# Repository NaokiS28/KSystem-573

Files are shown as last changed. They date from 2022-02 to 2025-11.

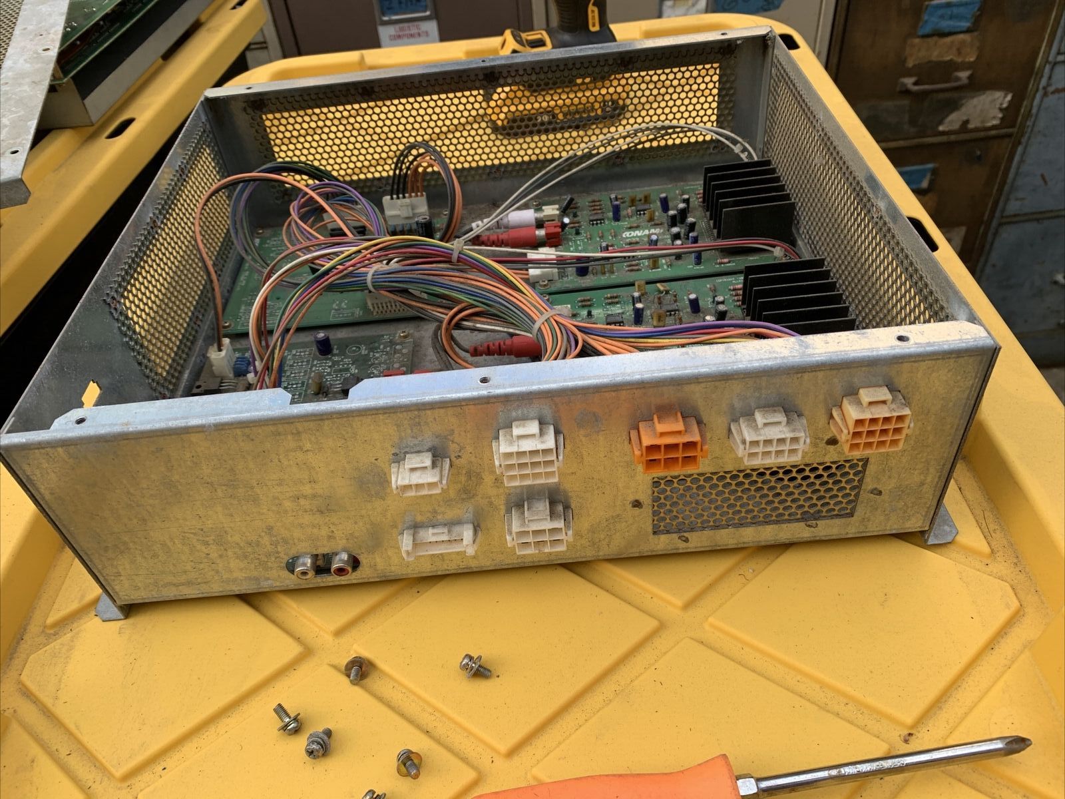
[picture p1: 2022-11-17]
Extra Hardware/DDR Amp Cage/Images/s-l1600-5.jpg

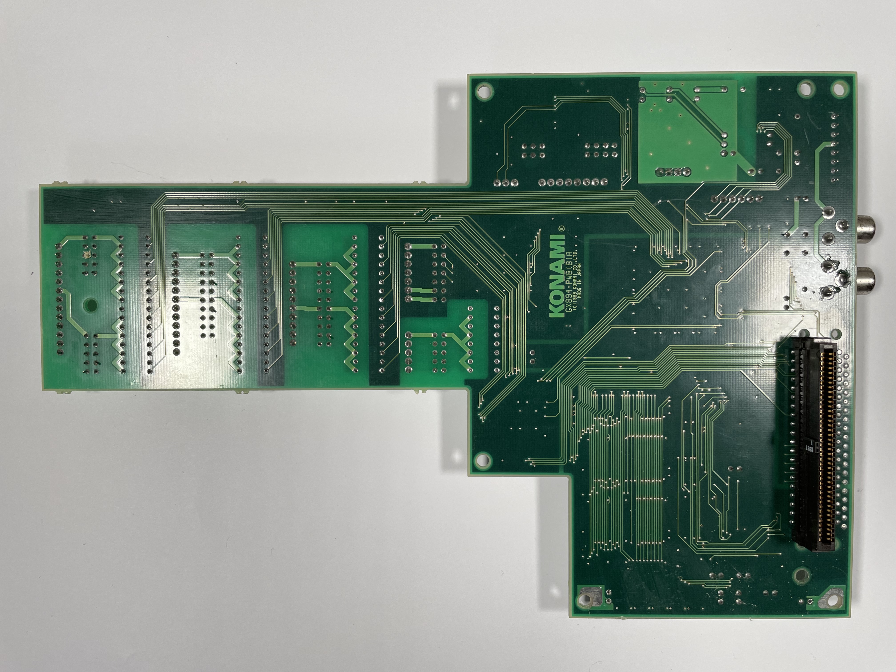
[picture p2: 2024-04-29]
Extra Hardware/Expansion Boards/GX894-PWB(B)A/Images/IMG_5035.jpeg

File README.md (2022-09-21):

# KSystem-573
 Schematics and pinout information for the Konami System 573
 
 **Please note a lot of this data is not 100% complete and might be incorrect in places.** Also this repository needs to be generally organised better.
 
## Schematics
 Schematics are in KiCad format and are preliminary. Currently known issues:
 * The PSX portion is not mapped out. This is the same as the regular PS1 CPU, GPU and SPU schematics with the exception of more work and GPU RAM.
 * The CPLD is mostly but not fully mapped out.
 * The security cart needs verifying and labeling correctly.
 * In general the schematics need tidying up.
 * The Konami 056789 ASIC needs a symbol creating. It's a 6x 16-Bit input and 1x 8-bit output latch really, probably has some 74 series dies on the inside.
 * IO boards are somewhat documented but in varying stages of completeness.

## PCB Layout
 The mother PCB is not laid out. The intention with this project was not to make a new repro motherboard but to define the schematics and wiring. The outline *should* be correct but it is not 100%. If you feel like creating a PCB layout, submit a PR!

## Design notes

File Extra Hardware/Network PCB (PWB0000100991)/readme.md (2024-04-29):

# Konami Network PCB (e-Amusement) (PWB0000100991)

This is board is a seperate PCB from the 573 that is effectively it's own system. It uses a MIPS SoC with a PCI Ethernet 10/100 controller and a 20GB IDE drive. It connects to the 573 via the bottom PCMCIA slot. It is memory mapped only. This unit is used with the GuitarFreaks and Drummania games from 8th mix onwards (at least ones supporting e-Amuse). This would allow the 573 to use downloaded content from Konami's servers and transfer player data.

The OS is UDEOS, an RTOS which has NetNucleus technology from Toshiba.

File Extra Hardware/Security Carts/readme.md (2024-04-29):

# Konami System 573 Security Carts
This folder lists the security carts that were used in the System 573. The security cart port could be considered as a GPIO bus for the 573, having an 8-bit input port, 8-bit output port, semaphore signaling, bitbanged I2C and SPI and a UART port. As a result, a lot of security cartridges tended to be dual purpose and add extra IO to the 573 without using the internal expansion bus.

There are a few types of case styles with the cartridges:
* No case - Bare PCB, sometimes covered with a seperate cover that screws into the 573's silver metal case or has a bespoke metal case covering bother the 573 and cartridge.
* Small case - Small retangular cartridge with a 45 degree angled top. Used on games that only used basic cartridges. Is the same height as the 573 when installed.
* T-Cart - A larger cartridge that extends taller than the 573 when installed and uses most of the width to the side of the cartridge. Typically used on games requiring extra IO.

## Notes:
* It seems almost all cartridges bridge the 573-RTS and 573-CTS UART port lines. If you require the serial port on the 573, just install any old cart and this is done for you.
* Like a lot of Konami parts, they are typically only populated for what the game needs. This means despite the fact that Dancing Stage EuroMIX 2 uses a GE949-PWB(D)A cartridge, none of the extra parts to support the AMP control or RS232 ports (except the RTS-CTS link) are present. DDR 3rdMIX seems to be a rare exception in this case.
* All carts a fully reprogramable to have *any* other cart data. The only exception is that carts using a Xicor EEPROM can only be used on games expecting a Xicor cart and vice versa with the PIC16C carts, also known as ZS01 carts - That said, some games might be able to use both cart types, but this is not confirmed. Dancing Stage EuroMIX has strange behavoir in that it will inform the operator to label the cart like it would on ZS01 carts, but it does not actually marry the cart.

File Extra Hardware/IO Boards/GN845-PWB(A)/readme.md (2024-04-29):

# GN845-PWB(A) - Relay Board
This PCB is also known as the Relay board sometimes, it is used on DDR/Dancing Stage and possibly other BEMANI games like Drummania and Guitar Freaks.
Update: It appears the board was used in the following games:
* Dance Dance Revolution / Danicng Stage
* Punch Mania / Fighting Mania
* Guitar Freaks
* Drummania

First used with DDR, it has space for two logic inverters for up to 8 channels (altough DDR only has pats for 6 channels) of high current outputs like the 12v halogen spotlamps on the marquee and the 501 lamps in the start and select buttons. The neon tube driver *does not* go through this board, it uses a separate solid-state relay (SSR) to drive the neon transformer.

The secondary logic chip and associated components are not used or populated in DDR. It drives the last two MOSFETs/Darlington pair transistors, a space for lower current drivers using NPN transistors and then finally two opto-isolator outputs. It's not known what these were originally intended for nor if any game would have ever likely used them.

The board is setup to use both N-Channel MOSFETs and NPN Darlington pair transistors, with R9-R16 being the only components needing to be changed. A straight link (0-ohm/wire) is used for MOSFETs and a resistor for NPN Darlington transistors. The board is only designed to handle 12V swtiching. It has an onboard 7805 5V regulator for the logic ICs.

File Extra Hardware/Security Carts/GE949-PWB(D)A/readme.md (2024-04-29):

# GE949-PWB(D)A - Security Cart w/ RS232 Transceiver & Audio amp control
Sometimes known as a T-Cart cart, this PCB is used as both a security cartridge, a galvanically isolated amplifier controller board and an isolated RS232 transceiver for linking units together. It uses a PIC16CE625 MCU as the security device which is often called the ZS01 security chip due to the initial bytes of the internal code at address `0x0000`. This board provides a galvanically isolated 5V supply to the amp control header. It's very similar to the GX896 security cart but also includes a DS2401 serial ID chip to make every security cartridge unique.

## Games used in:
* DDR 4thMIX
* DDR 5thMIX
* DDRMAX
* DDRMAX 2
* DDR Extreme
* Dancing Stage EuroMIX 2
* Almost all BEMANI games post the 3rd quarter of 2000.

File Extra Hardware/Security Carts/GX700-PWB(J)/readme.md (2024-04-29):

# GX700-PWB(J) - Security Cart w/ 8 Channel ADC
This PCB is used as both a security cartridge and analog input expansion board. It uses a Xicor x76F041 password eeprom as the security device. The analogue to digital converter is an ADC0838 which is an 8 channel version of the one used on the 573 motherboard.

## Games used in:
* Fighting Mania
* Punch Mania
* Punch Mania II

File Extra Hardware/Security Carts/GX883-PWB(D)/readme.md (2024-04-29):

# GX896-PWB(A)A - Security Cart w/ RS232 Transceiver & Audio amp control
Sometimes known as a T-Cart cart, this PCB is used as both a security cartridge, a galvanically isolated amplifier controller board and an isolated RS232 transceiver for linking units together. It uses a Xicor x76F041 password eeprom as the security device. This board provides a galvanically isolated 5V supply to the amp control header. It's practically the same as the GX896 security cart but also includes a DS2401 serial ID chip to make every security cartridge unique.

## Games used in:
* DDR 3rdMIX
* GuitarFreaks 2ndMIX 
* Probably other BEMANI digital games prior to late 2000s.

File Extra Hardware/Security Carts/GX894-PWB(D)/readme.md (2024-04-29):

# GX896-PWB(A)A - Security Cart w/ unique serial number
This PCB is used as a security cartridge. It uses a Xicor x76F041 password eeprom as the security device. It also has a DS2401 serial ID chip so that each security cart has a unique ID.

Curiously, in Dancing Stage EuroMIX, it tells the operator to write an 8-digit security number onto the game PCB and the security cart as if it had married the (blank) cart to the motherboard, however it does not actually marry the boards at all. It's not as if it couldn't, it just doesn't seem to or atleast it doesn't lock you out if the cart is used in another board.

## Games used in:
* Dancing Stage EuroMIX

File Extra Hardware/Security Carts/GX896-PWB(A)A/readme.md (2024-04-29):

# GX896-PWB(A)A - Security Cart w/ RS232 Transceiver & Audio amp control
Sometimes known as a clubMIX cart, this PCB is used as both a security cartridge, a galvanically isolated amplifier controller board and an isolated RS232 transceiver for linking units together. It uses a Xicor x76F041 password eeprom as the security device. This board provides a galvanically isolated 5V supply to the amp control header.

## Games used in:
* Drummania
* DDR 2ndMIX with beatmania IIDX club ver.
* DDR 2ndMIX and beatmania IIDX substream CLUB ver. 2

Images provided by BigDadDewg.

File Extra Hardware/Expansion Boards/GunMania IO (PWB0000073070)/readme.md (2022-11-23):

# GunMania IO Board (PWB0000073070)

This is board is the IO board used with GunMania and likely GunMania II. As the game uses real BB bullets and has an actual shooting range, this board serves as mostly a drive board, altough also appears to have a serial port (or maybe ACIO), an a DB25 connector. The board hasn't been documented fully.

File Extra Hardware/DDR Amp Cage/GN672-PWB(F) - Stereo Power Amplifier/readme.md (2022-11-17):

# GN672-PWB(F) - Stereo Audio AMP
This PCB is simply an stereo audio amp. Todo: add specifications. Likely just dual 20w/40w amplifier.

Dance Dance Revolution/Dancing Stage uses two of these PCBs: One for the full range drivers and another for the subwoofers (this amp receives an LFO channel input).

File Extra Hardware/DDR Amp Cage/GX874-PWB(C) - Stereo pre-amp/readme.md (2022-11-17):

# GN874-PWB(C) - Audio Mixing PCB
This PCB is simply an audio mixing PCB. It takes two inputs, merges them together and then splits into two full range outputs (one going to the output of the cabinet at the back) and a stereo LFO channel. The potentiometers for controlling volumes connects to this PCB. There is a 4 pin connector by the inputs that might be another input but it's not known if this was ever used. Also there is a third output which is positioned to be connected to another GN672 amplifier but it's not populated on most boards.

It's using basic NE5532 circuits powered from a 7805 5V regulator.

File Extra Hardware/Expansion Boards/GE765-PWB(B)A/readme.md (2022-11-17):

# GE675-PWB(B)A - Fishing Reel IO
This is the Reel IO controller board for the Fisherman's Bait series of games. It is an internal expansion IO board that has an external IO connector. It uses a typical mouse encoder chip to translate the reel spool and has a feedback drive for the spool clutch to add resistance to turning.

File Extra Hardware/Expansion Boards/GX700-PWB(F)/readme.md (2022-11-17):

# GX700-PWB(F) - Analogue IO
This PCB is also known as the analogue IO board. Really speaking, it's just a 30 output driver board and has nothing to do with analogue data or audio. Given the code name, it was possibly designed at the same time the System 573 was (as the mainboard is labelled GX700-PWB(A-C)) so is not DDR specific, and has been used on other games like Fighting/Punch Mania.

It consists of a 16V8 PAL, 1x 74LS245 for converting the 3.3v PSX bus to 5v and 3x 74LS273s and a 74LS175 acting as output latches. It has a very basic function, you write a byte to a corrosponding point in memory and it gets latched to the outputs. (todo: add locations).

The logic chips drive PC817 opto-isolators which are protected by capacitors (10nf) and line filters (10nf LCL).

The PAL is not yet dumped, but on my todo list.

## Part Population
The IO board is almost never fully populated and most games will only have the output drivers populated for the outputs it needs.

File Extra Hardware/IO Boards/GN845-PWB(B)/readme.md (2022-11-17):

# GN845-PWB(B) - Stage IO
This PCB is also known as the Stage IO board. It lives in either the top right or top left corner of the stage pads in Dance Dance Revolution/Dancing Stage and serves as a multiplexor and driver board for the stage neons. It's only used in DDR doubles cabs, DDR Solo does not use a multiplexor as it only uses two sensors per pad (vs DDR doubles' 4) and directly connects all sensors to the JAMMA connector. The JAMMA stick UDLR pins are connected to the Stage IO board, with U and R serving as inputs for the multiplexor data as well during boot and diagnostics.

Curiosly, the Stage IO is only ever populated for 4 arrows but an entire 5th section is on the PCB and routed out, so maybe DDR might have been a 5 panel game? This was before Pump-It-Up was released so it's interesting that perhaps the center panel might have originally been an input.

Power wise, the board receives a 12V input which is then connected to a 7805 to get local 5V regulated power.

## Function
The Stage IO is not exactly required in the sense that normal gameplay in DDR does not use nor care for the multiplexing of the Stage IO, it uses the direct JAMMA stick inputs for the arrows. That said the game *does* clock the Stage IO's serial bus during gameplay but it's not fully known why as grounding one of the pins (todo: which?) will enable the pad output anyway.

### Arrow Sections
Each arrow has it's own NPN darlington pair transistor, 74HC14 inverter and passives. The transistor is used for the neon drivers that light up the arrow panel. All sensors and the NPN transistor go through the logic inverter and then into the CPLD.

### CPLD
The CPLD has pullups on it's inputs after line filters (10nf LCL filters) that go through a resistor network. The inputs are also protected by a zener diode arrays to ground and to power. The outputs are protected by opto-isolators, the same PC817 chips that Konami used everywhere else.

The CPLD itself is not yet fully understood. It's known that all Stage IOs use a synchronous serial bus over 4 wires, two of which are inputs and driven by the System 573's opto-isolated outputs on the analogue or digital IO board. The other two lines share the U and R pins with the JAMMA connector. 

The serial protocol is **ludicrously slow**, it takes about 200ms(!) to transmit a complete message. The bus is full-duplex, like SPI, the 573 will receive data as it is being sent. The first packet is a mirror of what the 573 sends, the latter half has all of the sensor data (4x4 so 16 sensors) and the 573 can optionally disable individual sensors from use, probably to avoid a stuck input but this isn't used in gameplay.

The protocol will be documented here when it is more fully understood.

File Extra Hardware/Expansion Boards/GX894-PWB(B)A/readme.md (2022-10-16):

# Konami 573 Digital Audio I/O Board (GX894)

This is the IO board that is mostly used with Bemani rhythm games. It uses a SPARTAN FPGA, Xilinx XC9536 CPLD and MAS3507D MP3 audio decoder IC withh a bunch of RAM, opto-isolators and trasceivers thrown in for good measure. The board is practically useless without an FPGA binary blob uploaded to it as nothing is accessible otherwise. This is uploaded by the game at the game's boot (and will show "Digital I/O init failure" if it can't.).

There's a dual RS232 port on the board but it seeminly went unused. There's also I2S audio output so it would be possible to capture the digital audio from the cab (and from the mainboard too) and convert to SPDIF or TOSLINK.

FWIW, the FPGA Blob that Konami uses is stored in 128k of SRAM and has a decryption engine built in that feeds data to the MAS chip, so you would need to encrypt any audio to be played back to use Konami's blob. Otherwise you could create a alternate blob that didn't require this and just use MP3 data stored in the 12 megabytes (!) of EDO RAM on the board.

There is Konami's multidrop networking bus and interface present on the board but more needs to be understood about this before it can be documented fully.

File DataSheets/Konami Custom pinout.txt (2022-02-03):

GND
P2-B1
P2-B2
P2-B3
P2-Start
Coin 1
Coin 2
PCMCIA Inserted 1
PCMCIA Inserted 2
P1-B4
GND
P1-B5
P2-B4
P2-B5
Service
5V
??
??
P1-B6
P2-B6
GND
DIP1
DIP2
DIP3
DIP4
H8-Pin 12
H8-Pin 13
H8-Pin 14
H8-Pin 15
Security cart Pin 40? (Cart inserted?)
GND
Security cart Pin 39
Security cart Pin 38
Security cart Pin 37
Security cart Pin 36
Security cart Pin 35 (And pullup on RA27)
Security cart Pin 34
Security cart Pin 33
H8 Pin 25
GND
H8 Pin 27
H8 Pin 28
H8 Pin 29
H8 Pin 30
5V
H8 Pin 31
H8 Pin 32
H8 Pin 17
H8 Pin 18
GND
H8 Pin 19
H8 Pin 20
H8 Pin 21
H8 Pin 22
H8 Pin 23
H8 Pin 24
H8 Pin 2
Test Button
???
5V
GND
Data 0: 22E Pin 3 (74LS273) & 26E (74LS74) pin 2 & 22G ROM Pin 13
Data 1: 22E Pin 4 (74LS273) & 22G ROM Pin 14
Data 2: 22E Pin 7 (74LS273) & 22G ROM Pin 15
Data 3: 22E Pin 8 (74LS273) & 22G ROM Pin 17
Data 4: 22E Pin 13 (74LS273) & 22G ROM Pin 18
Data 5: 22E Pin 14 (74LS273) & 22G ROM Pin 19
Data 6: 22E Pin 17 (74LS273) & 22G ROM Pin 20
Data 7: 22E Pin 18 (74LS273) & 22G ROM Pin 21
Data 8?: 22D (74LS273) Pin 3 & 26E (74LS74) pin 12 & Flash ROM bank Pin 31 (DQ0)
GND
Data 9?: 22D Pin 4 & Flash ROM bank Pin 32 (DQ1)
Data 10?: 22D Pin 7 & Flash ROM bank Pin 33 (DQ2)
Data 11?: 22D Pin 8 & Flash ROM bank Pin 34 (DQ3)
Data 12?: 22D Pin 11 & Flash ROM bank Pin 38 (DQ4)
Data 13?: 22D Pin 12 & Flash ROM bank Pin 39 (DQ5)
Data 14?: 22D Pin 7 & Flash ROM bank Pin 40 (DQ6)
Data 15?: 22D Pin 4 & Flash ROM bank Pin 41 (DQ7)
ADC Pin 13 Data In 
ADC Pin 12 CLK
GND
ADC Pin 2 !CS 24D (ADC0834) 
Konami Custom 058232/058460 Pin 11
Konami Custom 058232/058460 Pin 10
5V
24E (74LS14) Pin 10
32D (SM5877AM) Pin 1 (Mute)
??
ADC Pin 10 Data Out
RESET: 22E Pin 1 (74LS273) & 22D (74LS273) Pin 1 & 27F&G (74LS273) Pin 1 & 26E (74LS74) Pin 1&13 & 32D Pin 22 & Flash ROMs Pin 14
GND
ADC Pin 11 SARS
Security Cart Pin 20
JVS-Sense Input (High = No IO, Low = IO connected)
??
??
Security Cart Pin 97
??
5V
26E (74LS74) Pin 11 & Somewhere around ROM and RTC
GND
??
Address 1: A1 of BIOS ROM 10 & A0 Flash Bank Pin 30 (Not RTC?)
Address 2: A2 of BIOS ROM 9 & A1 Flash Bank Pin 29
Address 3: A3 of BIOS ROM 8 & A2 Flash Bank Pin 28
5V
P1 Left
P1 Right
P1 Up
P1 Down
GND
P1 Button 1
P1 Button 2
P1 Button 3
P1 Start
P2 Left
P2 Right
P2 Up
P2 Down
5V

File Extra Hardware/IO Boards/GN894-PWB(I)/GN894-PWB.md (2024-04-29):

## GN894-PWB(I)

This PCB is a light output PCB that was used in the Dance Dance Revolution (DDR) Solo series  of games. As part of the deviance from a typical DDR cabinet, DDR Solo has 4 output connectors for switching AC line loads. In the manual these are labelled as use for external lamps and in the deluxe stage models, they used mains rated lamps in the 8 side lamps.

**It should go without warning that mains AC voltage can kill. Please do not work on this PCB or be near exposed metal connections on the PCB whilst the cabinet is turned on and live.**

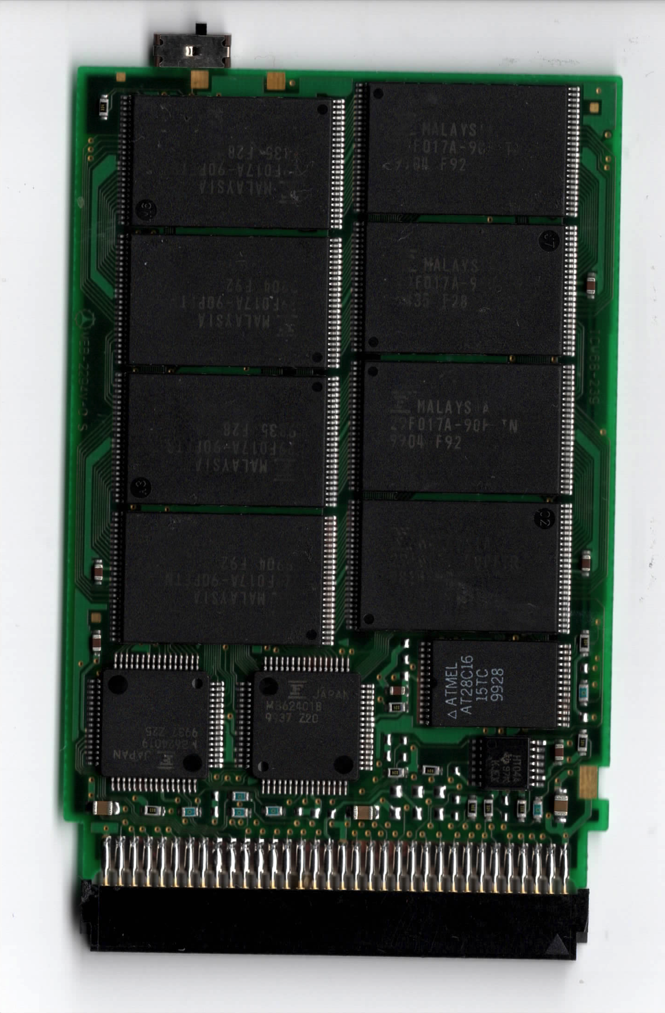
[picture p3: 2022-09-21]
Schematics (KiCad)/Konami Flash Card/Images/Font.png

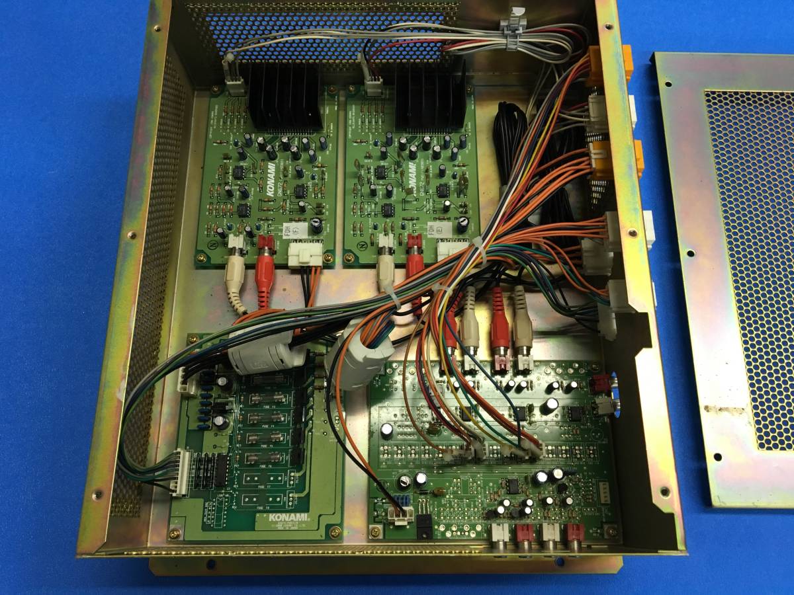
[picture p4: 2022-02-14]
Extra Hardware/DDR Amp Cage/Images/i-img1200x900-1629526253fmnhzg10197.jpg

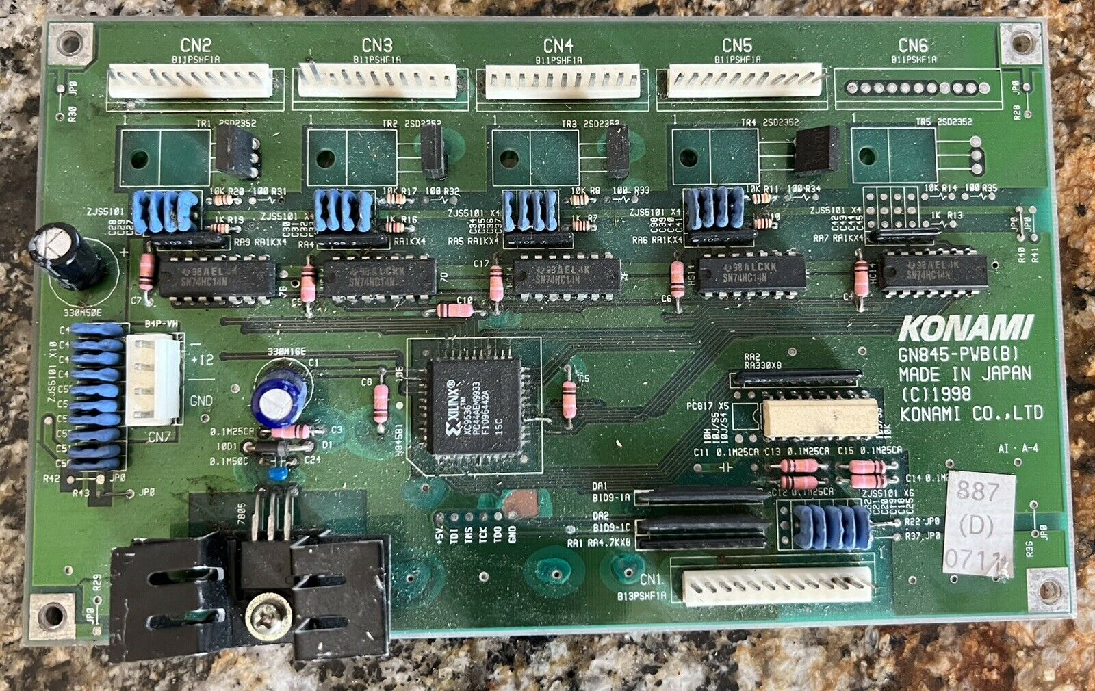
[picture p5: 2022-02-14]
Extra Hardware/IO Boards/GN845-PWB(B)/Images/s-l1600.jpg

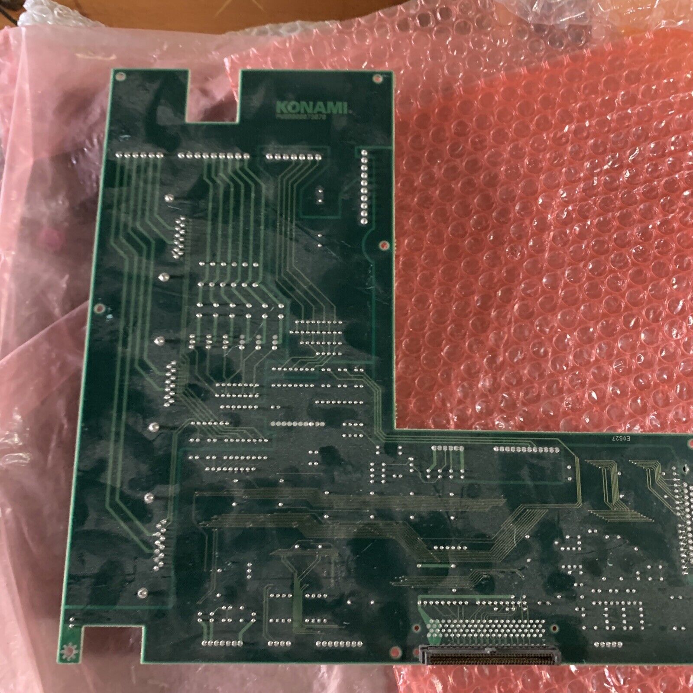
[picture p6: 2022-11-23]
Extra Hardware/Expansion Boards/GunMania IO (PWB0000073070)/Images/s-l1600-3.jpg

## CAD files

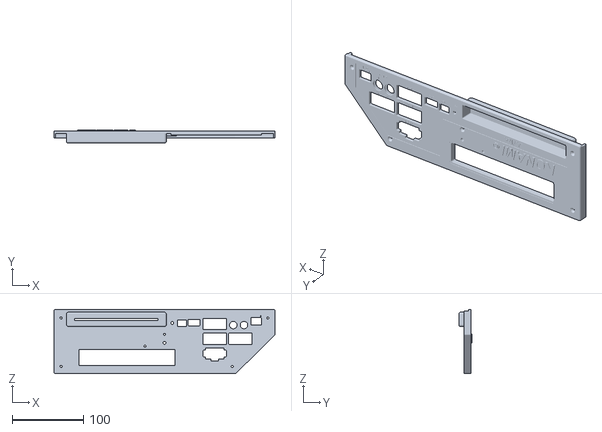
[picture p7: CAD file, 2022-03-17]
3D Designs/Faceplate v1.stl
310.0 x 18.0 x 90.0

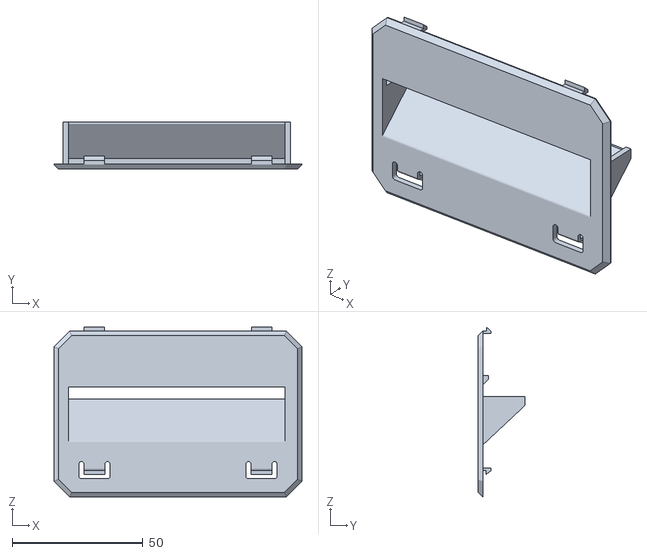
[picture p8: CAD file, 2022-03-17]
3D Designs/Cart Slot V1.stl
95.0 x 18.0 x 65.0

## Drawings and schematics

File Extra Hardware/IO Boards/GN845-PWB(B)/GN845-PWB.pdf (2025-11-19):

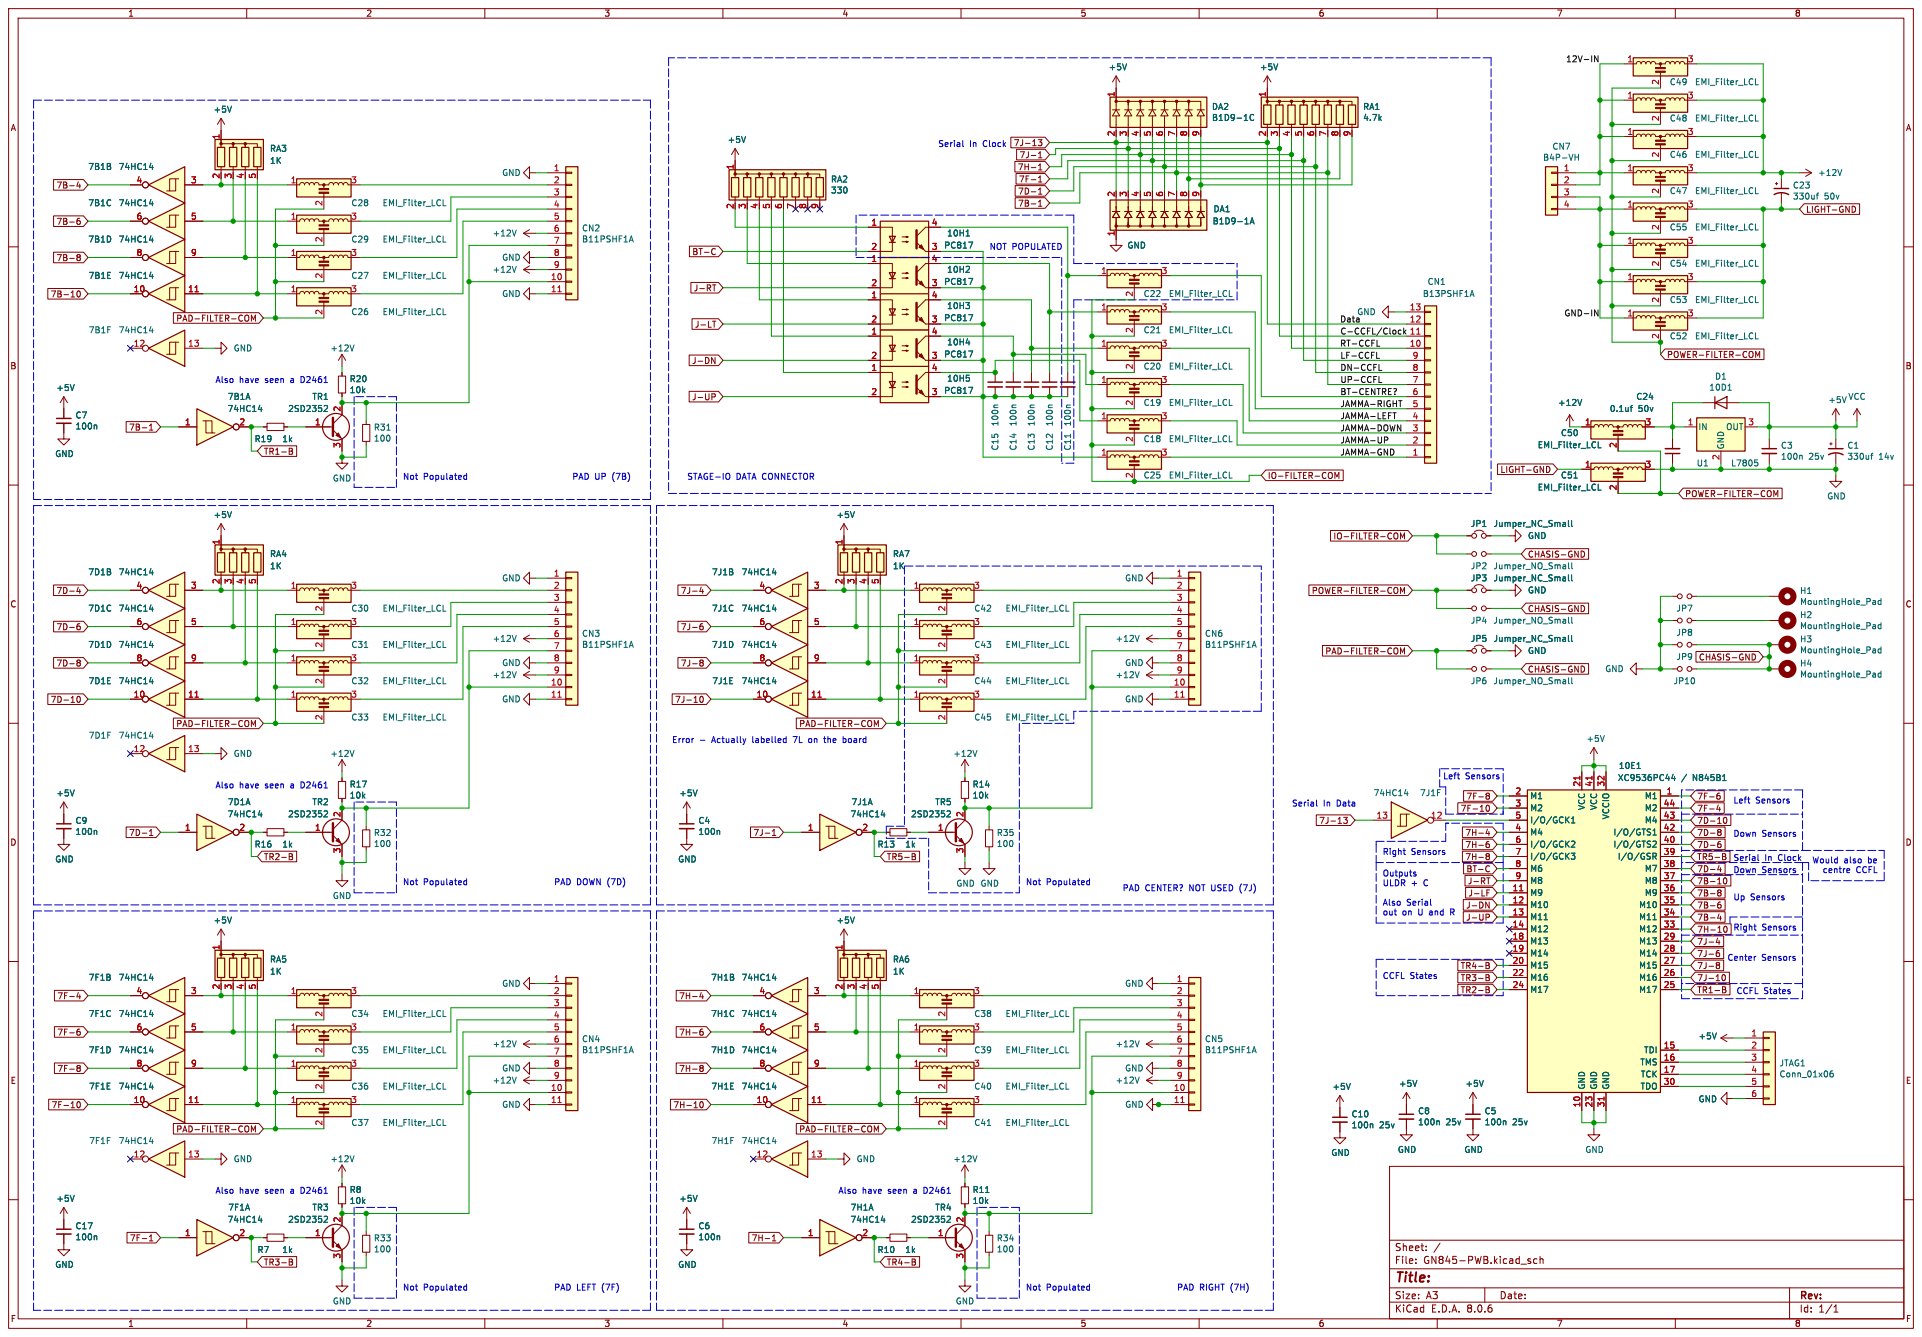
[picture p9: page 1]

Serial In Clock NOT POPULATED

Serial In Data PAD RIGHT (7H) Not Populated

Right Sensors Not Populated

Up Sensors CCFL States Outputs ULDR + C

Also Serial out on U and R

Right Sensors PAD LEFT (7F)

Id: 1/1 Title: File: GN845-PWB.kicad_sch Sheet: /

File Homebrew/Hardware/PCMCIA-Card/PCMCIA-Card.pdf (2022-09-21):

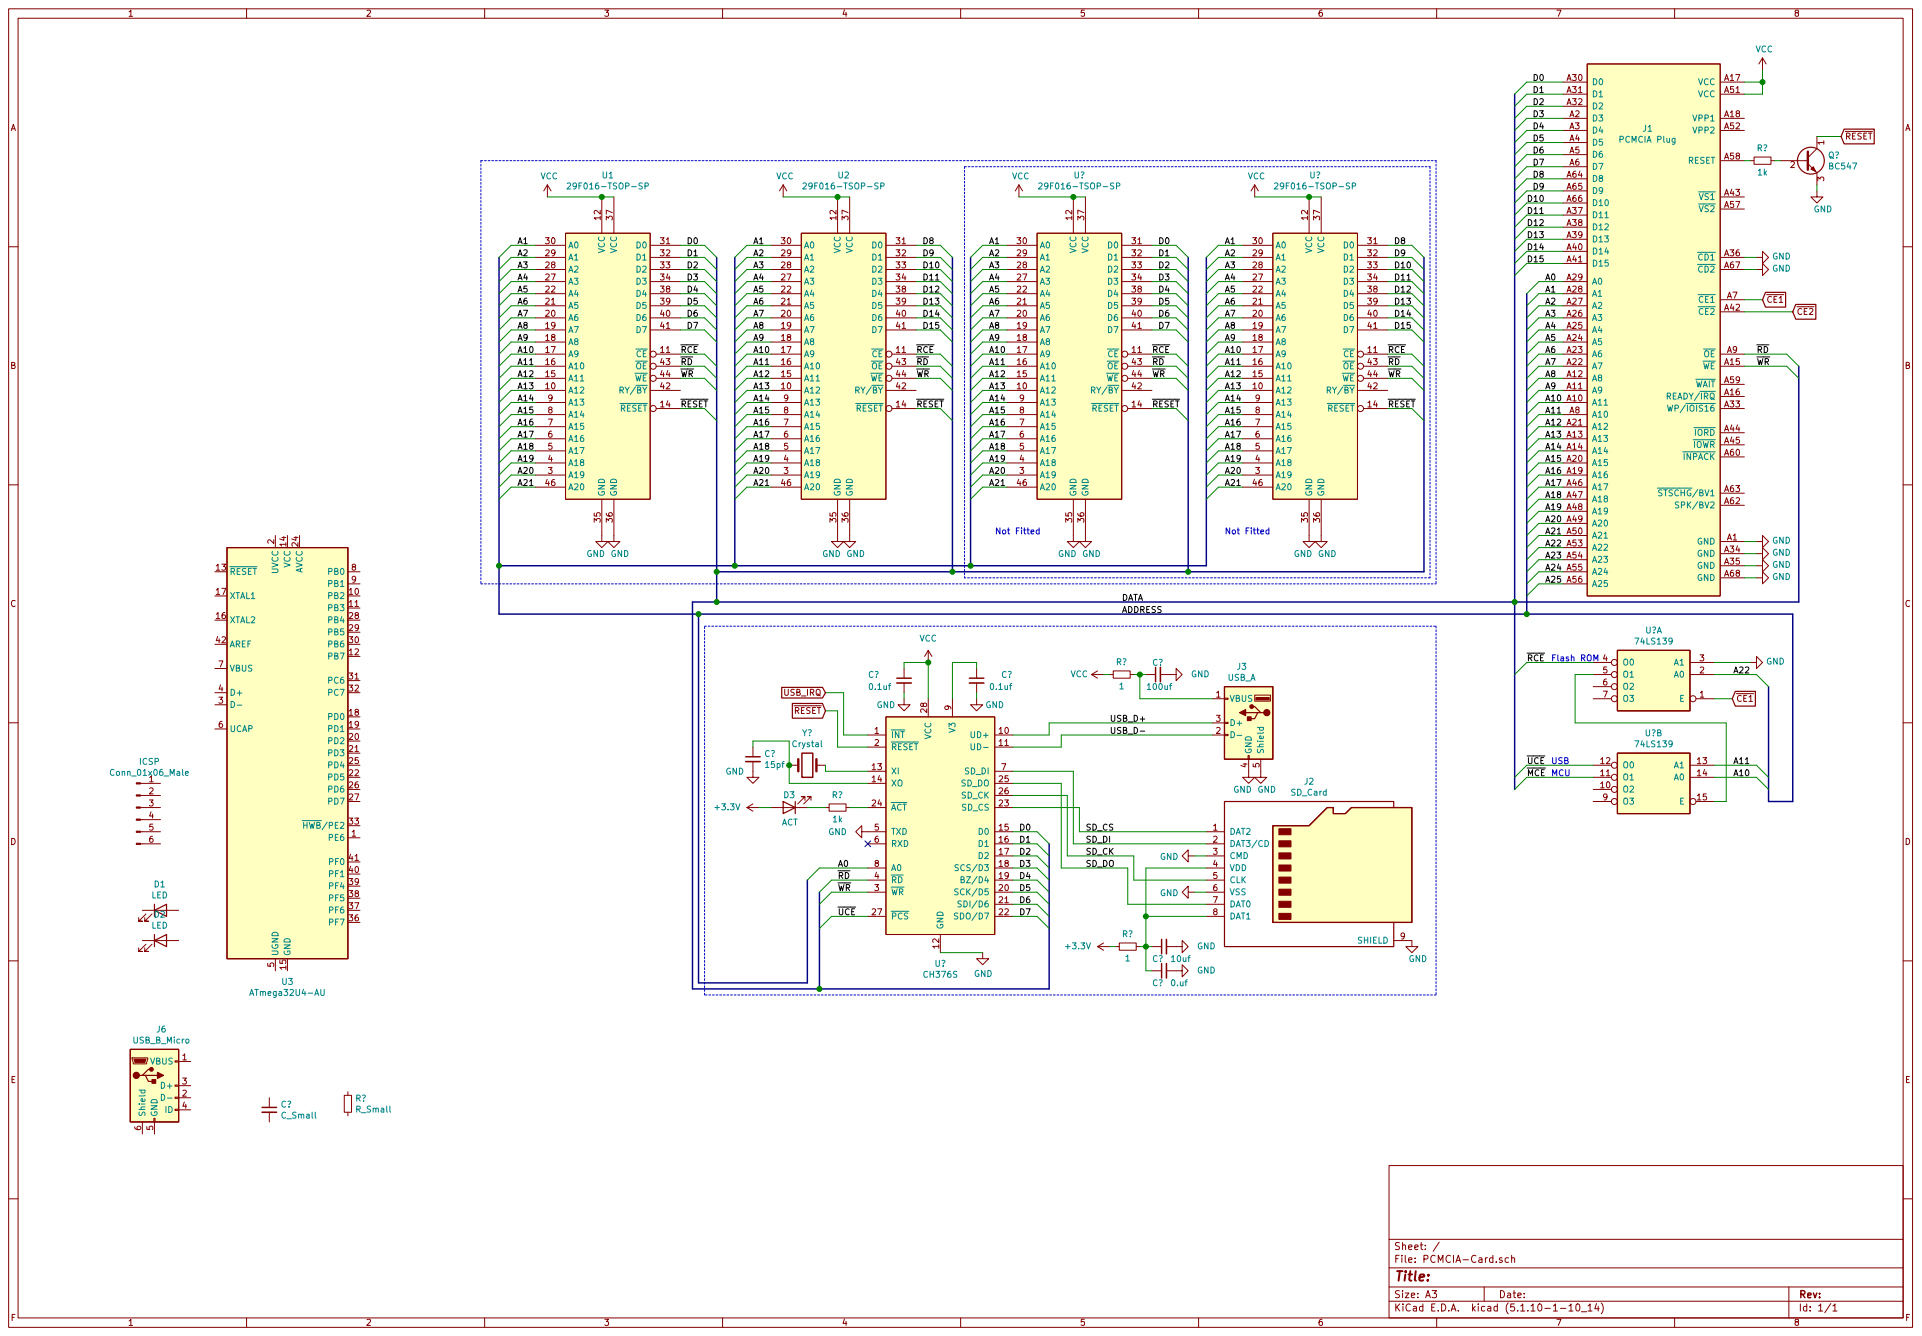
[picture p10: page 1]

2 PD2 20 PD3 21 PD5 22 AVCC 24 PD4 25 PD6 26 PD7 27 PB4 28 PB5 29 D- 3 PB6 30 PC6 31 PC7 32 HWB/PE2 33 PF7 36 PF6 37 PF5 38 PF4 39 D+ 4 PF1 40 PF0 41 AREF 42 UGND

9 U? CH376S GND GND GND GND

Id: 1/1 Title: File: PCMCIA-Card.sch Sheet: /

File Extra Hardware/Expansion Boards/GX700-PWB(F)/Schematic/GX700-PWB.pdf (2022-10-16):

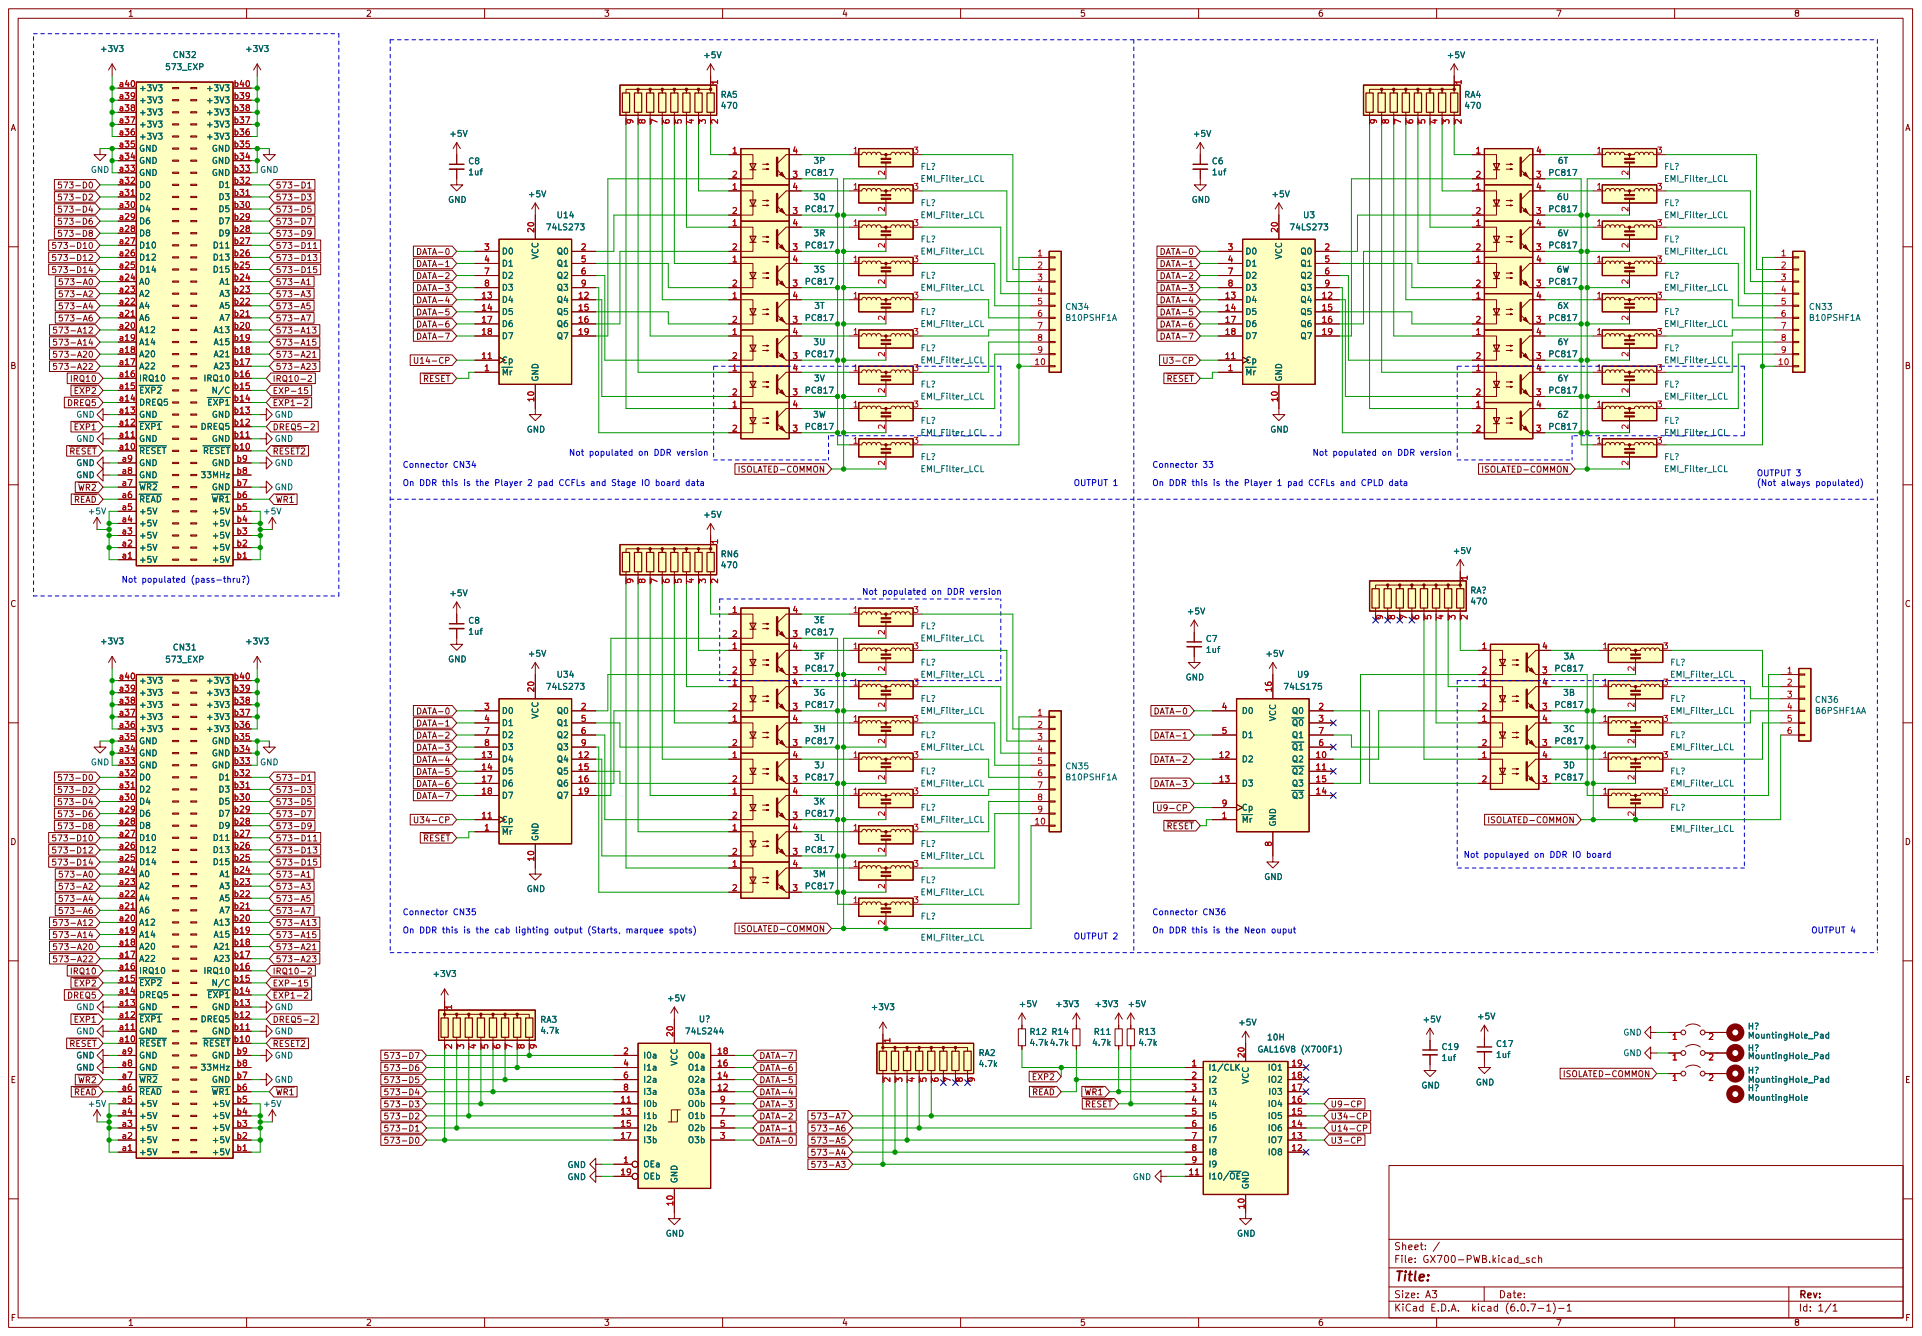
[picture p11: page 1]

~{RESET} DATA-4 DATA-2 DATA-0

DATA-5 DATA-7 ~{RESET} DATA-4 DATA-6

DATA-1 DATA-3 DATA-2 DATA-0

Not populated on DDR version

Not populayed on DDR IO board OUTPUT 2

On DDR this is the cab lighting output (Starts, marquee spots)

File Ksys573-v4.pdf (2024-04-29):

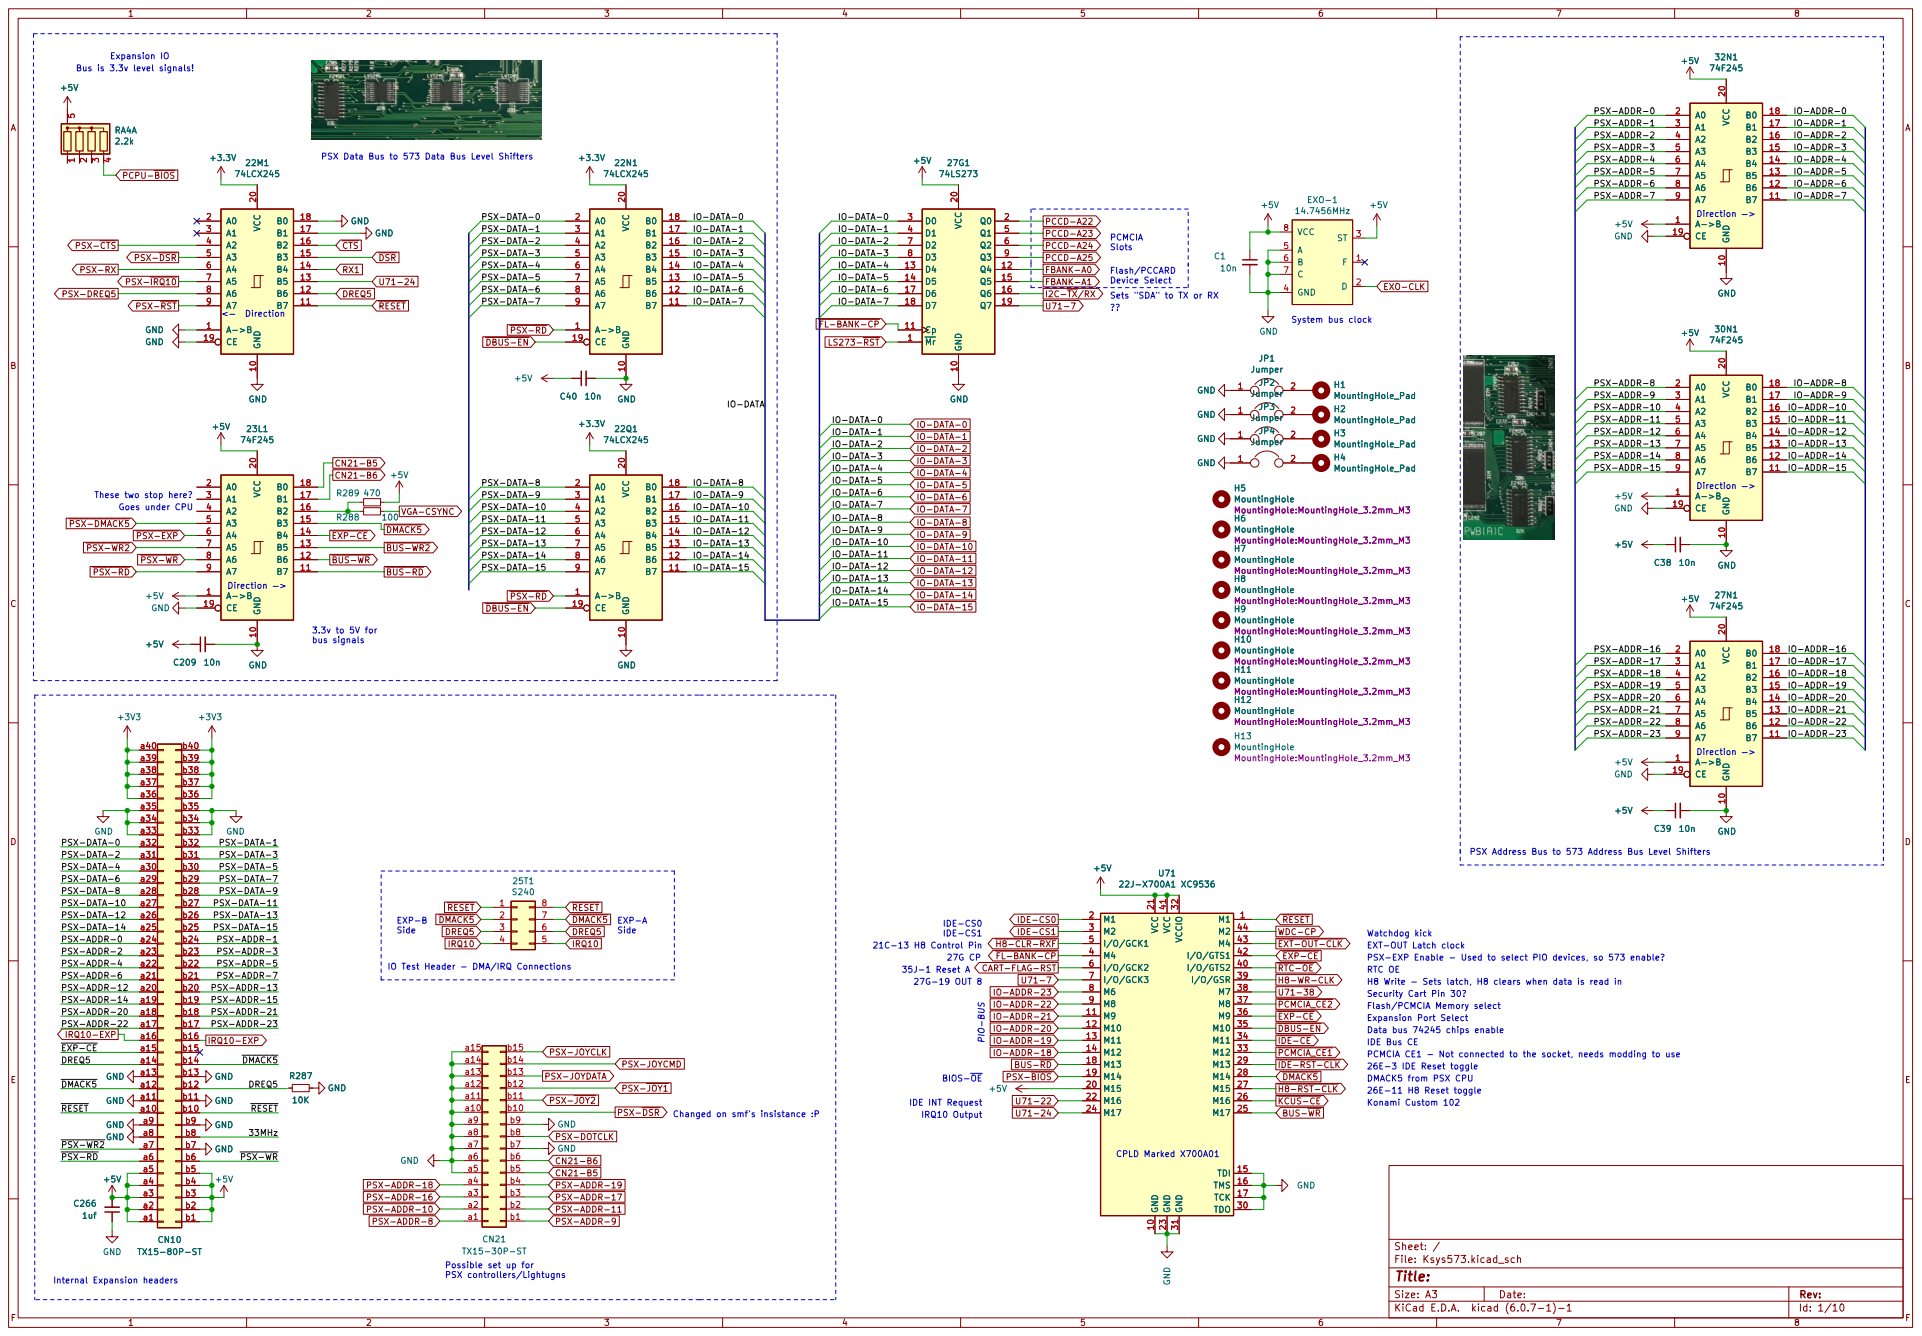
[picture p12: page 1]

Expansion IO
Bus is 3.3v level signals!

IO-DATA-4 PSX-DATA-2 PSX-DATA-3 PSX-DATA-0 PSX-DATA-4 PSX-DATA-1

PSX-DATA-7 PSX-DATA-6 PSX-DATA-5

Device Select
Sets "SDA" to TX or RX

+5V GND
PSX-ADDR-8 PSX-ADDR-13 PSX-ADDR-1 PSX-ADDR-5 PSX-ADDR-21 PSX-ADDR-23 ~{DMACK5} 33MHz ~{PSX-WR}

PSX-ADDR-17 PSX-ADDR-16 PSX-ADDR-15

PSX-ADDR-11 PSX-DATA-13 PSX-DATA-11 PSX-DATA-15 PSX-ADDR-3

IO-DATA-5 PSX-DATA-14 DREQ5
PSX-DATA-9 PSX-DATA-8 PSX-DATA-12 PSX-DATA-13 PSX-DATA-11 PSX-ADDR-20 PSX-ADDR-14

These two stop here?

PSX-DATA-14 PSX-DATA-10 PSX-DATA-7 PSX-DATA-1

IO-DATA-13 PSX-ADDR-7 PSX-ADDR-13 PSX-ADDR-15

IO-DATA-14 PSX-DATA-0

3.3v to 5V for bus signals

IO-ADDR-17 PSX-DATA-6

IO-ADDR-18 PSX-DATA-3 PSX-DATA-9

PSX-ADDR-18 BIOS-~{OE}

IO-ADDR-21 PSX-ADDR-12 ~{EXP-CE} PSX-ADDR-22 PSX-DATA-8 PSX-DATA-10

PSX-ADDR-6 PSX-DATA-12

EXP-B
~{EXT-OUT-CLK} PSX-ADDR-8 PSX-ADDR-10

Watchdog kick RTC OE

PSX-ADDR-4 PSX-ADDR-2

IO Test Header - DMA/IRQ Connections

~{RTC-OE}
~{EXP-CE} U71-38 H8-WR-CLK

Security Cart Pin 30?
Flash/PCMCIA Memory select
Expansion Port Select
Data bus 74245 chips enable
IDE Bus CE
26E-11 H8 Reset toggle Konami Custom 102 PCMCIA CE1 - Not connected to the socket, needs modding to use
26E-3 IDE Reset toggle
DMACK5 from PSX CPU

PSX-~{DSR} PSX-JOYCMD

Possible set up for
PSX controllers/Lightugns

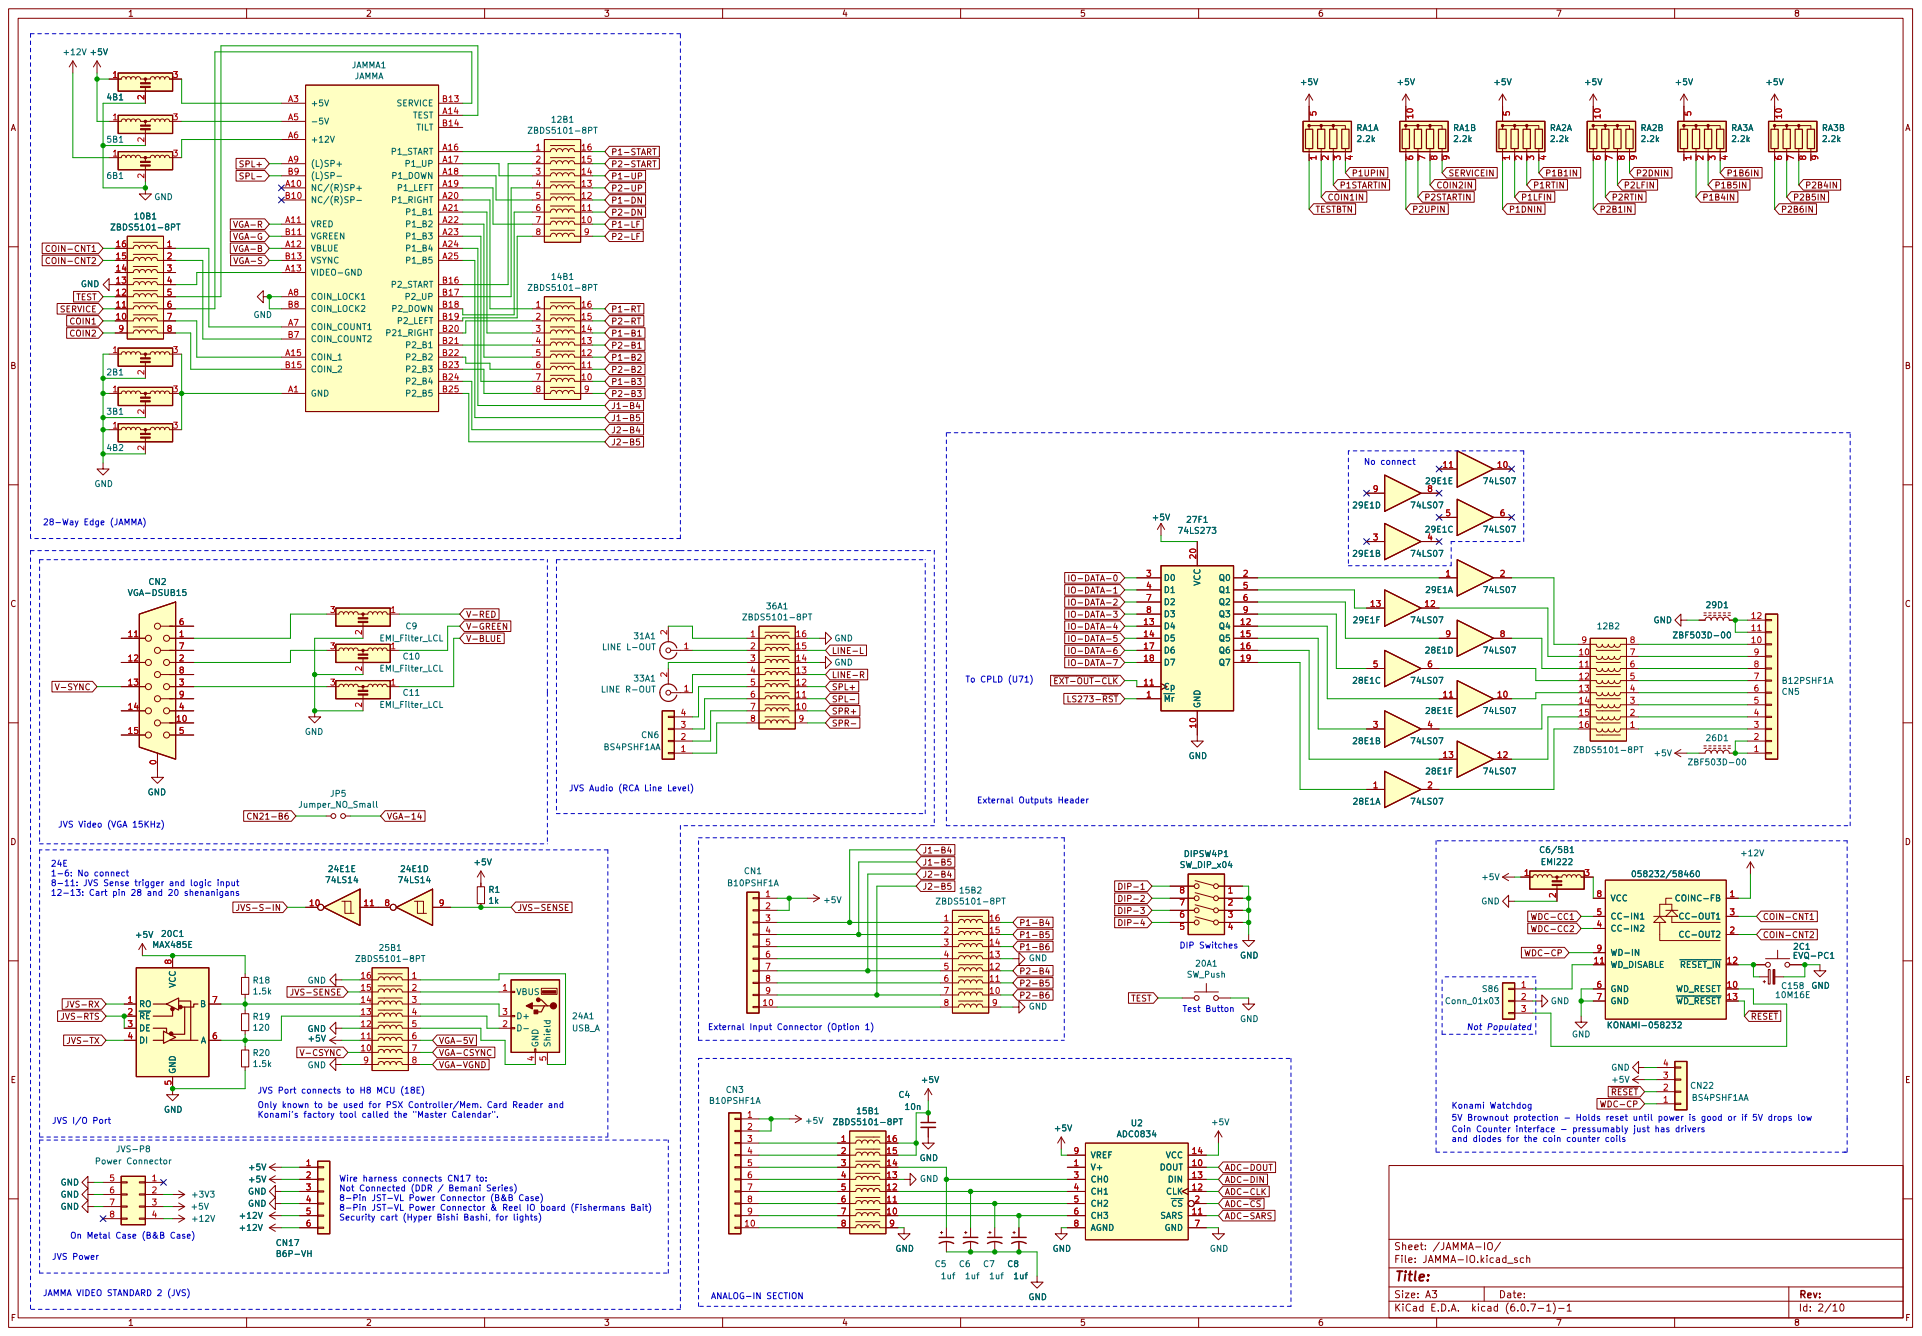
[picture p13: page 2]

DIP Switches Test Button External Outputs Header

JVS Port connects to H8 MCU (18E) 24E
1-6: No connect 8-11: JVS Sense trigger and logic input

12-13: Cart pin 28 and 20 shenanigans

Only known to be used for PSX Controller/Mem. Card Reader and
Konami's factory tool called the "Master Calendar". Wire harness connects CN17 to: Not Connected (DDR / Bemani Series)

Konami Watchdog
Coin Counter interface - pressumably just has drivers and diodes for the coin counter coils 5V Brownout protection - Holds reset until power is good or if 5V drops low

On Metal Case (B&B Case) JVS Power JVS I/O Port JAMMA VIDEO STANDARD 2 (JVS)

ADC-DOUT
ADC-~{CS} ADC-DIN
ADC-CLK

8-Pin JST-VL Power Connector (B&B Case)
8-Pin JST-VL Power Connector & Reel IO board (Fishermans Bait)
Security cart (Hyper Bishi Bashi, for lights)

File: JAMMA-IO.kicad_sch Sheet: /JAMMA-IO/

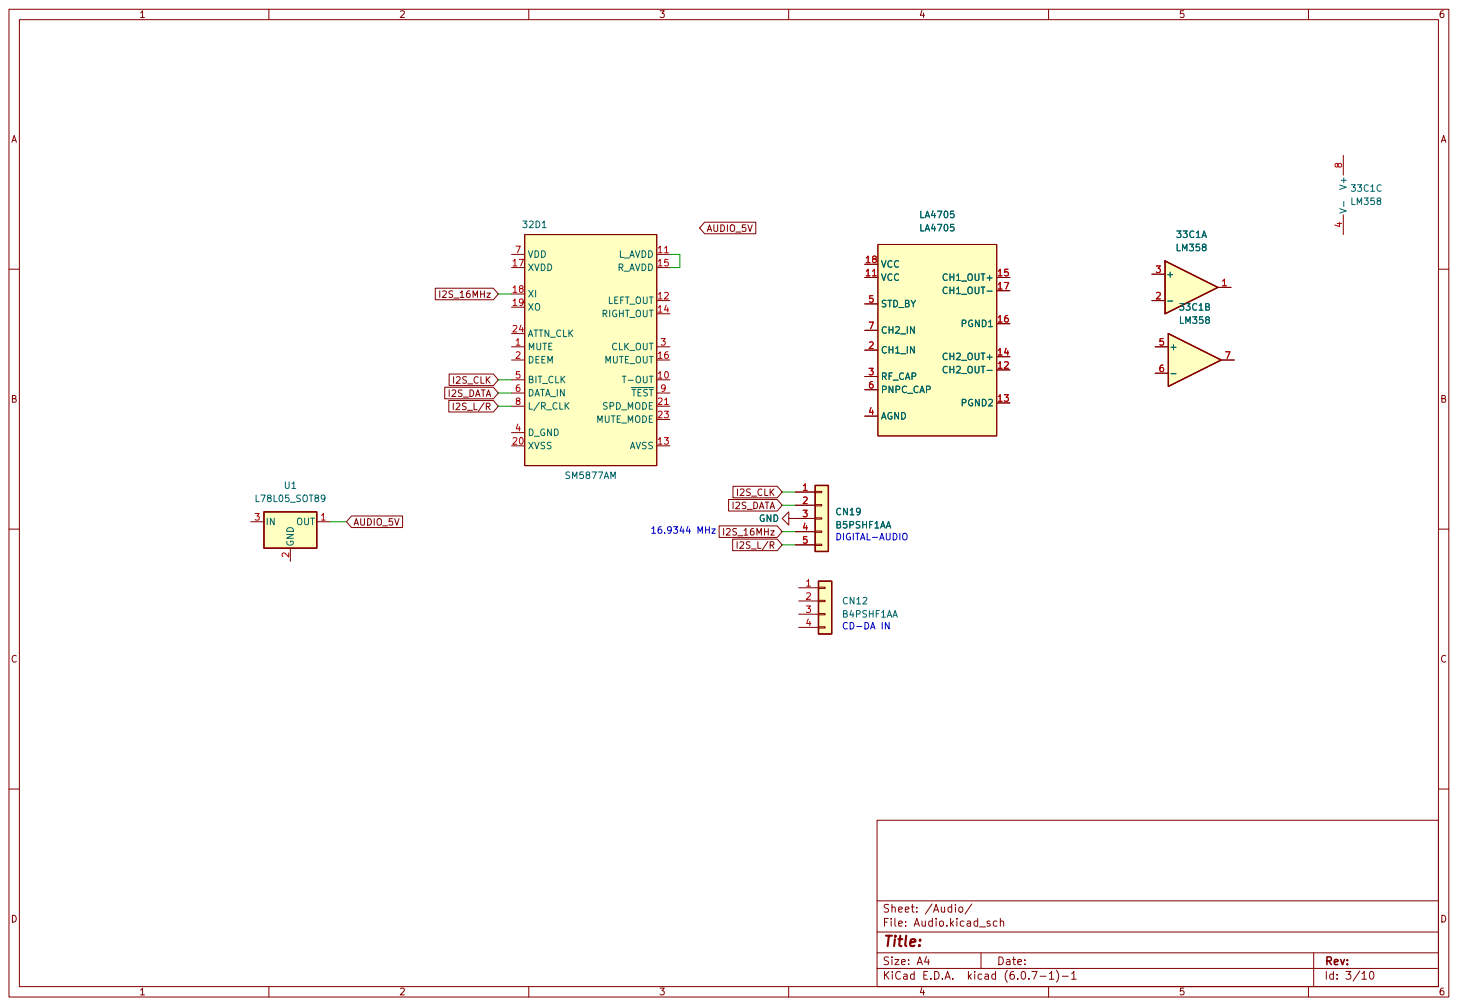
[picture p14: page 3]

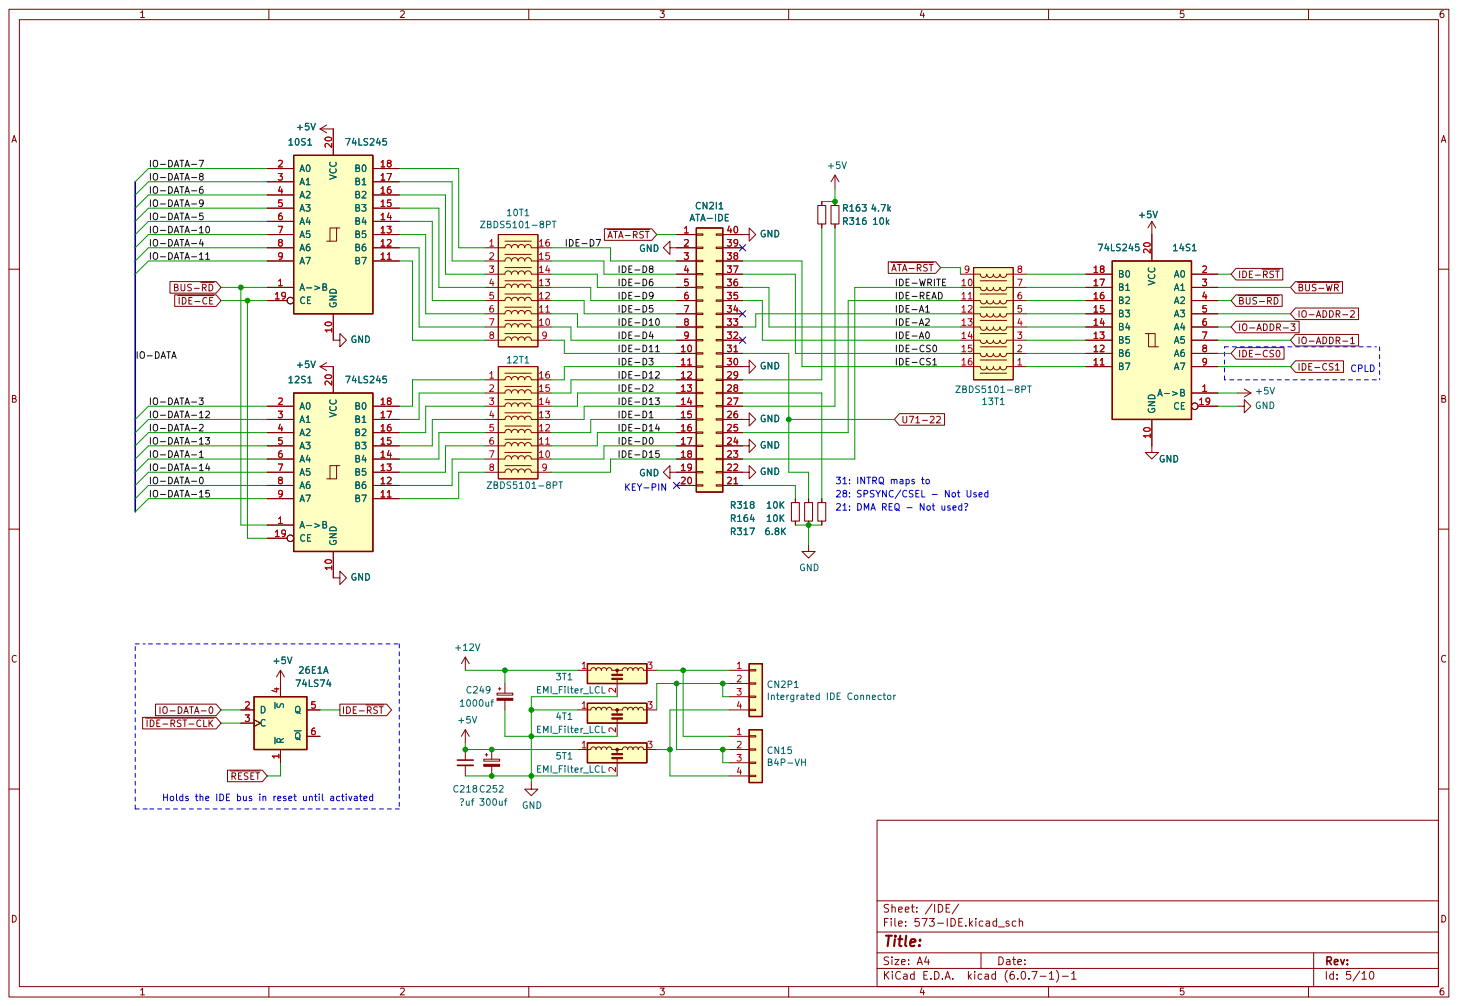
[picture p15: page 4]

IO-ADDR-2 BUS-~{RD}
~{IDE-CE}

2 | 15 | IDE-D2 13 13 | 28 28
3 | 14 | IDE-D13 14 14 | 27 27
4 | 13 | IDE-D1 15 15 | 26 26 25 25
5 | 12 | IDE-D14 16 16
6 | 11 | IDE-D0 17 17 | 24 24 23 23
7 | 10 | IDE-D15 18 18
8 | 9 | 19 19

28: SPSYNC/CSEL - Not Used
21: DMA REQ - Not used?

File: 573-IDE.kicad_sch Sheet: /IDE/
Id: 5/10 Title:

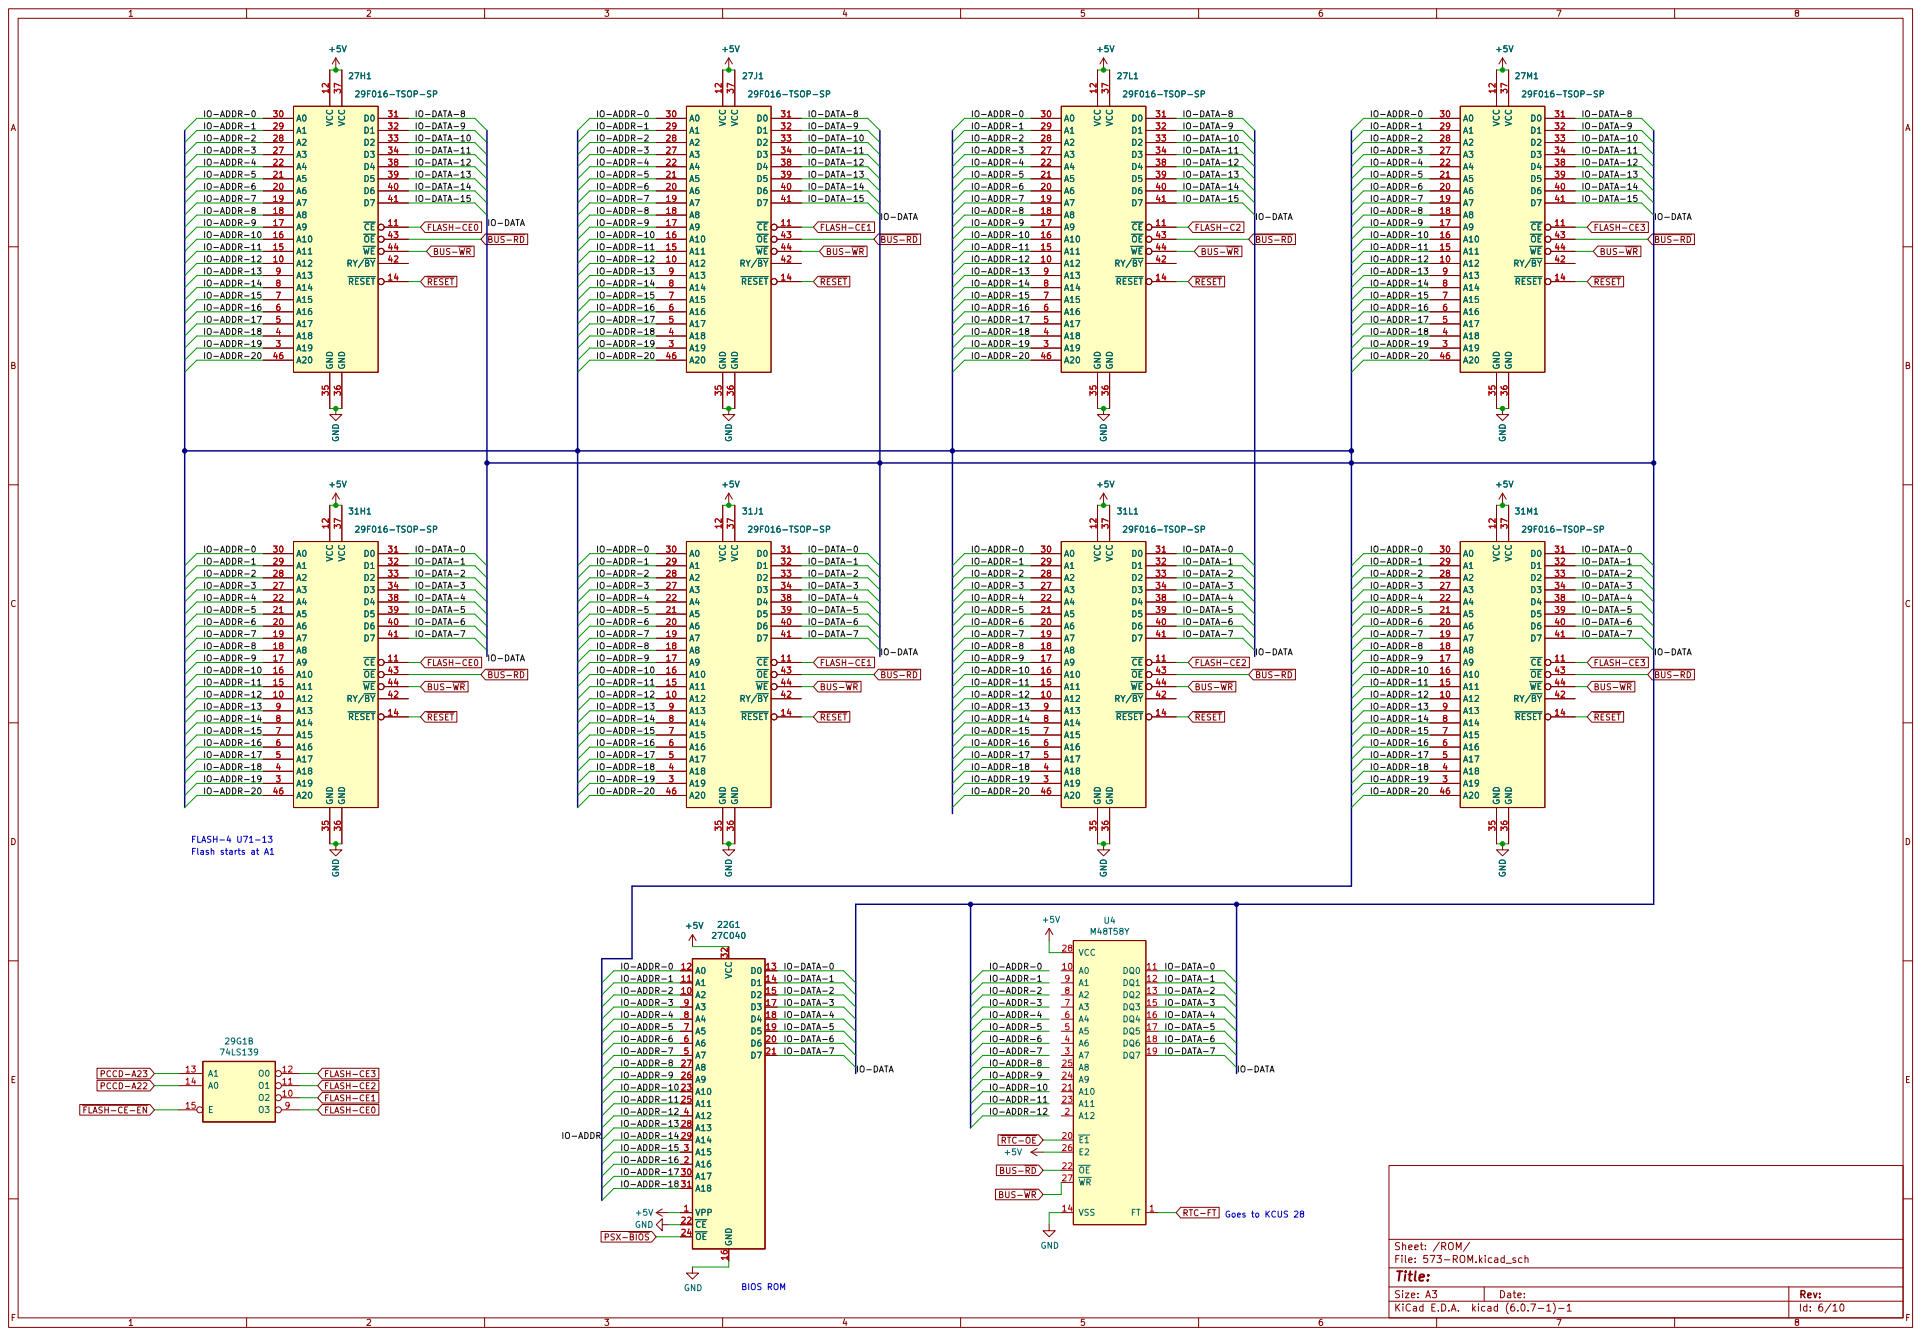
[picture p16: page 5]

FLASH-4 U71-13 Flash starts at A1

Goes to KCUS 28 BIOS ROM

File: 573-ROM.kicad_sch Sheet: /ROM/

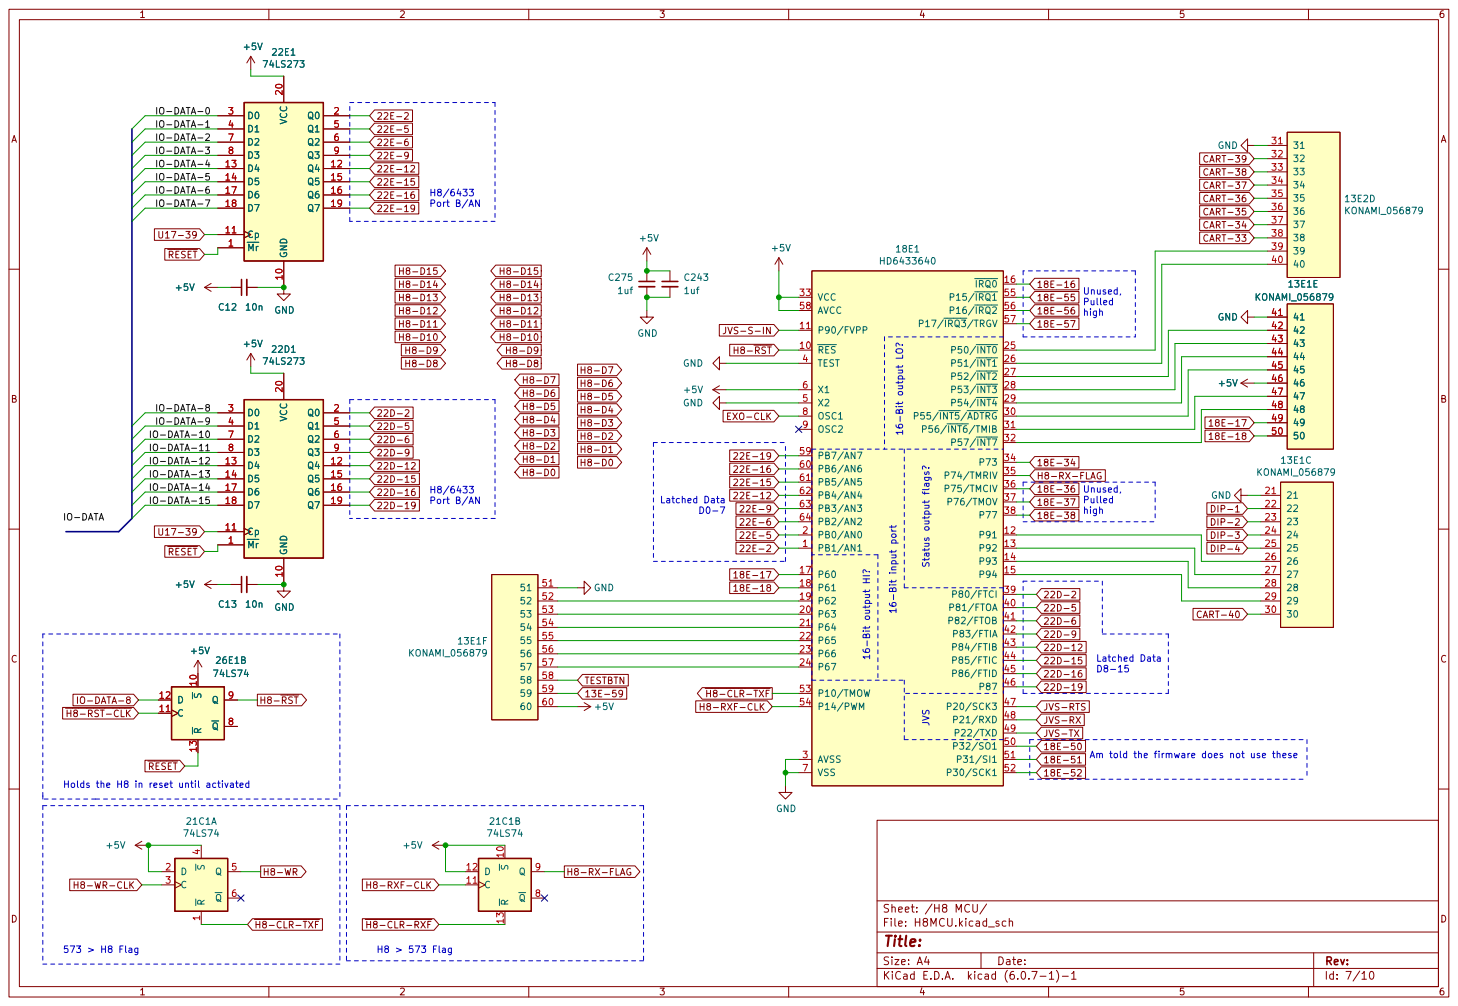
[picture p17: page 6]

Am told the firmware does not use these

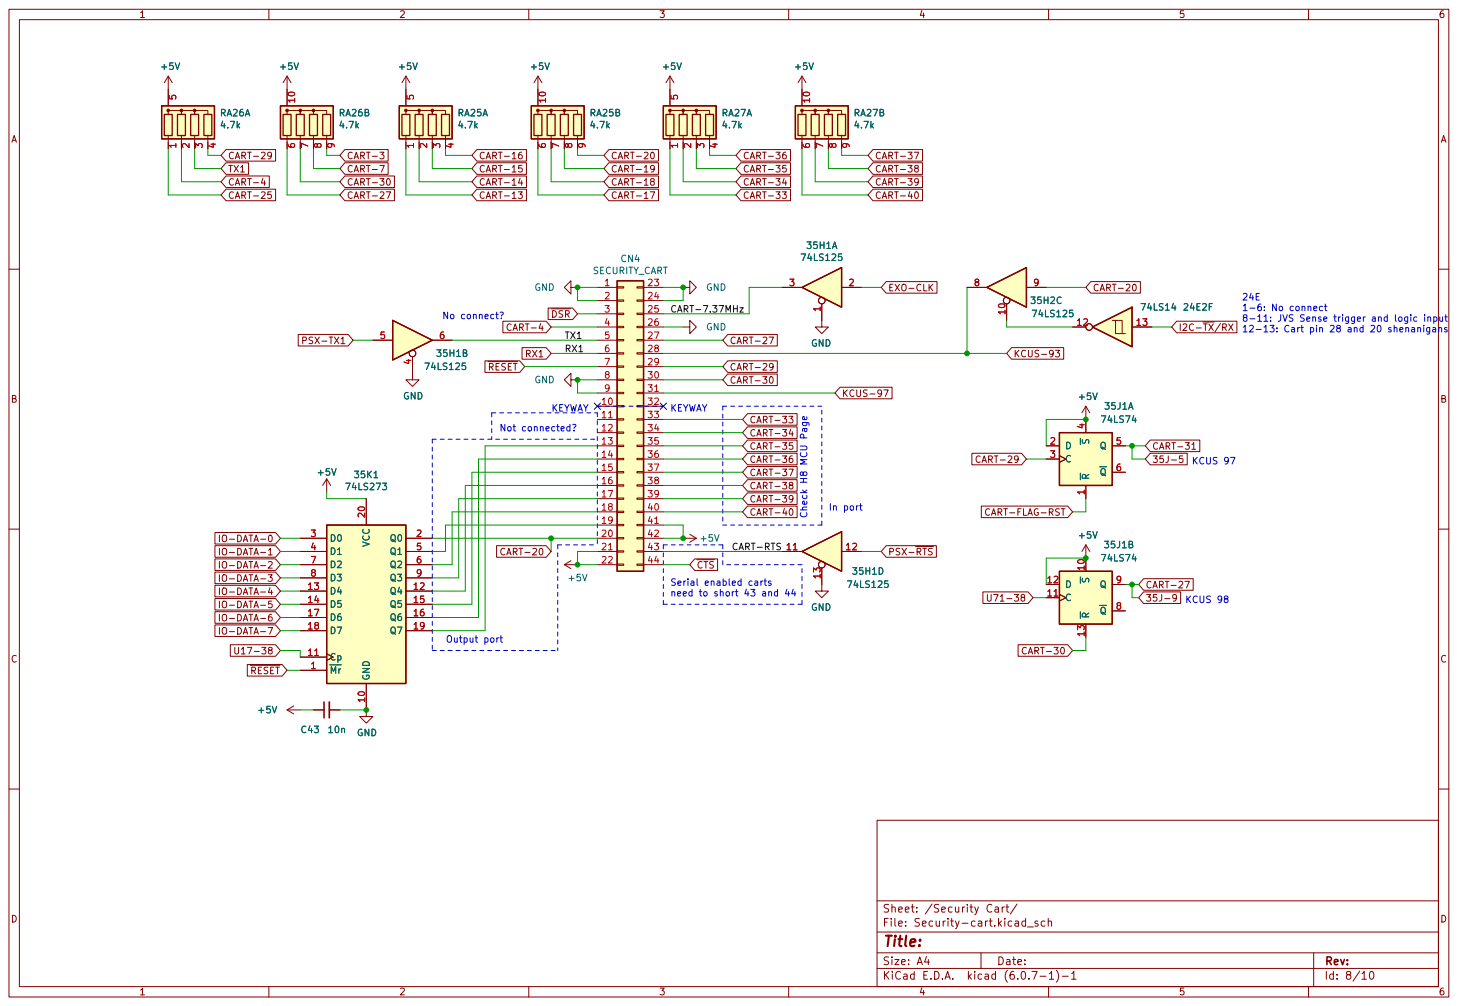
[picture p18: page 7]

1-6: No connect 8-11: JVS Sense trigger and logic input

12-13: Cart pin 28 and 20 shenanigans GND

14
15
16
17
18
19

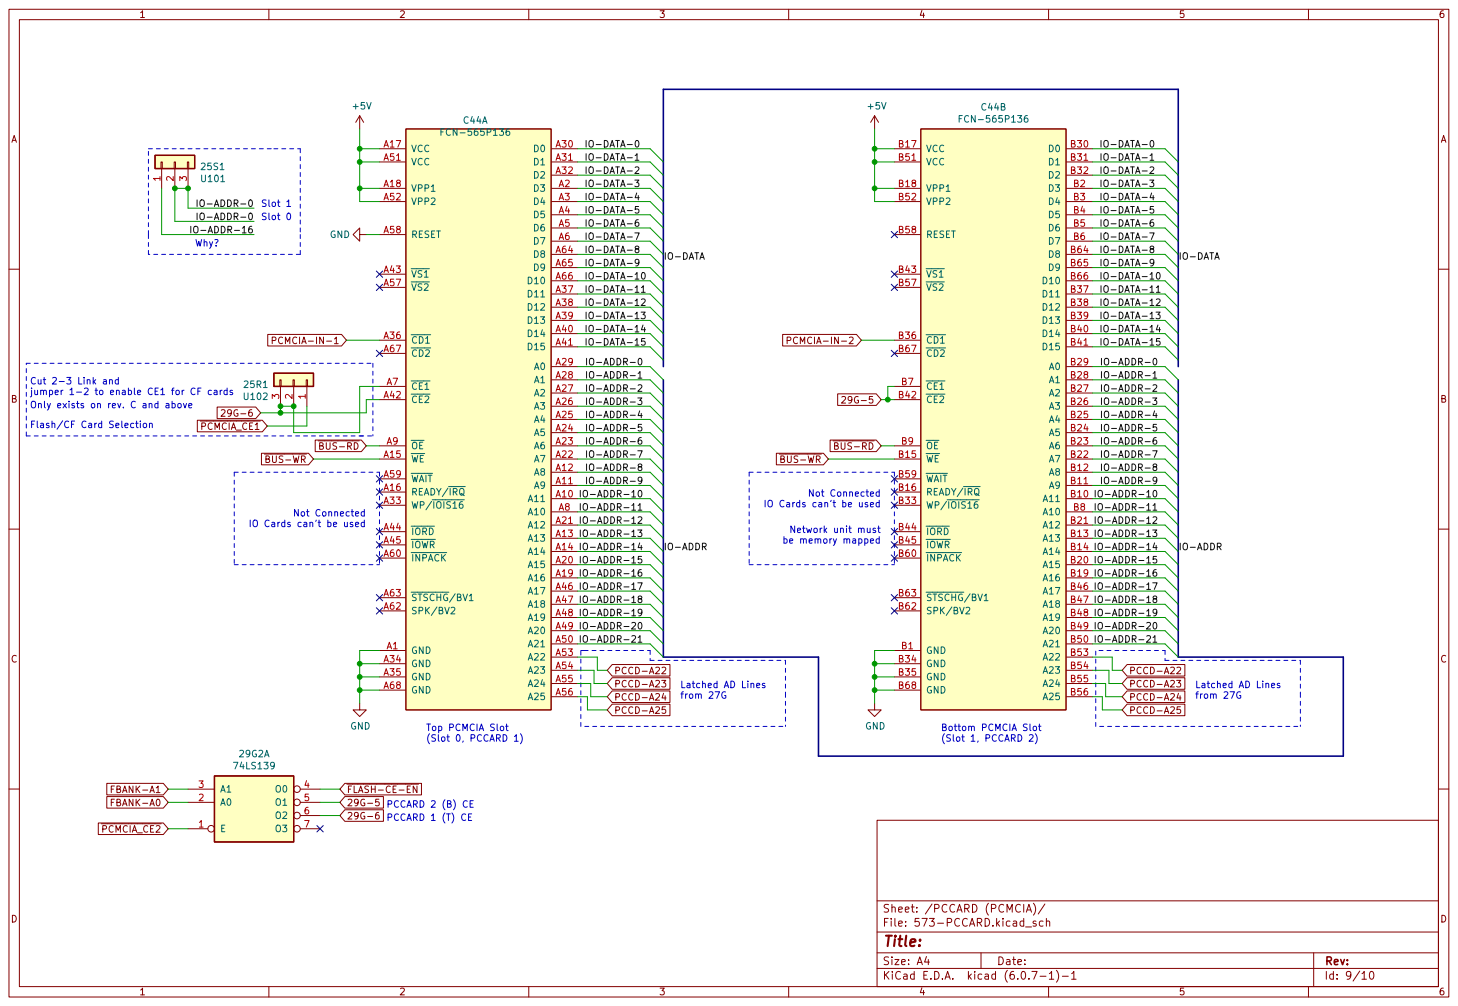
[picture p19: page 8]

IO-DATA-2 Bottom PCMCIA Slot (Slot 1, PCCARD 2) Network unit must be memory mapped

~{BUS-WR} PCMCIA-IN-1

Only exists on rev. C and above Cut 2-3 Link and

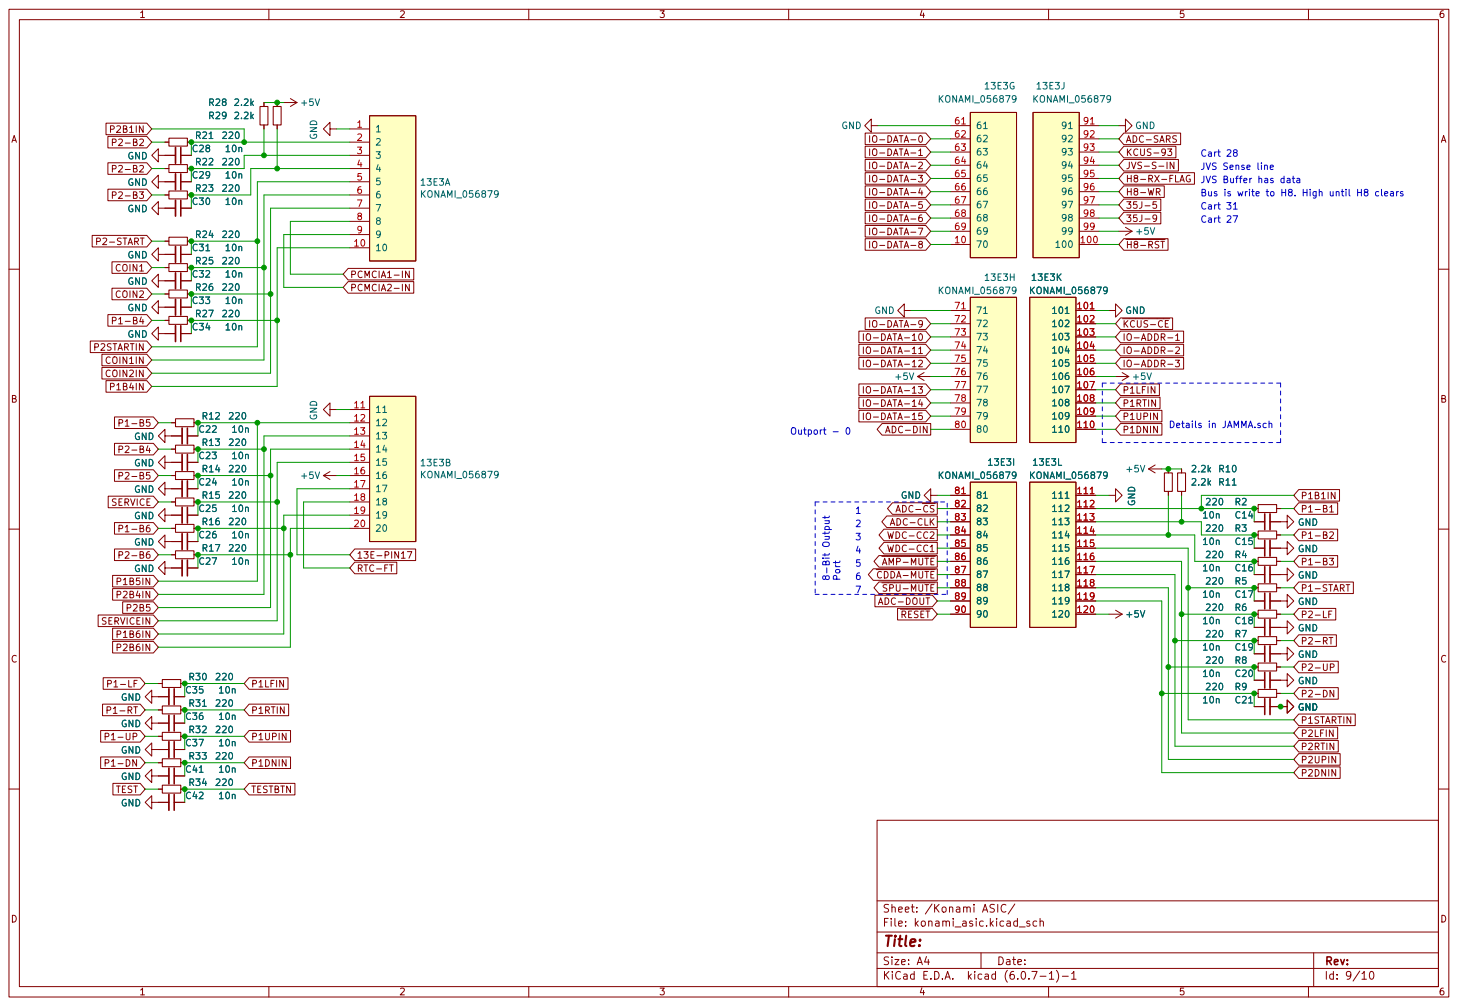
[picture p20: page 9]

JVS Buffer has data Cart 28 Bus is write to H8. High until H8 clears


~{DSYSCLK} 206

VCK-N 192 VCK-P 196

File: PSX-COH.kicad_sch Sheet: /PSX-COH/



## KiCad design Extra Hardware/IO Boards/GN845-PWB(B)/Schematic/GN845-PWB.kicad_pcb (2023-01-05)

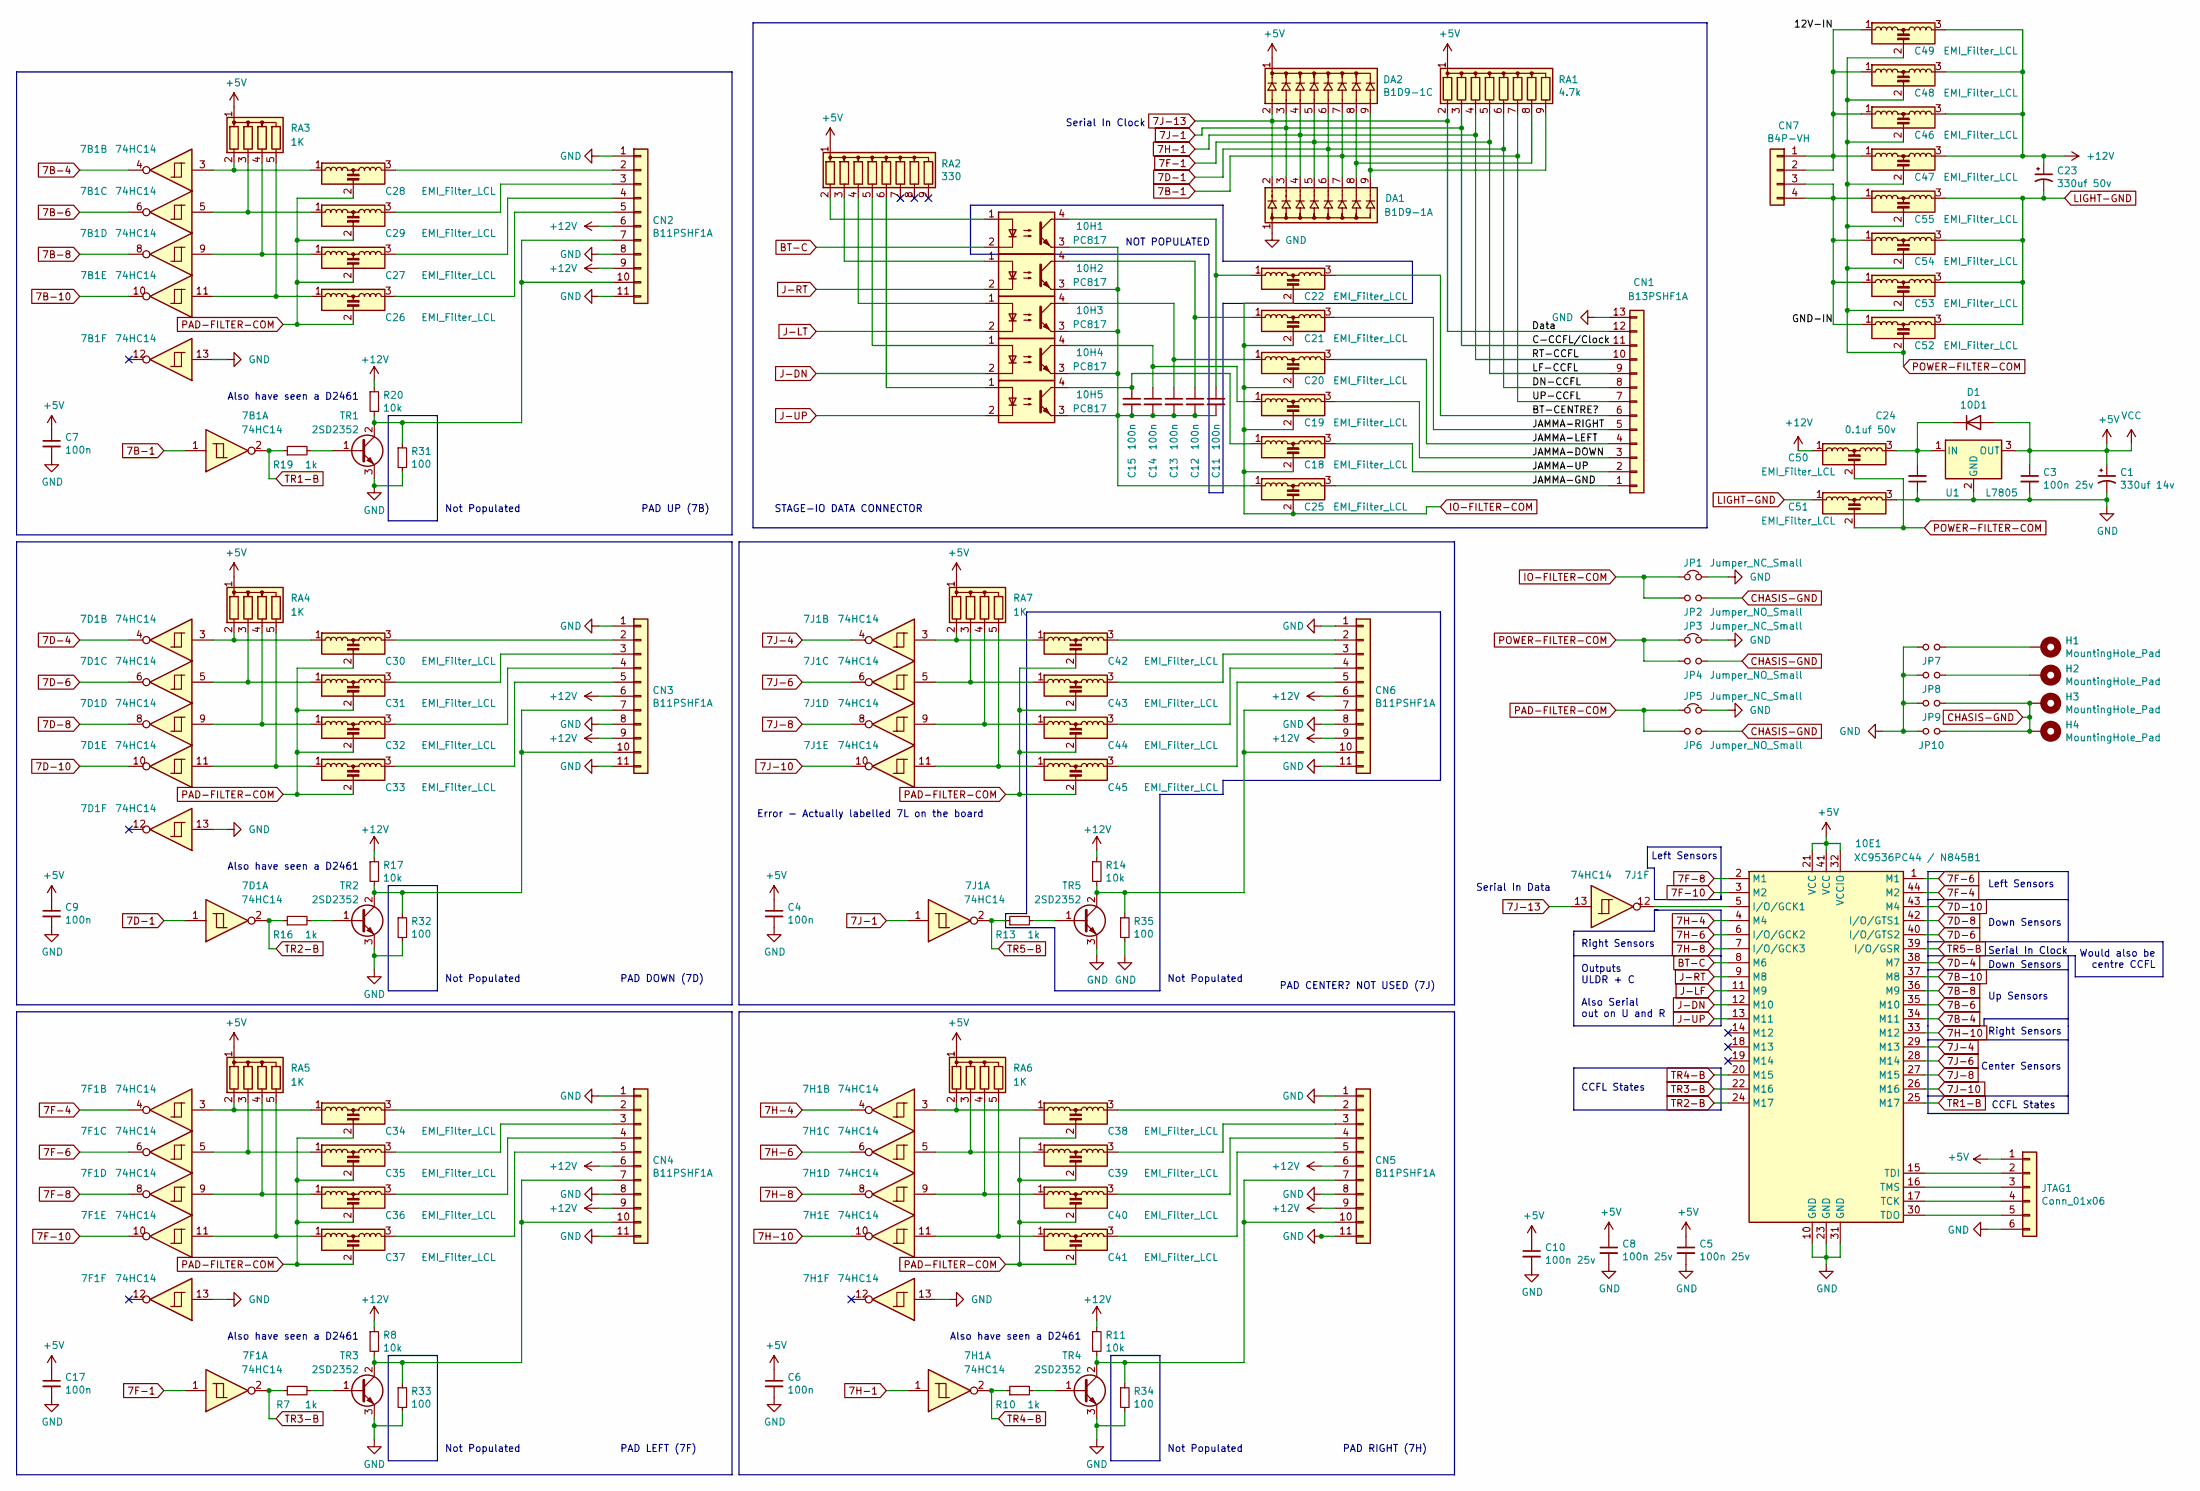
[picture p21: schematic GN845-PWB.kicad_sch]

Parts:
7B1, 7D1, 7F1, 7H1, 7J1: 74HC14; DIP-14_W7.62mm
10E1: XC9536PC44 / N845B1; PLCC-44
10H1, 10H2, 10H3, 10H4, 10H5: PC817; DIP-4_W7.62mm
C1: 330uf 14v; CP_Radial_D8.0mm_P3.50mm
C3, C5, C8, C10: 100n 25v; C_Axial_L3.8mm_D2.6mm_P10.00mm_Horizontal
C4, C6, C7, C9, C11, C12, C13, C14, C15, C17: 100n; C_Axial_L3.8mm_D2.6mm_P10.00mm_Horizontal
C18, C19, C20, C21, C22, C25, C26, C27, C28, C29, C30, C31, C32, C33, C34, C35, C36, C37, C38, C39, C40, C41, C42, C43, C44, C45, C46, C47, C48, C49, C50, C51, C52, C53, C54, C55: EMI_Filter_LCL; PinSocket_1x03_P2.54mm_Vertical
C23: 330uf 50v; CP_Radial_D8.0mm_P3.50mm
C24: 0.1uf 50v; C_Disc_D4.7mm_W2.5mm_P5.00mm
CN1: B13PSHF1A; JST_NH_B13P_SHD
CN2, CN3, CN4, CN5, CN6: B11PSHF1A; JST_NH_B11P_SHD
CN7: B4P-VH; JST_VH_B4P-VH-B_1x04_P3.96mm_Vertical
D1: 10D1; D_DO-41_SOD81_P10.16mm_Horizontal
DA1: B1D9-1A; SIP9_Housing
DA2: B1D9-1C; SIP9_Housing
H1, H2, H3, H4: MountingHole_Pad; MountingHole_3.2mm_M3_DIN965_Pad
JP1, JP3, JP5: Jumper_NC_Small; C_Rect_L7.0mm_W2.0mm_P5.00mm
JP2, JP4, JP6, JP7, JP8, JP9, JP10: Jumper_NO_Small; C_Rect_L7.0mm_W2.0mm_P5.00mm
JTAG1: Conn_01x06
R7, R10, R13, R16, R19: 1k; R_Axial_DIN0204_L3.6mm_D1.6mm_P5.08mm_Vertical
R8, R11, R14, R17, R20: 10k; R_Axial_DIN0204_L3.6mm_D1.6mm_P5.08mm_Vertical
R31, R32, R33, R34, R35: 100; R_Axial_DIN0204_L3.6mm_D1.6mm_P5.08mm_Vertical
RA1: 4.7k; R_Array_SIP9
RA2: 330; R_Array_SIP9
RA3, RA4, RA5, RA6, RA7: 1K; R_Array_SIP5
TR1, TR2, TR3, TR4, TR5: 2SD2352; TO-220-3_Horizontal_TabDown
U1: L7805; TO-220-3_Horizontal_TabDown

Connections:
7B-1: 7B1.1, CN1.7, DA1.7 (R6), DA2.7 (R6), RA1.7 (R6)
7B-4: 7B1.4, 10E1.34 (M11)
7B-6: 7B1.6, 10E1.35 (M10)
7B-8: 7B1.8, 10E1.36 (M9)
7B-10: 7B1.10, 10E1.37 (M8)
7D-1: 7D1.1, CN1.8, DA1.6 (R5), DA2.6 (R5), RA1.6 (R5)
7D-4: 7D1.4, 10E1.38 (M7)
7D-6: 7D1.6, 10E1.40 (I/O/GTS2)
7D-8: 7D1.8, 10E1.42 (I/O/GTS1)
7D-10: 7D1.10, 10E1.43 (M4)
7F-1: 7F1.1, CN1.9, DA1.5 (R4), DA2.5 (R4), RA1.5 (R4)
7F-4: 7F1.4, 10E1.44 (M2)
7F-6: 7F1.6, 10E1.1 (M1)
7F-8: 7F1.8, 10E1.2 (M1)
7F-10: 7F1.10, 10E1.3 (M2)
7H-1: 7H1.1, CN1.10, DA1.4 (R3), DA2.4 (R3), RA1.4 (R3)
7H-4: 7H1.4, 10E1.4 (M4)
7H-6: 7H1.6, 10E1.6 (I/O/GCK2)
7H-8: 7H1.8, 10E1.7 (I/O/GCK3)
7H-10: 7H1.10, 10E1.33 (M12)
7J-1: 7J1.1, CN1.11, DA1.3 (R2), DA2.3 (R2), RA1.3 (R2)
7J-4: 7J1.4, 10E1.29 (M13)
7J-6: 7J1.6, 10E1.28 (M14)
7J-8: 7J1.8, 10E1.27 (M15)
7J-10: 7J1.10, 10E1.26 (M16)
7J-13: 7J1.13, CN1.12, DA1.2 (R1), DA2.2 (R1), RA1.2 (R1)
+5V: 10E1.21 (VCC), 10E1.32 (VCCIO), 10E1.41 (VCC), C1.1, C3.1, C4.1, C5.1, C6.1, C7.1, C8.1, C9.1, C10.1, C17.1, D1.2 (A), DA2.1 (common), JTAG1.1, RA1.1 (common), RA2.1 (common), RA3.1 (common), RA4.1 (common), RA5.1 (common), RA6.1 (common), RA7.1 (common), U1.3 (OUT)
+12V: C23.1, C46.3, C47.3, C48.3, C49.3, C50.1, CN2.6, CN2.9, CN3.6, CN3.9, CN4.6, CN4.9, CN5.6, CN5.9, CN6.6, CN6.9, R8.1, R11.1, R14.1, R17.1, R20.1
/12V-IN: C46.1, C47.1, C48.1, C49.1, CN7.1, CN7.2
/BT-CENTRE?: C22.3, CN1.6
/GND-IN: C52.1, C53.1, C54.1, C55.1, CN7.3, CN7.4
/JAMMA-DOWN: C19.3, CN1.3
/JAMMA-GND: C25.3, CN1.1
/JAMMA-LEFT: C20.3, CN1.4
/JAMMA-RIGHT: C21.3, CN1.5
/JAMMA-UP: C18.3, CN1.2
BT-C: 10E1.8 (M6), 10H1.2
CHASIS-GND: H3.1, H4.1, JP2.2, JP4.2, JP6.2, JP9.2, JP10.2
GND: 7B1.13, 7D1.13, 7F1.13, 7H1.13, 10E1.10 (GND), 10E1.23 (GND), 10E1.31 (GND), C1.2, C3.2, C4.2, C5.2, C6.2, C7.2, C8.2, C9.2, C10.2, C17.2, C24.1, C51.3, CN1.13, CN2.1, CN2.8, CN2.11, CN3.1, CN3.8, CN3.11, CN4.1, CN4.8, CN4.11, CN5.1, CN5.8, CN5.11, CN6.1, CN6.8, CN6.11, DA1.1 (common), JP1.2, JP3.2, JP5.2, JP7.1, JP8.1, JP9.1, JP10.1, JTAG1.6, R31.2, R32.2, R33.2, R34.2, R35.2, TR1.3 (E), TR2.3 (E), TR3.3 (E), TR4.3 (E), TR5.3 (E), U1.2 (GND)
IO-FILTER-COM: C18.2, C19.2, C20.2, C21.2, C22.2, C25.2, JP1.1, JP2.1
J-DN: 10E1.12 (M10), 10H4.2
J-LF: 10E1.11 (M9)
J-LT: 10H3.2
J-RT: 10E1.9 (M8), 10H2.2
J-UP: 10E1.13 (M11), 10H5.2
LIGHT-GND: C23.2, C51.1, C52.3, C53.3, C54.3, C55.3
unnamed: 7B1.3, C28.1, RA3.2 (R1)
unnamed: 7B1.5, C29.1, RA3.3 (R2)
unnamed: 7B1.9, C27.1, RA3.4 (R3)
unnamed: 7B1.11, C26.1, RA3.5 (R4)
unnamed: 7D1.3, C30.1, RA4.2 (R1)
unnamed: 7D1.5, C31.1, RA4.3 (R2)
unnamed: 7D1.9, C32.1, RA4.4 (R3)
unnamed: 7D1.11, C33.1, RA4.5 (R4)
unnamed: 7F1.3, C34.1, RA5.2 (R1)
unnamed: 7F1.5, C35.1, RA5.3 (R2)
unnamed: 7F1.9, C36.1, RA5.4 (R3)
unnamed: 7F1.11, C37.1, RA5.5 (R4)
unnamed: 7H1.3, C38.1, RA6.2 (R1)
unnamed: 7H1.5, C39.1, RA6.3 (R2)
unnamed: 7H1.9, C40.1, RA6.4 (R3)
unnamed: 7H1.11, C41.1, RA6.5 (R4)
unnamed: 7J1.3, C42.1, RA7.2 (R1)
unnamed: 7J1.5, C43.1, RA7.3 (R2)
unnamed: 7J1.9, C44.1, RA7.4 (R3)
unnamed: 7J1.11, C45.1, RA7.5 (R4)
unnamed: 7J1.12, 10E1.5 (I/O/GCK1)
unnamed: 10E1.15 (TDI), JTAG1.2
unnamed: 10E1.16 (TMS), JTAG1.3
unnamed: 10E1.17 (TCK), JTAG1.4
unnamed: 10E1.30 (TDO), JTAG1.5
unnamed: 10H1.1, RA2.2 (R1)
unnamed: 10H1.3, 10H2.3, 10H3.3, 10H4.3, 10H5.3, C11.2, C12.2, C13.2, C14.2, C15.2, C25.1
unnamed: 10H1.4, C11.1, C22.1
unnamed: 10H2.1, RA2.3 (R2)
unnamed: 10H2.4, C12.1, C21.1
unnamed: 10H3.1, RA2.4 (R3)
unnamed: 10H3.4, C13.1, C20.1
unnamed: 10H4.1, RA2.5 (R4)
unnamed: 10H4.4, C14.1, C19.1
unnamed: 10H5.1, RA2.6 (R5)
unnamed: 10H5.4, C15.1, C18.1
unnamed: C24.2, C50.3, D1.1 (K), U1.1 (IN)
unnamed: C26.3, CN2.5
unnamed: C27.3, CN2.4
unnamed: C28.3, CN2.2
unnamed: C29.3, CN2.3
unnamed: C30.3, CN3.2
unnamed: C31.3, CN3.3
unnamed: C32.3, CN3.4
unnamed: C33.3, CN3.5
unnamed: C34.3, CN4.2
unnamed: C35.3, CN4.3
unnamed: C36.3, CN4.4
unnamed: C37.3, CN4.5
unnamed: C38.3, CN5.2
unnamed: C39.3, CN5.3
unnamed: C40.3, CN5.4
unnamed: C41.3, CN5.5
unnamed: C42.3, CN6.2
unnamed: C43.3, CN6.3
unnamed: C44.3, CN6.4
unnamed: C45.3, CN6.5
unnamed: CN2.7, CN2.10, R20.2, R31.1, TR1.2 (C)
unnamed: CN3.7, CN3.10, R17.2, R32.1, TR2.2 (C)
unnamed: CN4.7, CN4.10, R8.2, R33.1, TR3.2 (C)
unnamed: CN5.7, CN5.10, R11.2, R34.1, TR4.2 (C)
unnamed: CN6.7, CN6.10, R14.2, R35.1, TR5.2 (C)
unnamed: DA1.8 (R7), DA2.8 (R7), RA1.8 (R7)
unnamed: DA1.9 (R8), DA2.9 (R8), RA1.9 (R8)
unnamed: H1.1, JP7.2
unnamed: H2.1, JP8.2
unnamed: R7.2, TR3.1 (B)
unnamed: R10.2, TR4.1 (B)
unnamed: R13.2, TR5.1 (B)
unnamed: R16.2, TR2.1 (B)
unnamed: R19.2, TR1.1 (B)
PAD-FILTER-COM: C26.2, C27.2, C28.2, C29.2, C30.2, C31.2, C32.2, C33.2, C34.2, C35.2, C36.2, C37.2, C38.2, C39.2, C40.2, C41.2, C42.2, C43.2, C44.2, C45.2, JP5.1, JP6.1
POWER-FILTER-COM: C46.2, C47.2, C48.2, C49.2, C50.2, C51.2, C52.2, C53.2, C54.2, C55.2, JP3.1, JP4.1
TR1-B: 7B1.2, 10E1.25 (M17), R19.1
TR2-B: 7D1.2, 10E1.24 (M17), R16.1
TR3-B: 7F1.2, 10E1.22 (M16), R7.1
TR4-B: 7H1.2, 10E1.20 (M15), R10.1
TR5-B: 7J1.2, 10E1.39 (I/O/GSR), R13.1

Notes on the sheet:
Up Sensors
Right Sensors
Center Sensors
STAGE-IO DATA CONNECTOR
Not Populated
Error - Actually labelled 7L on the board
Serial In Clock
Down Sensors
CCFL States
PAD DOWN (7D)
Also have seen a D2461
Left Sensors
PAD CENTER? NOT USED (7J)
NOT POPULATED
PAD LEFT (7F)
Outputs ULDR + C Also Serial out on U and R
PAD UP (7B)
Would also be centre CCFL
PAD RIGHT (7H)
Serial In Data

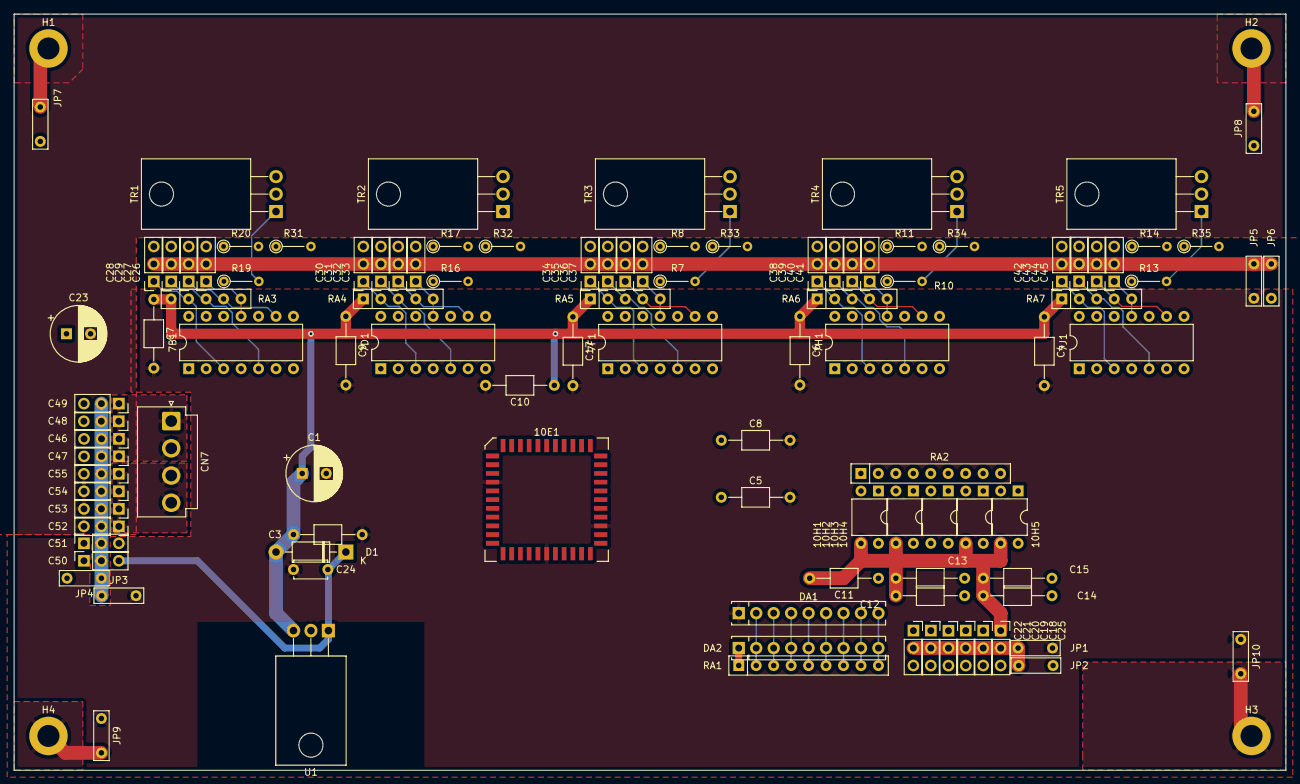
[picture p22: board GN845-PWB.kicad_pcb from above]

Board: 2 copper layers, 185.0 x 110.0 mm, 110 parts (0 on the bottom side), 92 nets.

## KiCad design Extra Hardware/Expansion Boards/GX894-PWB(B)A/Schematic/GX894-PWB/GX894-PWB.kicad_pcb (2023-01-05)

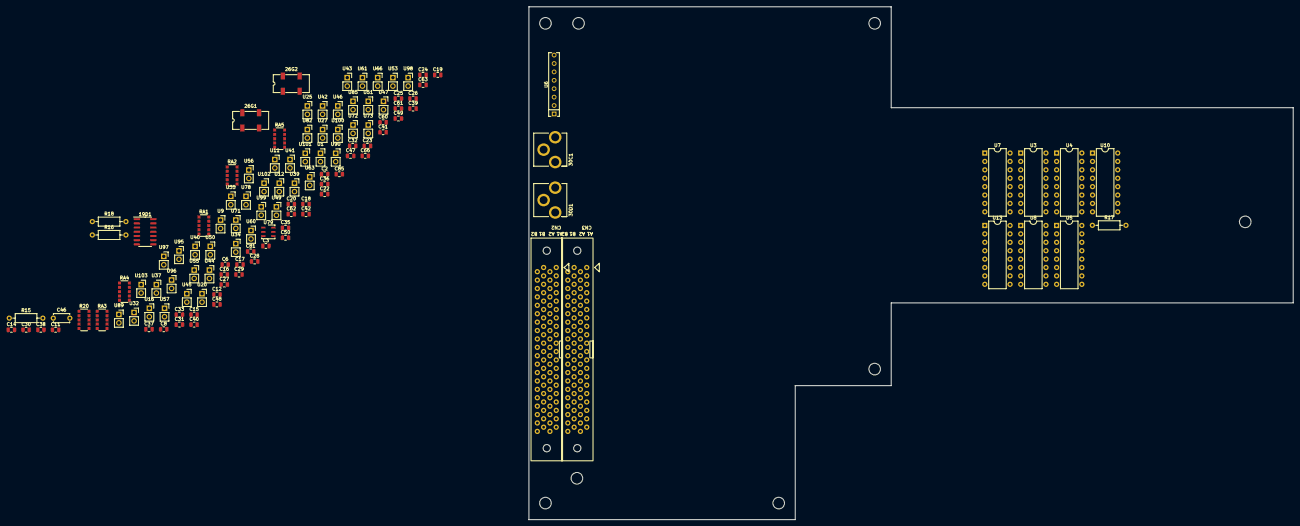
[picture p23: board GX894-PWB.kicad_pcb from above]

Board: 2 copper layers, 231.0 x 155.0 mm, 128 parts (0 on the bottom side), 124 nets, no tracks yet.

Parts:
19D1: 74HC14; SOIC-14_3.9x8.7mm_P1.27mm
26G1: 29.45MHz; Oscillator_SMD_SeikoEpson_SG8002JC-4Pin_10.5x5.0mm
26G2: 19.6608 MHz; Oscillator_SMD_SeikoEpson_SG8002JC-4Pin_10.5x5.0mm
30C1, 30D1: JPJ1018; RCA_Mounting
C2, C3, C6, C8, C11, C12, C28, C29: 0.1µf; C_0805_2012Metric
C14, C15, C16, C17, C18, C19, C22, C23, C24, C25, C26, C27, C30, C31, C32, C33, C35, C36, C37, C38, C39, C40, C41, C42, C47, C48, C49, C50, C60, C61, C62, C63: 10nf; C_0805_2012Metric
C20, C66, C81, C85: 1uf; C_0805_2012Metric
C46: 0.01MC1K; C_Disc_D4.7mm_W2.5mm_P5.00mm
CN2, CN3: 573_EXP; JAE-TX15-80P
H1, H2, H3, H4, H5, H6, H7, H8: MountingHole; MountingHole_3.5mm
R15, R18: 100; R_Axial_DIN0207_L6.3mm_D2.5mm_P10.16mm_Horizontal
R16, R17: 5.6k; R_Axial_DIN0207_L6.3mm_D2.5mm_P10.16mm_Horizontal
R20: 470Ω; R_Array_Convex_5x1206
RA1: 4.7Ω; R_Array_Convex_5x1206
RA2, RA3, RA4: 470Ω; R_Array_Convex_5x1206
RA5: 2.2k; R_Array_Convex_5x1206
U1, U9, U11, U12, U16, U20, U25, U27, U32, U34, U35, U37, U39, U40, U41, U42, U43, U44, U45, U46, U47, U49, U50, U51, U53, U55, U56, U57, U60, U61, U63, U66, U71, U72, U73, U78, U82, U85, U89, U90, U95, U96, U97, U98, U99, U100, U101, U102, U103: ZBF253D; PinSocket_1x02_P2.54mm_Vertical
U3, U4, U5, U7, U8, U10, U13: PC847; DIP-16_W7.62mm
U6: HYC2485S; SIP-8_19x3mm_P2.54mm
U79: DS2401P; TSOC-6_3.76x3.94mm_P1.27mm

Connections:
573-A0: CN2.a24 (A0), CN3.a24 (A0)
573-A1: CN2.b24 (A1), CN3.b24 (A1)
573-A2: CN2.a23 (A2), CN3.a23 (A2)
573-A3: CN2.b23 (A3), CN3.b23 (A3)
573-A4: CN2.a22 (A4), CN3.a22 (A4)
573-A5: CN2.b22 (A5), CN3.b22 (A5)
573-A6: CN2.a21 (A6), CN3.a21 (A6)
573-A7: CN2.b21 (A7), CN3.b21 (A7)
573-A12: CN2.a20 (A12), CN3.a20 (A12)
573-A13: CN2.b20 (A13), CN3.b20 (A13)
573-A14: CN2.a19 (A14), CN3.a19 (A14)
573-A15: CN2.b19 (A15), CN3.b19 (A15)
573-A20: CN2.a18 (A20), CN3.a18 (A20)
573-A21: CN2.b18 (A21), CN3.b18 (A21)
573-A22: CN2.a17 (A22), CN3.a17 (A22)
573-A23: CN2.b17 (A23), CN3.b17 (A23)
573-D0: CN2.a32 (D0), CN3.a32 (D0)
573-D1: CN2.b32 (D1), CN3.b32 (D1)
573-D2: CN2.a31 (D2), CN3.a31 (D2)
573-D3: CN2.b31 (D3), CN3.b31 (D3)
573-D4: CN2.a30 (D4), CN3.a30 (D4)
573-D5: CN2.b30 (D5), CN3.b30 (D5)
573-D6: CN2.a29 (D6), CN3.a29 (D6)
573-D7: CN2.b29 (D7), CN3.b29 (D7)
573-D8: CN2.a28 (D8), CN3.a28 (D8)
573-D9: CN2.b28 (D9), CN3.b28 (D9)
573-D10: CN2.a27 (D10), CN3.a27 (D10)
573-D11: CN2.b27 (D11), CN3.b27 (D11)
573-D12: CN2.a26 (D12), CN3.a26 (D12)
573-D13: CN2.b26 (D13), CN3.b26 (D13)
573-D14: CN2.a25 (D14), CN3.a25 (D14)
573-D15: CN2.b25 (D15), CN3.b25 (D15)
+3V3: 26G1.1 (OE), 26G1.4 (Vcc), 26G2.1 (OE), 26G2.4 (Vcc), CN2.a36 (+3V3), CN2.a37 (+3V3), CN2.a38 (+3V3), CN2.a39 (+3V3), CN2.a40 (+3V3), CN2.b36 (+3V3), CN2.b37 (+3V3), CN2.b38 (+3V3), CN2.b39 (+3V3), CN2.b40 (+3V3), CN3.a36 (+3V3), CN3.a37 (+3V3), CN3.a38 (+3V3), CN3.a39 (+3V3), CN3.a40 (+3V3), CN3.b36 (+3V3), CN3.b37 (+3V3), CN3.b38 (+3V3), CN3.b39 (+3V3), CN3.b40 (+3V3)
+5V: 19D1.14 (VCC), C3.1, C20.1, C28.1, C66.1, C81.1, C85.1, CN2.a1 (+5V), CN2.a2 (+5V), CN2.a3 (+5V), CN2.a4 (+5V), CN2.a5 (+5V), CN2.b1 (+5V), CN2.b2 (+5V), CN2.b3 (+5V), CN2.b4 (+5V), CN2.b5 (+5V), CN3.a1 (+5V), CN3.a2 (+5V), CN3.a3 (+5V), CN3.a4 (+5V), CN3.a5 (+5V), CN3.b1 (+5V), CN3.b2 (+5V), CN3.b3 (+5V), CN3.b4 (+5V), CN3.b5 (+5V), R20.5 (common), R20.10 (common), RA1.5 (common), RA1.10 (common), RA2.5 (common), RA2.10 (common), RA3.5 (common), RA3.10 (common), RA4.5 (common), RA4.10 (common), U6.2 (VCC), U46.1
DREQ5: CN2.a14 (DREQ5), CN3.a14 (DREQ5)
DREQ5-2: CN2.b12 (DREQ5), CN3.b12 (DREQ5)
EXP-15: CN2.b15 (N/C), CN3.b15 (N/C)
GND: 19D1.1, 19D1.3, 19D1.7 (GND), 26G1.2 (GND), 26G2.2 (GND), C6.1, C11.1, C20.2, C30.2, C31.2, C32.2, C33.2, C46.2, C66.2, C81.2, C85.2, CN2.a8 (GND), CN2.a9 (GND), CN2.a11 (GND), CN2.a13 (GND), CN2.a33 (GND), CN2.a34 (GND), CN2.a35 (GND), CN2.b7 (GND), CN2.b9 (GND), CN2.b11 (GND), CN2.b13 (GND), CN2.b33 (GND), CN2.b34 (GND), CN2.b35 (GND), CN3.a8 (GND), CN3.a9 (GND), CN3.a11 (GND), CN3.a13 (GND), CN3.a33 (GND), CN3.a34 (GND), CN3.a35 (GND), CN3.b7 (GND), CN3.b9 (GND), CN3.b11 (GND), CN3.b13 (GND), CN3.b33 (GND), CN3.b34 (GND), CN3.b35 (GND), R16.1, RA5.5 (common), RA5.10 (common), U6.6 (GND), U12.1, U41.1, U47.1
IRQ10: CN2.a16 (IRQ10), CN3.a16 (IRQ10)
IRQ10-2: CN2.b16 (IRQ10), CN3.b16 (IRQ10)
unnamed: 19D1.5, C31.1
unnamed: 19D1.9, C33.1
unnamed: 19D1.11, C32.1
unnamed: 19D1.13, C30.1
unnamed: 30C1.1, 30D1.1, U6.5 (PH-A)
unnamed: 30C1.2 (Switch), R15.2
unnamed: 30C1.3 (Sheild), 30D1.3 (Sheild), C46.1, R15.1, R17.2, R18.2, U6.4 (PH-B)
unnamed: 30D1.2 (Switch), R18.1
unnamed: C14.1, U13.16, U25.1
unnamed: C14.2, C15.2, C16.2, C17.2, U13.9, U13.11, U13.13, U13.15, U60.1
unnamed: C15.1, U13.14, U102.1
unnamed: C16.1, U13.12, U101.1
unnamed: C17.1, U13.10, U100.1
unnamed: C18.1, U3.16, U99.1
unnamed: C18.2, C19.2, C38.2, C40.2, U3.9, U3.11, U3.13, U3.15, U50.1
unnamed: C19.1, U3.14, U98.1
unnamed: C22.1, U4.16, U95.1
unnamed: C22.2, C23.2, C24.2, C25.2, U4.9, U4.11, U4.13, U4.15, U35.1
unnamed: C23.1, U4.14, U44.1
unnamed: C24.1, U4.12, U90.1
unnamed: C25.1, U4.10, U82.1
unnamed: C26.1, U5.16, U89.1
unnamed: C26.2, C27.2, C35.2, C36.2, U5.9, U5.11, U5.13, U5.15, U45.1
unnamed: C27.1, U5.14, U71.1
unnamed: C35.1, U5.12, U34.1
unnamed: C36.1, U5.10, U40.1
unnamed: C37.1, U10.16, U73.1
unnamed: C37.2, C61.2, C62.2, C63.2, U10.9, U10.11, U10.13, U10.15, U72.1
unnamed: C38.1, U3.10, U96.1
unnamed: C39.1, U1.1, U8.10
unnamed: C39.2, C41.2, C42.2, C47.2, U8.9, U8.11, U8.13, U8.15, U63.1
unnamed: C40.1, U3.12, U97.1
unnamed: C41.1, U8.12, U9.1
unnamed: C42.1, U8.14, U16.1
unnamed: C47.1, U8.16, U27.1
unnamed: C48.1, U7.10, U39.1
unnamed: C48.2, C49.2, C50.2, C60.2, U7.9, U7.11, U7.13, U7.15, U37.1
unnamed: C49.1, U7.14, U53.1
unnamed: C50.1, U7.12, U43.1
unnamed: C60.1, U7.16, U56.1
unnamed: C61.1, U10.10, U103.1
unnamed: C62.1, U10.12, U51.1
unnamed: C63.1, U10.14, U61.1
unnamed: R16.2, R17.1
unnamed: R20.1 (R1), U7.1
unnamed: R20.2 (R2), U7.3
unnamed: R20.3 (R3), U7.5
unnamed: R20.4 (R4), U7.7
unnamed: R20.6 (R5), U8.7
unnamed: R20.7 (R6), U8.5
unnamed: R20.8 (R7), U8.3
unnamed: R20.9 (R8), U8.1
unnamed: RA1.1 (R1), RA5.1 (R1), U20.1
unnamed: RA1.4 (R4), RA5.4 (R4), U57.1
unnamed: RA1.3 (R3), RA5.3 (R3), U49.1
unnamed: RA1.2 (R2), RA5.2 (R2), U32.1
unnamed: RA2.1 (R1), U10.1
unnamed: RA2.2 (R2), U10.3
unnamed: RA2.3 (R3), U10.5
unnamed: RA2.4 (R4), U10.7
unnamed: RA2.6 (R5), U13.7
unnamed: RA2.7 (R6), U13.5
unnamed: RA2.8 (R7), U13.3
unnamed: RA2.9 (R8), U13.1
unnamed: RA3.1 (R1), U3.1
unnamed: RA3.2 (R2), U3.3
unnamed: RA3.3 (R3), U3.5
unnamed: RA3.4 (R4), U3.7
unnamed: RA3.6 (R5), U4.7
unnamed: RA3.7 (R6), U4.5
unnamed: RA3.8 (R7), U4.3
unnamed: RA3.9 (R8), U4.1
unnamed: RA4.1 (R1), U5.1
unnamed: RA4.2 (R2), U5.3
unnamed: RA4.3 (R3), U5.5
unnamed: RA4.4 (R4), U5.7
~EXP1-2: CN2.b14 (~EXP1), CN3.b14 (~EXP1)
~EXP1: CN2.a12 (~EXP1), CN3.a12 (~EXP1)
~EXP2: CN2.a15 (~EXP2), CN3.a15 (~EXP2)
~READ: CN2.a6 (~READ), CN3.a6 (~READ)
~RESET2: CN2.b10 (~RESET), CN3.b10 (~RESET)
~RESET: CN2.a10 (~RESET), CN3.a10 (~RESET)
~WR1: CN2.b6 (~WR1), CN3.b6 (~WR1)
~WR2: CN2.a7 (~WR2), CN3.a7 (~WR2)

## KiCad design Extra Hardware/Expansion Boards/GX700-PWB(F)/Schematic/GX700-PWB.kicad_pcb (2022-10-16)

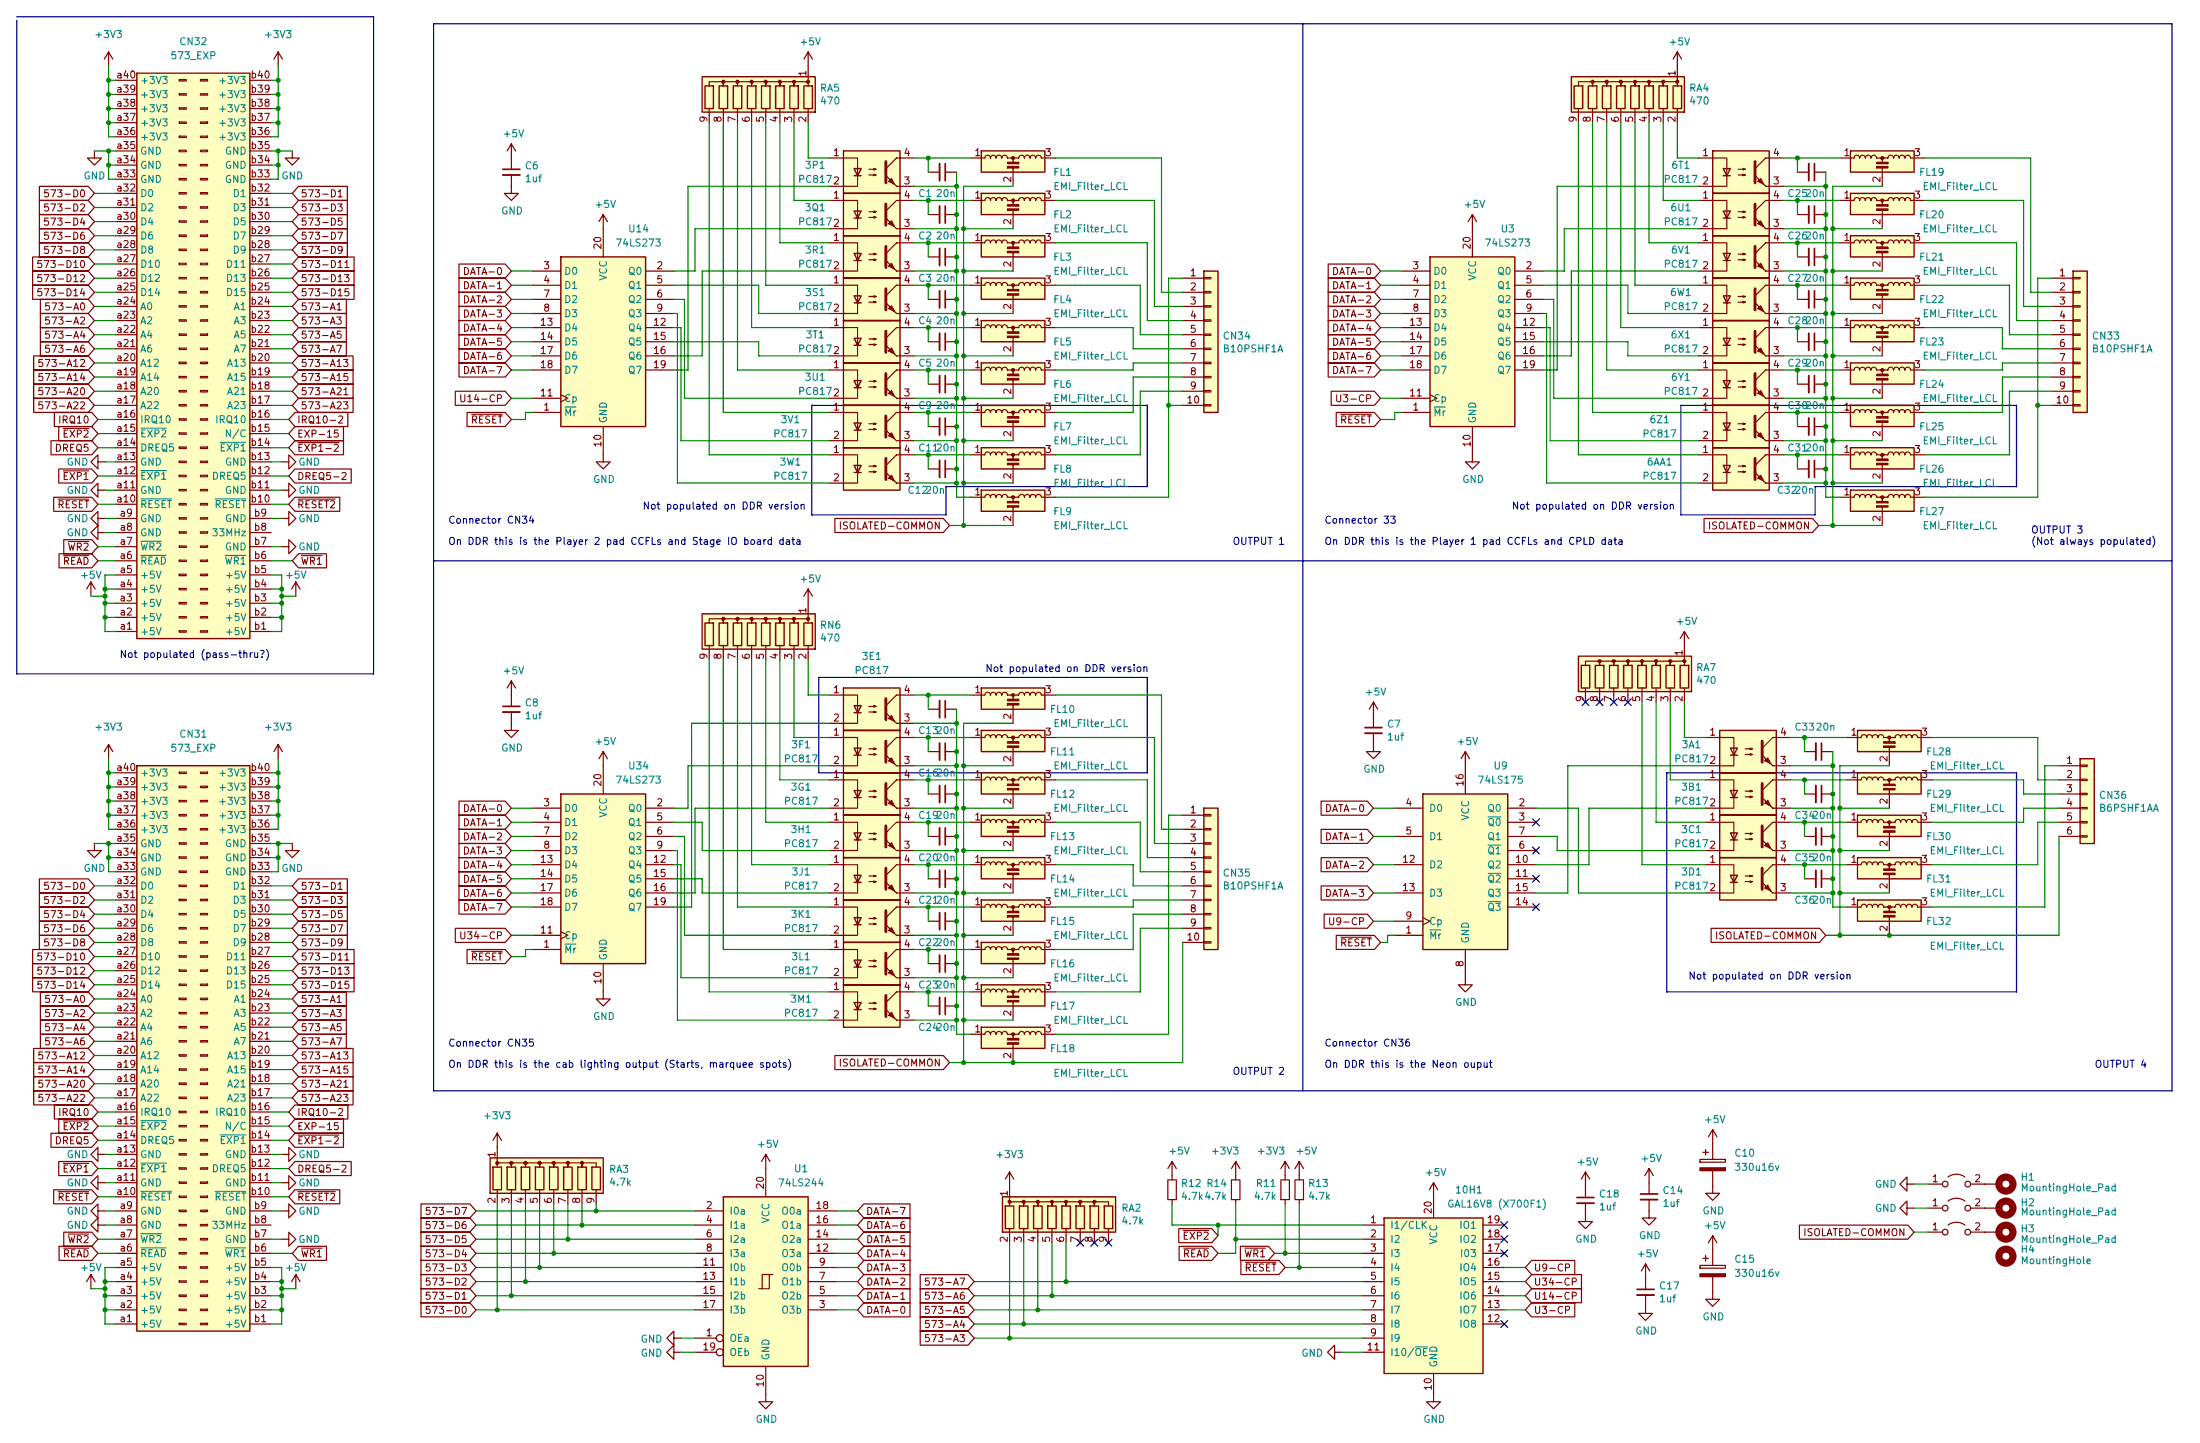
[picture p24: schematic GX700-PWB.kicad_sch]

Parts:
3A1, 3B1, 3C1, 3D1, 3E1, 3F1, 3G1, 3H1, 3J1, 3K1, 3L1, 3M1, 3P1, 3Q1, 3R1, 3S1, 3T1, 3U1, 3V1, 3W1, 6AA1, 6T1, 6U1, 6V1, 6W1, 6X1, 6Y1, 6Z1: PC817; DIP-4_W7.62mm
10H1: GAL16V8 (X700F1); DIP-20_W7.62mm
C1, C2, C3, C4, C5, C9, C11, C12, C13, C16, C19, C20, C21, C22, C23, C24, C25, C26, C27, C28, C29, C30, C31, C32, C33, C34, C35, C36: 20n; C_Axial_L3.8mm_D2.6mm_P7.50mm_Horizontal
C6, C7, C8, C14, C17, C18: 1uf; C_Axial_L3.8mm_D2.6mm_P10.00mm_Horizontal
C10: 330u16v; CP_Radial_D8.0mm_P3.50mm
C15: 330u16v; CP_Radial_D8.0mm_P2.50mm
CN31, CN32: 573_EXP; JAE-TX15-80P
CN33, CN34, CN35: B10PSHF1A; PinSocket_1x10_P2.54mm_Vertical
CN36: B6PSHF1AA; PinSocket_1x06_P2.54mm_Vertical
FL1, FL2, FL3, FL4, FL5, FL6, FL7, FL8, FL9, FL10, FL11, FL12, FL13, FL14, FL15, FL16, FL17, FL18, FL19, FL20, FL21, FL22, FL23, FL24, FL25, FL26, FL27, FL28, FL29, FL30, FL31, FL32: EMI_Filter_LCL; PinSocket_1x03_P2.54mm_Vertical
H1, H2, H3: MountingHole_Pad; MountingHole_3.5mm_Pad
H4: MountingHole; MountingHole_3.5mm
JP1, JP2, JP3: Jumper_2_Open; PinSocket_1x02_P2.54mm_Vertical
R11, R12, R13, R14: 4.7k; R_Axial_DIN0204_L3.6mm_D1.6mm_P5.08mm_Horizontal
RA2, RA3: 4.7k; R_Array_SIP9
RA4, RA5, RA7: 470; R_Array_SIP9
RN6: 470; R_Array_SIP9
U1: 74LS244; DIP-20_W7.62mm
U3, U14, U34: 74LS273; DIP-20_W7.62mm
U9: 74LS175; DIP-16_W7.62mm

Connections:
573-A0: CN31.a24 (A0), CN32.a24 (A0)
573-A1: CN31.b24 (A1), CN32.b24 (A1)
573-A2: CN31.a23 (A2), CN32.a23 (A2)
573-A3: 10H1.9 (I9), CN31.b23 (A3), CN32.b23 (A3), RA2.2 (R1)
573-A4: 10H1.8 (I8), CN31.a22 (A4), CN32.a22 (A4), RA2.3 (R2)
573-A5: 10H1.7 (I7), CN31.b22 (A5), CN32.b22 (A5), RA2.4 (R3)
573-A6: 10H1.6 (I6), CN31.a21 (A6), CN32.a21 (A6), RA2.5 (R4)
573-A7: 10H1.5 (I5), CN31.b21 (A7), CN32.b21 (A7), RA2.6 (R5)
573-A12: CN31.a20 (A12), CN32.a20 (A12)
573-A13: CN31.b20 (A13), CN32.b20 (A13)
573-A14: CN31.a19 (A14), CN32.a19 (A14)
573-A15: CN31.b19 (A15), CN32.b19 (A15)
573-A20: CN31.a18 (A20), CN32.a18 (A20)
573-A21: CN31.b18 (A21), CN32.b18 (A21)
573-A22: CN31.a17 (A22), CN32.a17 (A22)
573-A23: CN31.b17 (A23), CN32.b17 (A23)
573-D0: CN31.a32 (D0), CN32.a32 (D0), RA3.2 (R1), U1.17 (I3b)
573-D1: CN31.b32 (D1), CN32.b32 (D1), RA3.3 (R2), U1.15 (I2b)
573-D2: CN31.a31 (D2), CN32.a31 (D2), RA3.4 (R3), U1.13 (I1b)
573-D3: CN31.b31 (D3), CN32.b31 (D3), RA3.5 (R4), U1.11 (I0b)
573-D4: CN31.a30 (D4), CN32.a30 (D4), RA3.6 (R5), U1.8 (I3a)
573-D5: CN31.b30 (D5), CN32.b30 (D5), RA3.7 (R6), U1.6 (I2a)
573-D6: CN31.a29 (D6), CN32.a29 (D6), RA3.8 (R7), U1.4 (I1a)
573-D7: CN31.b29 (D7), CN32.b29 (D7), RA3.9 (R8), U1.2 (I0a)
573-D8: CN31.a28 (D8), CN32.a28 (D8)
573-D9: CN31.b28 (D9), CN32.b28 (D9)
573-D10: CN31.a27 (D10), CN32.a27 (D10)
573-D11: CN31.b27 (D11), CN32.b27 (D11)
573-D12: CN31.a26 (D12), CN32.a26 (D12)
573-D13: CN31.b26 (D13), CN32.b26 (D13)
573-D14: CN31.a25 (D14), CN32.a25 (D14)
573-D15: CN31.b25 (D15), CN32.b25 (D15)
+3V3: CN31.a36 (+3V3), CN31.a37 (+3V3), CN31.a38 (+3V3), CN31.a39 (+3V3), CN31.a40 (+3V3), CN31.b36 (+3V3), CN31.b37 (+3V3), CN31.b38 (+3V3), CN31.b39 (+3V3), CN31.b40 (+3V3), CN32.a36 (+3V3), CN32.a37 (+3V3), CN32.a38 (+3V3), CN32.a39 (+3V3), CN32.a40 (+3V3), CN32.b36 (+3V3), CN32.b37 (+3V3), CN32.b38 (+3V3), CN32.b39 (+3V3), CN32.b40 (+3V3), R11.2, R14.2, RA2.1 (common), RA3.1 (common)
+5V: 10H1.20 (VCC), C6.1, C7.1, C8.1, C10.1, C14.1, C15.1, C17.1, C18.1, CN31.a1 (+5V), CN31.a2 (+5V), CN31.a3 (+5V), CN31.a4 (+5V), CN31.a5 (+5V), CN31.b1 (+5V), CN31.b2 (+5V), CN31.b3 (+5V), CN31.b4 (+5V), CN31.b5 (+5V), CN32.a1 (+5V), CN32.a2 (+5V), CN32.a3 (+5V), CN32.a4 (+5V), CN32.a5 (+5V), CN32.b1 (+5V), CN32.b2 (+5V), CN32.b3 (+5V), CN32.b4 (+5V), CN32.b5 (+5V), R12.2, R13.2, RA4.1 (common), RA5.1 (common), RA7.1 (common), RN6.1 (common), U1.20 (VCC), U3.20 (VCC), U9.16 (VCC), U14.20 (VCC), U34.20 (VCC)
DATA-0: U1.3 (O3b), U3.3 (D0), U9.4 (D0), U14.3 (D0), U34.3 (D0)
DATA-1: U1.5 (O2b), U3.4 (D1), U9.5 (D1), U14.4 (D1), U34.4 (D1)
DATA-2: U1.7 (O1b), U3.7 (D2), U9.12 (D2), U14.7 (D2), U34.7 (D2)
DATA-3: U1.9 (O0b), U3.8 (D3), U9.13 (D3), U14.8 (D3), U34.8 (D3)
DATA-4: U1.12 (O3a), U3.13 (D4), U14.13 (D4), U34.13 (D4)
DATA-5: U1.14 (O2a), U3.14 (D5), U14.14 (D5), U34.14 (D5)
DATA-6: U1.16 (O1a), U3.17 (D6), U14.17 (D6), U34.17 (D6)
DATA-7: U1.18 (O0a), U3.18 (D7), U14.18 (D7), U34.18 (D7)
DREQ5: CN31.a14 (DREQ5), CN32.a14 (DREQ5)
DREQ5-2: CN31.b12 (DREQ5), CN32.b12 (DREQ5)
EXP-15: CN31.b15 (N/C), CN32.b15 (N/C)
GND: 10H1.10 (GND), 10H1.11 (I10/~OE), C6.2, C7.2, C8.2, C10.2, C14.2, C15.2, C17.2, C18.2, CN31.a8 (GND), CN31.a9 (GND), CN31.a11 (GND), CN31.a13 (GND), CN31.a33 (GND), CN31.a34 (GND), CN31.a35 (GND), CN31.b7 (GND), CN31.b9 (GND), CN31.b11 (GND), CN31.b13 (GND), CN31.b33 (GND), CN31.b34 (GND), CN31.b35 (GND), CN32.a8 (GND), CN32.a9 (GND), CN32.a11 (GND), CN32.a13 (GND), CN32.a33 (GND), CN32.a34 (GND), CN32.a35 (GND), CN32.b7 (GND), CN32.b9 (GND), CN32.b11 (GND), CN32.b13 (GND), CN32.b33 (GND), CN32.b34 (GND), CN32.b35 (GND), JP1.1 (A), JP2.1 (A), U1.1 (OEa), U1.10 (GND), U1.19 (OEb), U3.10 (GND), U9.8 (GND), U14.10 (GND), U34.10 (GND)
IRQ10: CN31.a16 (IRQ10), CN32.a16 (IRQ10)
IRQ10-2: CN31.b16 (IRQ10), CN32.b16 (IRQ10)
ISOLATED-COMMON: CN35.10, CN36.6, FL1.2, FL2.2, FL3.2, FL4.2, FL5.2, FL6.2, FL7.2, FL8.2, FL9.2, FL10.2, FL11.2, FL12.2, FL13.2, FL14.2, FL15.2, FL16.2, FL17.2, FL18.2, FL19.2, FL20.2, FL21.2, FL22.2, FL23.2, FL24.2, FL25.2, FL26.2, FL27.2, FL28.2, FL29.2, FL30.2, FL31.2, FL32.2, JP3.1 (A)
unnamed: 3A1.1, RA7.2 (R1)
unnamed: 3A1.2, U9.15 (Q3)
unnamed: 3A1.3, 3B1.3, 3C1.3, 3D1.3, C33.1, C34.1, C35.1, C36.1, FL32.1
unnamed: 3A1.4, C33.2, FL28.1
unnamed: 3B1.1, RA7.3 (R2)
unnamed: 3B1.2, U9.10 (Q2)
unnamed: 3B1.4, C34.2, FL29.1
unnamed: 3C1.1, RA7.4 (R3)
unnamed: 3C1.2, U9.7 (Q1)
unnamed: 3C1.4, C35.2, FL30.1
unnamed: 3D1.1, RA7.5 (R4)
unnamed: 3D1.2, U9.2 (Q0)
unnamed: 3D1.4, C36.2, FL31.1
unnamed: 3E1.1, RN6.2 (R1)
unnamed: 3E1.2, U34.19 (Q7)
unnamed: 3E1.3, 3F1.3, 3G1.3, 3H1.3, 3J1.3, 3K1.3, 3L1.3, 3M1.3, C13.1, C16.1, C19.1, C20.1, C21.1, C22.1, C23.1, C24.1, FL18.1
unnamed: 3E1.4, C13.2, FL10.1
unnamed: 3F1.1, RN6.3 (R2)
unnamed: 3F1.2, U34.2 (Q0)
unnamed: 3F1.4, C16.2, FL11.1
unnamed: 3G1.1, RN6.4 (R3)
unnamed: 3G1.2, U34.16 (Q6)
unnamed: 3G1.4, C19.2, FL12.1
unnamed: 3H1.1, RN6.5 (R4)
unnamed: 3H1.2, U34.5 (Q1)
unnamed: 3H1.4, C20.2, FL13.1
unnamed: 3J1.1, RN6.6 (R5)
unnamed: 3J1.2, U34.15 (Q5)
unnamed: 3J1.4, C21.2, FL14.1
unnamed: 3K1.1, RN6.7 (R6)
unnamed: 3K1.2, U34.6 (Q2)
unnamed: 3K1.4, C22.2, FL15.1
unnamed: 3L1.1, RN6.8 (R7)
unnamed: 3L1.2, U34.12 (Q4)
unnamed: 3L1.4, C23.2, FL16.1
unnamed: 3M1.1, RN6.9 (R8)
unnamed: 3M1.2, U34.9 (Q3)
unnamed: 3M1.4, C24.2, FL17.1
unnamed: 3P1.1, RA5.2 (R1)
unnamed: 3P1.2, U14.19 (Q7)
unnamed: 3P1.3, 3Q1.3, 3R1.3, 3S1.3, 3T1.3, 3U1.3, 3V1.3, 3W1.3, C1.1, C2.1, C3.1, C4.1, C5.1, C9.1, C11.1, C12.1, FL9.1
unnamed: 3P1.4, C1.2, FL1.1
unnamed: 3Q1.1, RA5.3 (R2)
unnamed: 3Q1.2, U14.2 (Q0)
unnamed: 3Q1.4, C2.2, FL2.1
unnamed: 3R1.1, RA5.4 (R3)
unnamed: 3R1.2, U14.16 (Q6)
unnamed: 3R1.4, C3.2, FL3.1
unnamed: 3S1.1, RA5.5 (R4)
unnamed: 3S1.2, U14.5 (Q1)
unnamed: 3S1.4, C4.2, FL4.1
unnamed: 3T1.1, RA5.6 (R5)
unnamed: 3T1.2, U14.15 (Q5)
unnamed: 3T1.4, C5.2, FL5.1
unnamed: 3U1.1, RA5.7 (R6)
unnamed: 3U1.2, U14.6 (Q2)
unnamed: 3U1.4, C9.2, FL6.1
unnamed: 3V1.1, RA5.8 (R7)
unnamed: 3V1.2, U14.12 (Q4)
unnamed: 3V1.4, C11.2, FL7.1
unnamed: 3W1.1, RA5.9 (R8)
unnamed: 3W1.2, U14.9 (Q3)
unnamed: 3W1.4, C12.2, FL8.1
unnamed: 6AA1.1, RA4.9 (R8)
unnamed: 6AA1.2, U3.9 (Q3)
unnamed: 6AA1.4, C32.2, FL26.1
unnamed: 6T1.1, RA4.2 (R1)
unnamed: 6T1.2, U3.19 (Q7)
unnamed: 6AA1.3, 6T1.3, 6U1.3, 6V1.3, 6W1.3, 6X1.3, 6Y1.3, 6Z1.3, C25.1, C26.1, C27.1, C28.1, C29.1, C30.1, C31.1, C32.1, FL27.1
unnamed: 6T1.4, C25.2, FL19.1
unnamed: 6U1.1, RA4.3 (R2)
unnamed: 6U1.2, U3.2 (Q0)
unnamed: 6U1.4, C26.2, FL20.1
unnamed: 6V1.1, RA4.4 (R3)
unnamed: 6V1.2, U3.16 (Q6)
unnamed: 6V1.4, C27.2, FL21.1
unnamed: 6W1.1, RA4.5 (R4)
unnamed: 6W1.2, U3.5 (Q1)
unnamed: 6W1.4, C28.2, FL22.1
unnamed: 6X1.1, RA4.6 (R5)
unnamed: 6X1.2, U3.15 (Q5)
unnamed: 6X1.4, C29.2, FL23.1
unnamed: 6Y1.1, RA4.7 (R6)
unnamed: 6Y1.2, U3.6 (Q2)
unnamed: 6Y1.4, C30.2, FL24.1
unnamed: 6Z1.1, RA4.8 (R7)
unnamed: 6Z1.2, U3.12 (Q4)
unnamed: 6Z1.4, C31.2, FL25.1
unnamed: CN33.1, CN33.10, FL27.3
unnamed: CN33.2, FL19.3
unnamed: CN33.3, FL20.3
unnamed: CN33.4, FL21.3
unnamed: CN33.5, FL22.3
unnamed: CN33.6, FL23.3
unnamed: CN33.7, FL24.3
unnamed: CN33.8, FL25.3
unnamed: CN33.9, FL26.3
unnamed: CN34.1, CN34.10, FL9.3
unnamed: CN34.2, FL1.3
unnamed: CN34.3, FL2.3
unnamed: CN34.4, FL3.3
unnamed: CN34.5, FL4.3
unnamed: CN34.6, FL5.3
unnamed: CN34.7, FL6.3
unnamed: CN34.8, FL7.3
unnamed: CN34.9, FL8.3
unnamed: CN35.1, FL18.3
unnamed: CN35.2, FL10.3
unnamed: CN35.3, FL11.3
unnamed: CN35.4, FL12.3
unnamed: CN35.5, FL13.3
unnamed: CN35.6, FL14.3
unnamed: CN35.7, FL15.3
unnamed: CN35.8, FL16.3
unnamed: CN35.9, FL17.3
unnamed: CN36.1, FL32.3
unnamed: CN36.2, FL28.3
unnamed: CN36.3, FL29.3
unnamed: CN36.4, FL30.3
unnamed: CN36.5, FL31.3
unnamed: H1.1, JP1.2 (B)
unnamed: H2.1, JP2.2 (B)
unnamed: H3.1, JP3.2 (B)
U3-CP: 10H1.13 (IO7), U3.11 (Cp)
U9-CP: 10H1.16 (IO4), U9.9 (Cp)
U14-CP: 10H1.14 (IO6), U14.11 (Cp)
U34-CP: 10H1.15 (IO5), U34.11 (Cp)
~EXP1-2: CN31.b14 (~EXP1), CN32.b14 (~EXP1)
~EXP1: CN31.a12 (~EXP1), CN32.a12 (~EXP1)
~EXP2: 10H1.1 (I1/CLK), CN31.a15 (~EXP2), CN32.a15 (~EXP2), R12.1
~READ: 10H1.2 (I2), CN31.a6 (~READ), CN32.a6 (~READ), R14.1
~RESET2: CN31.b10 (~RESET), CN32.b10 (~RESET)
~RESET: 10H1.4 (I4), CN31.a10 (~RESET), CN32.a10 (~RESET), R13.1, U3.1 (~Mr), U9.1 (~Mr), U14.1 (~Mr), U34.1 (~Mr)
~WR1: 10H1.3 (I3), CN31.b6 (~WR1), CN32.b6 (~WR1), R11.1
~WR2: CN31.a7 (~WR2), CN32.a7 (~WR2)

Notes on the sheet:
Connector 33
OUTPUT 4
Not populated on DDR version
Not populated (pass-thru?)
Connector CN36
On DDR this is the cab lighting output (Starts, marquee spots)
On DDR this is the Player 1 pad CCFLs and CPLD data
On DDR this is the Neon ouput
Connector CN34
OUTPUT 2
On DDR this is the Player 2 pad CCFLs and Stage IO board data
OUTPUT 1
OUTPUT 3 (Not always populated)
Connector CN35

Board: 2 copper layers, 125 parts (0 on the bottom side), 184 nets, no tracks yet.

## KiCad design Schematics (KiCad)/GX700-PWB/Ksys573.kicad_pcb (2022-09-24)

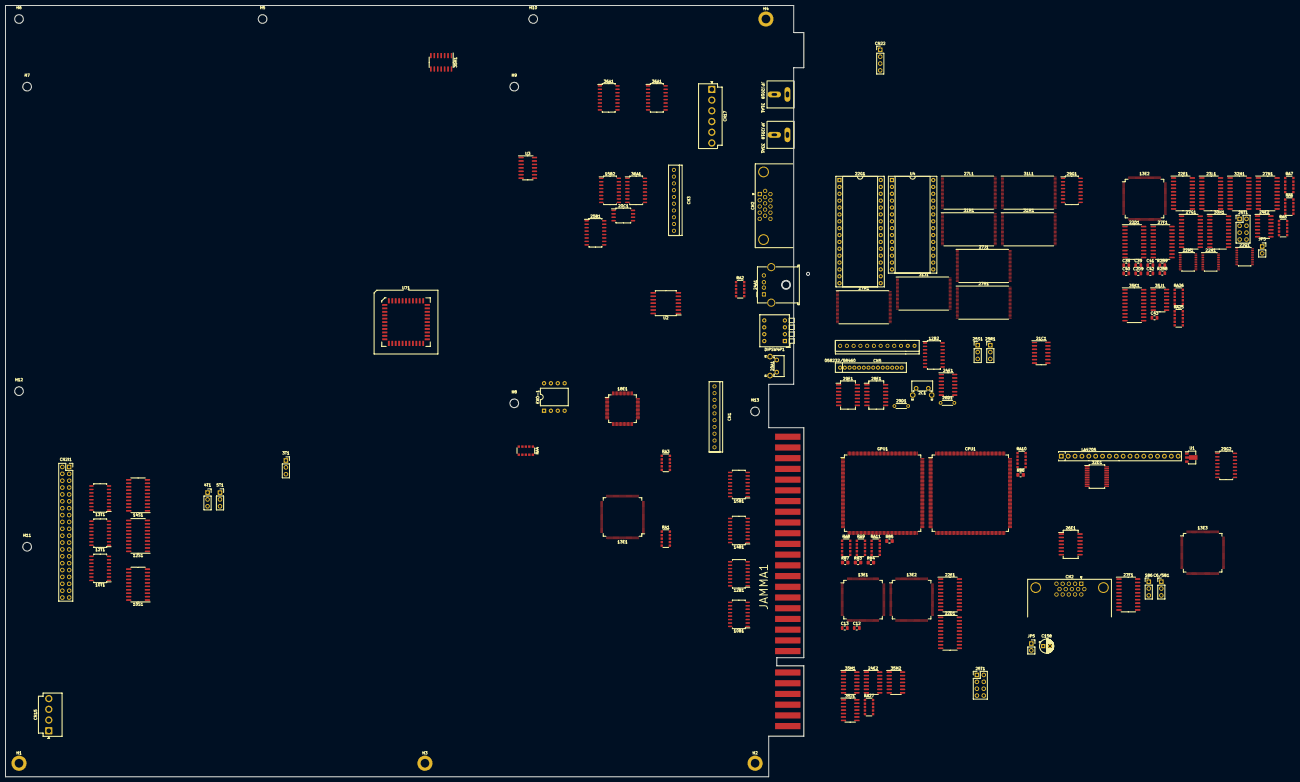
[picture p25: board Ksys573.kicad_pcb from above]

Board: 4 copper layers, 295.0 x 285.0 mm, 145 parts (0 on the bottom side), 416 nets, no tracks yet.

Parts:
2C1: EVQ-PC1; SW_Tactile_SPST_Angled_PTS645Vx58-2LFS
3T1, 4T1, 5T1: EMI_Filter_LCL; PinSocket_1x03_P2.54mm_Vertical
10B1, 10T1, 12B1, 12B2, 12T1, 13T1, 14B1, 15B1, 15B2, 25B1, 36A1, 36A1#2, 36A1#3: ZBDS5101-8PT; SOIC-16_4.55x10.3mm_P1.27mm
10S1, 12S1, 14S1: 74LS245; SO-20_5.3x12.6mm_P1.27mm
13E1, 13E1#2, 13E2, 13E2#2, 13E3: KONAMI_056879; TQFP-120_14x14mm_P0.4mm
18E1: HD6433640; TQFP-64_10x10mm_P0.5mm
20A1: SW_Push; SW_Tactile_SPST_Angled_PTS645Vx58-2LFS
20C1: MAX485E; SOIC-8_5.23x5.23mm_P1.27mm
21C1, 35J1#2: 74LS74; SO-14_3.9x8.65mm_P1.27mm
22D1, 22D1#2, 22E1, 22E1#2, 27F1, 27F1#2, 27G1, 35K1: 74LS273; SO-20_5.3x12.6mm_P1.27mm
22G1: 27C040; DIP-32_W15.24mm_Socket
22M1, 22N1, 22Q1: 74LCX245; SSOP-20_4.4x6.5mm_P0.65mm
23L1, 27N1, 30N1, 32N1: 74F245; SO-20_5.3x12.6mm_P1.27mm
24A1: USB_A; USB_A_Molex_67643_Horizontal
24E1, 24E2, 24E2#2: 74LS14; SO-14_3.9x8.65mm_P1.27mm
25R1: U102; PinHeader_1x03_P2.54mm_Vertical
25S1: U101; PinHeader_1x03_P2.54mm_Vertical
25T1, 25T1#2: S240; PinHeader_2x04_P2.54mm_Vertical
26D1, 29D1: ZBF503D-00; R_Axial_DIN0204_L3.6mm_D1.6mm_P5.08mm_Horizontal
26E1: 74LS74; SO-14_5.3x10.2mm_P1.27mm
27H1, 27J1, 27L1, 27M1, 31H1, 31J1, 31L1, 31M1: 29F016-TSOP-SP; TSOP-I-48_18.4x12mm_P0.5mm
28E1, 29E1: 74LS07; SO-14_5.3x10.2mm_P1.27mm
29G1, 29G2: 74LS139; SOIC-16_4.55x10.3mm_P1.27mm
31A1: LINE L-OUT; RCA
32D1: SM5877AM; SSOP-24_5.3x8.2mm_P0.65mm
33A1: LINE R-OUT; RCA
35H1, 35H1#2, 35H2, 35J1: 74LS125; SO-14_3.9x8.65mm_P1.27mm
058232/58460: KONAMI-058232; KONAMI-SIP-14
C6/5B1: EMI222; PinHeader_1x03_P2.54mm_Vertical
C12, C13, C38, C39, C40, C41, C42, C43, C209: 10n; C_0805_2012Metric
C158: 10M16E; CP_Radial_D5.0mm_P2.50mm
CN1, CN3: B10PSHF1A; JST_NH_B10P_SHD
CN2, CN2#2: VGA-DSUB15; DSUB-15-HD_Female_Horizontal_P2.29x1.98mm_EdgePinOffset8.35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
CN2I1: ATA-IDE; PinSocket_2x20_P2.54mm_Vertical
CN5: B12PSHF1A; JST_NH_B12P_SHD
CN15: B4P-VH; JST_VH_B4P-VH-B_1x04_P3.96mm_Vertical
CN17: B6P-VH; JST_VH_B6P-VH-B_1x06_P3.96mm_Vertical
CN22: BS4PSHF1AA; PinHeader_1x04_P2.54mm_Vertical
CPU1: CXD8530CQ; LQFP-208_28x28mm_P0.5mm
DIPSW4P1: SW_DIP_x04; SW_DIP_SPSTx04_Piano_10.8x11.72mm_W7.62mm_P2.54mm
EXO-1: 14.7456MHz; DIP-8_W10.16mm
GPU1: CXD8561CQ; LQFP-208_28x28mm_P0.5mm
H1, H2, H3, H4: MountingHole_Pad; MountingHole_3.2mm_M3_DIN965_Pad
H5, H6, H7, H8, H9, H10, H11, H12, H13: MountingHole; MountingHole_3.2mm_M3
JAMMA1: JAMMA
JP5, JP5#2: Jumper_NO_Small; PinSocket_1x02_P2.54mm_Vertical
LA4705: LA4705; SIP18_Housing
R83, R84, R85, R86, R87: 220; R_0805_2012Metric_Pad1.20x1.40mm_HandSolder
R288: 100; R_0805_2012Metric
R289: 470; R_0805_2012Metric
RA1, RA2, RA3, RA4: 2.2k; R_Array_Convex_5x1206
RA5, RA6, RA7, RA25, RA26, RA27: 4.7k; R_Array_Convex_5x1206
RA8, RA9, RA10, RA11: 472; R_Array_Convex_5x1206
S86: Conn_01x03; PinHeader_1x03_P2.54mm_Vertical
U1: L78L05_SOT89; SOT-89-3
U2: ADC0834; SOIC-14W_7.5x9mm_P1.27mm
U3: 74LS74; SO-14_3.9x8.65mm_P1.27mm
U4: M48T58Y; DIP-28_W15.24mm_Socket
U71: 22J-X700A1 XC9536; PLCC-44_SMD-Socket

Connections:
13E-59: 13E1.59, 13E1#2.59
13E-PIN17: 13E1.17, 13E3.17
18E-17: 13E1.49, 13E1#2.49, 18E1.17 (P60)
18E-18: 13E1.50, 13E1#2.50, 18E1.18 (P61)
18E-34: 18E1.34 (P73), 21C1.5 (Q)
18E-35: 13E3.95, 18E1.35 (P74/TMRIV), 21C1.9 (Q)
18E-36: 13E3.96, 18E1.36 (P75/TMCIV)
18E-54: 18E1.54 (P14/PWM), 21C1.11 (C)
21C-1: 18E1.53 (P10/TMOW), 21C1.1 (~R)
22D-2: 18E1.39 (P80/FTCI), 22D1.2, 22D1#2.2 (Q0)
22D-5: 18E1.40 (P81/FTOA), 22D1.5, 22D1#2.5 (Q1)
22D-6: 18E1.41 (P82/FTOB), 22D1.6, 22D1#2.6 (Q2)
22D-9: 18E1.42 (P83/FTIA), 22D1.9, 22D1#2.9 (Q3)
22D-12: 18E1.43 (P84/FTIB), 22D1.12, 22D1#2.12 (Q4)
22D-15: 18E1.44 (P85/FTIC), 22D1.15, 22D1#2.15 (Q5)
22D-16: 18E1.45 (P86/FTID), 22D1.16, 22D1#2.16 (Q6)
22D-19: 18E1.46 (P87), 22D1.19, 22D1#2.19 (Q7)
22E-2: 18E1.1 (PB1/AN1), 22E1.2, 22E1#2.2 (Q0)
22E-5: 18E1.2 (PB0/AN0), 22E1.5, 22E1#2.5 (Q1)
22E-6: 18E1.64 (PB2/AN2), 22E1.6, 22E1#2.6 (Q2)
22E-9: 18E1.63 (PB3/AN3), 22E1.9, 22E1#2.9 (Q3)
22E-12: 18E1.62 (PB4/AN4), 22E1.12, 22E1#2.12 (Q4)
22E-15: 18E1.61 (PB5/AN5), 22E1.15, 22E1#2.15 (Q5)
22E-16: 18E1.60 (PB6/AN6), 22E1.16, 22E1#2.16 (Q6)
22E-19: 18E1.59 (PB7/AN7), 22E1.19, 22E1#2.19 (Q7)
22M-13: 25T1.4, 25T1.5, 25T1#2.4, 25T1#2.5
24E-13: 24E2.13, 24E2#2.13, 27G1.16 (Q6)
25T-6: 25T1.3, 25T1.6
25T-7: 25T1.2, 25T1.7
25T-8: 25T1.1, 25T1.8
27G-2: 27G1.2 (Q0), 29G1.14
27G-5: 27G1.5 (Q1), 29G1.13
27G-12: 27G1.12 (Q4), 29G1.2, 29G2.2 (A0)
27G-15: 27G1.15 (Q5), 29G1.3, 29G2.3 (A1)
29G-5: 29G1.5, 29G2.5 (O1)
29G-6: 25R1.2, 25R1.3, 29G1.6, 29G2.6 (O2)
35J-5: 13E3.97, 35J1#2.5 (Q)
35J-9: 13E3.98, 35J1#2.9 (Q), RA26.6 (R5)
058232-4: 13E1.83, 13E3.84, 058232/58460.4 (CC-IN2)
058232-5: 13E1.84, 13E3.85, 058232/58460.5 (CC-IN1)
+3V3: 22M1.20 (VCC), 22N1.20 (VCC), 22Q1.20 (VCC), RA8.5 (common), RA8.10 (common), RA9.5 (common), RA9.10 (common), RA10.5 (common), RA10.10 (common), RA11.5 (common), RA11.10 (common)
+5V: 13E1.16, 13E1.46, 13E1.60, 13E1.85, 13E1.120, 13E2.106, 22D1.20, 22E1.20, 27F1.20, 35J1.12, C41.1, C42.1
+12V: 3T1.1, 058232/58460.1 (COINC-FB), CN17.5, CN17.6
/IDE/IDE-A0: 13T1.14, CN2I1.35
/IDE/IDE-A1: 13T1.12, CN2I1.33
/IDE/IDE-A2: 13T1.13, CN2I1.36
/IDE/IDE-D0: 12T1.10, CN2I1.17
/IDE/IDE-D1: 12T1.12, CN2I1.15
/IDE/IDE-D2: 12T1.14, CN2I1.13
/IDE/IDE-D3: 12T1.16, CN2I1.11
/IDE/IDE-D4: 10T1.10, CN2I1.9
/IDE/IDE-D5: 10T1.12, CN2I1.7
/IDE/IDE-D6: 10T1.14, CN2I1.5
/IDE/IDE-D7: 10T1.16, CN2I1.3
/IDE/IDE-D8: 10T1.15, CN2I1.4
/IDE/IDE-D9: 10T1.13, CN2I1.6
/IDE/IDE-D10: 10T1.11, CN2I1.8
/IDE/IDE-D11: 10T1.9, CN2I1.10
/IDE/IDE-D12: 12T1.15, CN2I1.12
/IDE/IDE-D13: 12T1.13, CN2I1.14
/IDE/IDE-D14: 12T1.11, CN2I1.16
/IDE/IDE-D15: 12T1.9, CN2I1.18
/IDE/IDE-READ: 13T1.11, CN2I1.25
/IDE/IDE-WRITE: 13T1.10, CN2I1.23
/IO-DATA-0: 13E1.62, 22E1.3, 27F1.3
/IO-DATA-1: 13E1.63, 22E1.4, 27F1.4
/IO-DATA-2: 13E1.64, 22E1.7, 27F1.7
/IO-DATA-3: 13E1.65, 22E1.8, 27F1.8
/IO-DATA-4: 13E1.66, 22E1.13, 27F1.13
/IO-DATA-5: 13E1.67, 22E1.14, 27F1.14
/IO-DATA-6: 13E1.68, 22E1.17, 27F1.17
/IO-DATA-7: 13E1.69, 22E1.18, 27F1.18
/IO-DATA-8: 13E1.10, 22D1.3
/IO-DATA-9: 13E1.72, 22D1.4
/IO-DATA-10: 13E1.73, 22D1.7
/IO-DATA-11: 13E1.74, 22D1.8
/IO-DATA-12: 13E1.75, 22D1.13
/IO-DATA-13: 13E1.76, 22D1.14
/IO-DATA-14: 13E1.77, 22D1.17
/IO-DATA-15: 13E1.78, 22D1.18
/PCCARD (PCMCIA)/IO-AD-0: 25S1.2, 25S1.3
/ROM/IO-ADDR-0: 22G1.12 (A0), 27H1.30 (A0), 27J1.30 (A0), 27L1.30 (A0), 27M1.30 (A0), 31H1.30 (A0), 31J1.30 (A0), 31L1.30 (A0), 31M1.30 (A0)
/ROM/IO-ADDR-1: 22G1.11 (A1), 27H1.29 (A1), 27J1.29 (A1), 27L1.29 (A1), 27M1.29 (A1), 31H1.29 (A1), 31J1.29 (A1), 31L1.29 (A1), 31M1.29 (A1)
/ROM/IO-ADDR-2: 22G1.10 (A2), 27H1.28 (A2), 27J1.28 (A2), 27L1.28 (A2), 27M1.28 (A2), 31H1.28 (A2), 31J1.28 (A2), 31L1.28 (A2), 31M1.28 (A2)
/ROM/IO-ADDR-3: 22G1.9 (A3), 27H1.27 (A3), 27J1.27 (A3), 27L1.27 (A3), 27M1.27 (A3), 31H1.27 (A3), 31J1.27 (A3), 31L1.27 (A3), 31M1.27 (A3)
/ROM/IO-ADDR-4: 22G1.8 (A4), 27H1.22 (A4), 27J1.22 (A4), 27L1.22 (A4), 27M1.22 (A4), 31H1.22 (A4), 31J1.22 (A4), 31L1.22 (A4), 31M1.22 (A4)
/ROM/IO-ADDR-5: 22G1.7 (A5), 27H1.21 (A5), 27J1.21 (A5), 27L1.21 (A5), 27M1.21 (A5), 31H1.21 (A5), 31J1.21 (A5), 31L1.21 (A5), 31M1.21 (A5)
/ROM/IO-ADDR-6: 22G1.6 (A6), 27H1.20 (A6), 27J1.20 (A6), 27L1.20 (A6), 27M1.20 (A6), 31H1.20 (A6), 31J1.20 (A6), 31L1.20 (A6), 31M1.20 (A6)
/ROM/IO-ADDR-7: 22G1.5 (A7), 27H1.19 (A7), 27J1.19 (A7), 27L1.19 (A7), 27M1.19 (A7), 31H1.19 (A7), 31J1.19 (A7), 31L1.19 (A7), 31M1.19 (A7)
/ROM/IO-ADDR-8: 22G1.27 (A8), 27H1.18 (A8), 27J1.18 (A8), 27L1.18 (A8), 27M1.18 (A8), 31H1.18 (A8), 31J1.18 (A8), 31L1.18 (A8), 31M1.18 (A8)
/ROM/IO-ADDR-9: 22G1.26 (A9), 27H1.17 (A9), 27J1.17 (A9), 27L1.17 (A9), 27M1.17 (A9), 31H1.17 (A9), 31J1.17 (A9), 31L1.17 (A9), 31M1.17 (A9)
/ROM/IO-ADDR-10: 22G1.23 (A10), 27H1.16 (A10), 27J1.16 (A10), 27L1.16 (A10), 27M1.16 (A10), 31H1.16 (A10), 31J1.16 (A10), 31L1.16 (A10), 31M1.16 (A10)
/ROM/IO-ADDR-11: 22G1.25 (A11), 27H1.15 (A11), 27J1.15 (A11), 27L1.15 (A11), 27M1.15 (A11), 31H1.15 (A11), 31J1.15 (A11), 31L1.15 (A11), 31M1.15 (A11)
/ROM/IO-ADDR-12: 22G1.4 (A12), 27H1.10 (A12), 27J1.10 (A12), 27L1.10 (A12), 27M1.10 (A12), 31H1.10 (A12), 31J1.10 (A12), 31L1.10 (A12), 31M1.10 (A12)
/ROM/IO-ADDR-13: 22G1.28 (A13), 27H1.9 (A13), 27J1.9 (A13), 27L1.9 (A13), 27M1.9 (A13), 31H1.9 (A13), 31J1.9 (A13), 31L1.9 (A13), 31M1.9 (A13)
/ROM/IO-ADDR-14: 22G1.29 (A14), 27H1.8 (A14), 27J1.8 (A14), 27L1.8 (A14), 27M1.8 (A14), 31H1.8 (A14), 31J1.8 (A14), 31L1.8 (A14), 31M1.8 (A14)
/ROM/IO-ADDR-15: 22G1.3 (A15), 27H1.7 (A15), 27J1.7 (A15), 27L1.7 (A15), 27M1.7 (A15), 31H1.7 (A15), 31J1.7 (A15), 31L1.7 (A15), 31M1.7 (A15)
/ROM/IO-ADDR-16: 22G1.2 (A16), 27H1.6 (A16), 27J1.6 (A16), 27L1.6 (A16), 27M1.6 (A16), 31H1.6 (A16), 31J1.6 (A16), 31L1.6 (A16), 31M1.6 (A16)
/ROM/IO-ADDR-17: 22G1.30 (A17), 27H1.5 (A17), 27J1.5 (A17), 27L1.5 (A17), 27M1.5 (A17), 31H1.5 (A17), 31J1.5 (A17), 31L1.5 (A17), 31M1.5 (A17)
/ROM/IO-ADDR-18: 22G1.31 (A18), 27H1.4 (A18), 27J1.4 (A18), 27L1.4 (A18), 27M1.4 (A18), 31H1.4 (A18), 31J1.4 (A18), 31L1.4 (A18), 31M1.4 (A18)
/ROM/IO-ADDR-19: 27H1.3 (A19), 27J1.3 (A19), 27L1.3 (A19), 27M1.3 (A19), 31H1.3 (A19), 31J1.3 (A19), 31L1.3 (A19), 31M1.3 (A19)
/ROM/IO-ADDR-20: 27H1.46 (A20), 27J1.46 (A20), 27L1.46 (A20), 27M1.46 (A20), 31H1.46 (A20), 31J1.46 (A20), 31L1.46 (A20), 31M1.46 (A20)
/ROM/IO-DATA-0: 22G1.13 (D0), 31H1.31 (D0), 31J1.31 (D0), 31L1.31 (D0), 31M1.31 (D0), U4.11 (DQ0)
/ROM/IO-DATA-1: 22G1.14 (D1), 31H1.32 (D1), 31J1.32 (D1), 31L1.32 (D1), 31M1.32 (D1), U4.12 (DQ1)
/ROM/IO-DATA-2: 22G1.15 (D2), 31H1.33 (D2), 31J1.33 (D2), 31L1.33 (D2), 31M1.33 (D2), U4.13 (DQ2)
/ROM/IO-DATA-3: 22G1.17 (D3), 31H1.34 (D3), 31J1.34 (D3), 31L1.34 (D3), 31M1.34 (D3), U4.15 (DQ3)
/ROM/IO-DATA-4: 22G1.18 (D4), 31H1.38 (D4), 31J1.38 (D4), 31L1.38 (D4), 31M1.38 (D4), U4.16 (DQ4)
/ROM/IO-DATA-5: 22G1.19 (D5), 31H1.39 (D5), 31J1.39 (D5), 31L1.39 (D5), 31M1.39 (D5), U4.17 (DQ5)
/ROM/IO-DATA-6: 22G1.20 (D6), 31H1.40 (D6), 31J1.40 (D6), 31L1.40 (D6), 31M1.40 (D6), U4.18 (DQ6)
/ROM/IO-DATA-7: 22G1.21 (D7), 31H1.41 (D7), 31J1.41 (D7), 31L1.41 (D7), 31M1.41 (D7), U4.19 (DQ7)
/ROM/IO-DATA-8: 27H1.31 (D0), 27J1.31 (D0), 27L1.31 (D0), 27M1.31 (D0)
/ROM/IO-DATA-9: 27H1.32 (D1), 27J1.32 (D1), 27L1.32 (D1), 27M1.32 (D1)
/ROM/IO-DATA-10: 27H1.33 (D2), 27J1.33 (D2), 27L1.33 (D2), 27M1.33 (D2)
/ROM/IO-DATA-11: 27H1.34 (D3), 27J1.34 (D3), 27L1.34 (D3), 27M1.34 (D3)
/ROM/IO-DATA-12: 27H1.38 (D4), 27J1.38 (D4), 27L1.38 (D4), 27M1.38 (D4)
/ROM/IO-DATA-13: 27H1.39 (D5), 27J1.39 (D5), 27L1.39 (D5), 27M1.39 (D5)
/ROM/IO-DATA-14: 27H1.40 (D6), 27J1.40 (D6), 27L1.40 (D6), 27M1.40 (D6)
/ROM/IO-DATA-15: 27H1.41 (D7), 27J1.41 (D7), 27L1.41 (D7), 27M1.41 (D7)
/Security Cart/CART-7.37MHz: 35H1.3, 35H1#2.3
/Security Cart/CART-RTS: 35H1.11, 35H1#2.11
ADC-CLK: 13E1.80, 13E3.83, U2.12 (CLK)
ADC-DIN: 13E1.79, 13E3.79, U2.13 (DIN)
ADC-DOUT: 13E1.89, 13E3.89, U2.10 (DOUT)
ADC-SARS: 13E1.92, 13E3.80, 13E3.92, U2.11 (SARS)
ADC-~CS: 13E1.82, 13E3.82, U2.2 (~CS)
BUS-~RD: 10S1.1 (A->B), 12S1.1 (A->B), U4.22 (~OE), U71.18 (M13)
BUS-~WR: 27H1.44 (~WE), 27J1.44 (~WE), 27L1.44 (~WE), 27M1.44 (~WE), 31H1.44 (~WE), 31J1.44 (~WE), 31L1.44 (~WE), 31M1.44 (~WE), U4.27 (~WR), U71.25 (M17)
CART-20: 35H1.9, 35H2.9, 35K1.2 (Q0), RA25.9 (R8)
CART-29: 35J1#2.3 (C), RA26.4 (R4)
CART-30: 35J1.13, 35J1#2.13 (~R), RA26.7 (R6)
CART-33: 13E2.38, 13E2#2.38, RA27.1 (R1)
CART-34: 13E2.37, 13E2#2.37, RA27.2 (R2)
CART-35: 13E2.36, 13E2#2.36, RA27.3 (R3)
CART-36: 13E2.35, 13E2#2.35, RA27.4 (R4)
CART-37: 13E2.34, 13E2#2.34, RA27.9 (R8)
CART-38: 13E2.33, 13E2#2.33, RA27.8 (R7)
CART-39: 13E2.32, 13E2#2.32, RA27.7 (R6)
CART-40: 13E1.30, 13E1#2.30, RA27.6 (R5)
CN21-B6: 23L1.17 (B1), JP5.1, JP5#2.1
COIN1IN: 13E1.6, 13E3.6, RA1.2 (R2)
COIN2IN: 13E1.7, 13E3.7, RA1.8 (R7)
COIN-CNT1: 10B1.16, 058232/58460.3 (CC-OUT1)
COIN-CNT2: 10B1.15, 058232/58460.2 (CC-OUT2)
DAC-MUTE: 13E1.87, 13E3.87
DIP-1: 13E1.22, 13E1#2.22, DIPSW4P1.8
DIP-2: 13E1.23, 13E1#2.23, DIPSW4P1.7
DIP-3: 13E1.24, 13E1#2.24, DIPSW4P1.6
DIP-4: 13E1.25, 13E1#2.25, DIPSW4P1.5
DREQ5: 22M1.12 (B6), 25T1#2.3, 25T1#2.6
EXO-CLK: 18E1.8 (OSC1), 35H1.2, 35H1#2.2, EXO-1.2 (D)
EXP-A10: 13E1.90, 22D1.1, 22E1.1
EXT-OUT-LATCH: 27F1#2.11 (Cp), U71.43 (M4)
FLASH-CE0: 27H1.11 (~CE), 29G1.9, 31H1.11 (~CE)
FLASH-CE1: 27J1.11 (~CE), 29G1.10, 31J1.11 (~CE)
FLASH-CE2: 29G1.11, 31L1.11 (~CE)
FLASH-CE3: 27M1.11 (~CE), 29G1.12, 31M1.11 (~CE)
GND: 2C1.2, 3T1.2, 4T1.1, 4T1.2, 5T1.2, 10B1.13, 10S1.10 (GND), 12S1.10 (GND), 13E1.1, 13E1.11, 13E1.21, 13E1.41, 13E1.61, 13E1.71, 13E1.81, 13E1.91, 13E1.111, 13E1#2.21, 13E1#2.41, 13E1#2.51, 13E2.31, 13E2.101, 13E2#2.31, 13E3.1, 13E3.11, 13E3.61, 13E3.71, 13E3.81, 13E3.91, 13E3.101, 13E3.111, 14S1.10 (GND), 14S1.19 (CE), 15B1.9, 15B1.13, 15B2.9, 15B2.13, 18E1.3 (AVSS), 18E1.4 (TEST), 18E1.5 (X2), 18E1.7 (VSS), 20A1.2, 20C1.5 (GND), 22D1.10, 22D1#2.10 (GND), 22E1.10, 22E1#2.10 (GND), 22G1.16 (GND), 22G1.22 (~CE), 22M1.1 (A->B), 22M1.10 (GND), 22M1.17 (B1), 22M1.18 (B0), 22M1.19 (CE), 22N1.10 (GND), 22Q1.10 (GND), 23L1.10 (GND), 23L1.19 (CE), 25B1.9, 25B1.12, 25B1.16, 27F1.10, 27F1#2.10 (GND), 27G1.10 (GND), 27H1.35 (GND), 27H1.36 (GND), 27J1.35 (GND), 27J1.36 (GND), 27L1.35 (GND), 27L1.36 (GND), 27M1.35 (GND), 27M1.36 (GND), 27N1.10 (GND), 27N1.19 (CE), 29D1.1, 30N1.10 (GND), 30N1.19 (CE), 31H1.35 (GND), 31H1.36 (GND), 31J1.35 (GND), 31J1.36 (GND), 31L1.35 (GND), 31L1.36 (GND), 31M1.35 (GND), 31M1.36 (GND), 32N1.10 (GND), 32N1.19 (CE), 35H1.1, 35H1.4, 35H1.13, 35H1#2.1, 35H1#2.4, 35H1#2.13, 35K1.10 (GND), 36A1.14, 36A1.16, 36A1#2.14, 36A1#2.16, 36A1#3.14, 36A1#3.16, 058232/58460.6 (GND), 058232/58460.7 (GND), C6/5B1.2, C12.2, C13.2, C38.2, C39.2, C40.2, C41.2, C42.2, C43.2, C158.2, C209.2, CN2.0, CN2#2.0, CN2I1.2, CN2I1.19, CN2I1.22, CN2I1.24, CN2I1.26, CN2I1.30, CN2I1.40, CN17.3, CN17.4, CN22.4, DIPSW4P1.1, DIPSW4P1.2, DIPSW4P1.3, DIPSW4P1.4, EXO-1.4 (GND), EXO-1.5 (A), EXO-1.6 (B), EXO-1.7 (C), JAMMA1.A8 (COIN_LOCK1), JAMMA1.B8 (COIN_LOCK2), S86.2, U2.7 (GND), U2.8 (AGND), U4.14 (VSS), U71.10 (GND), U71.15 (TDI), U71.16 (TMS), U71.17 (TCK), U71.23 (GND), U71.30 (TDO), U71.31 (GND)
H8-TX-FLAG: 21C1.3 (C), U71.39 (I/O/GSR)
IDE-CS0: 13T1.15, 14S1.8 (A6), CN2I1.37, U71.2 (M1)
IDE-CS1: 13T1.16, 14S1.9 (A7), CN2I1.38, U71.3 (M2)
IDE-~RST: 14S1.2 (A0), 26E1.5 (Q)
IO-ADDR-0: 32N1.18 (B0), RA5.6 (R5)
IO-ADDR-1: 13E2.103, 13E3.103, 14S1.7 (A5), 32N1.17 (B1), RA5.4 (R4)
IO-ADDR-2: 13E2.104, 13E3.104, 14S1.5 (A3), 32N1.16 (B2), RA5.7 (R6)
IO-ADDR-3: 13E2.105, 13E3.105, 14S1.6 (A4), 32N1.15 (B3), RA5.3 (R3)
IO-ADDR-4: 32N1.14 (B4), RA5.8 (R7)
IO-ADDR-5: 32N1.13 (B5), RA5.2 (R2)
IO-ADDR-6: 32N1.12 (B6), RA5.9 (R8)
IO-ADDR-7: 32N1.11 (B7), RA5.1 (R1)
IO-ADDR-9: 30N1.17 (B1), RA6.4 (R4)
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

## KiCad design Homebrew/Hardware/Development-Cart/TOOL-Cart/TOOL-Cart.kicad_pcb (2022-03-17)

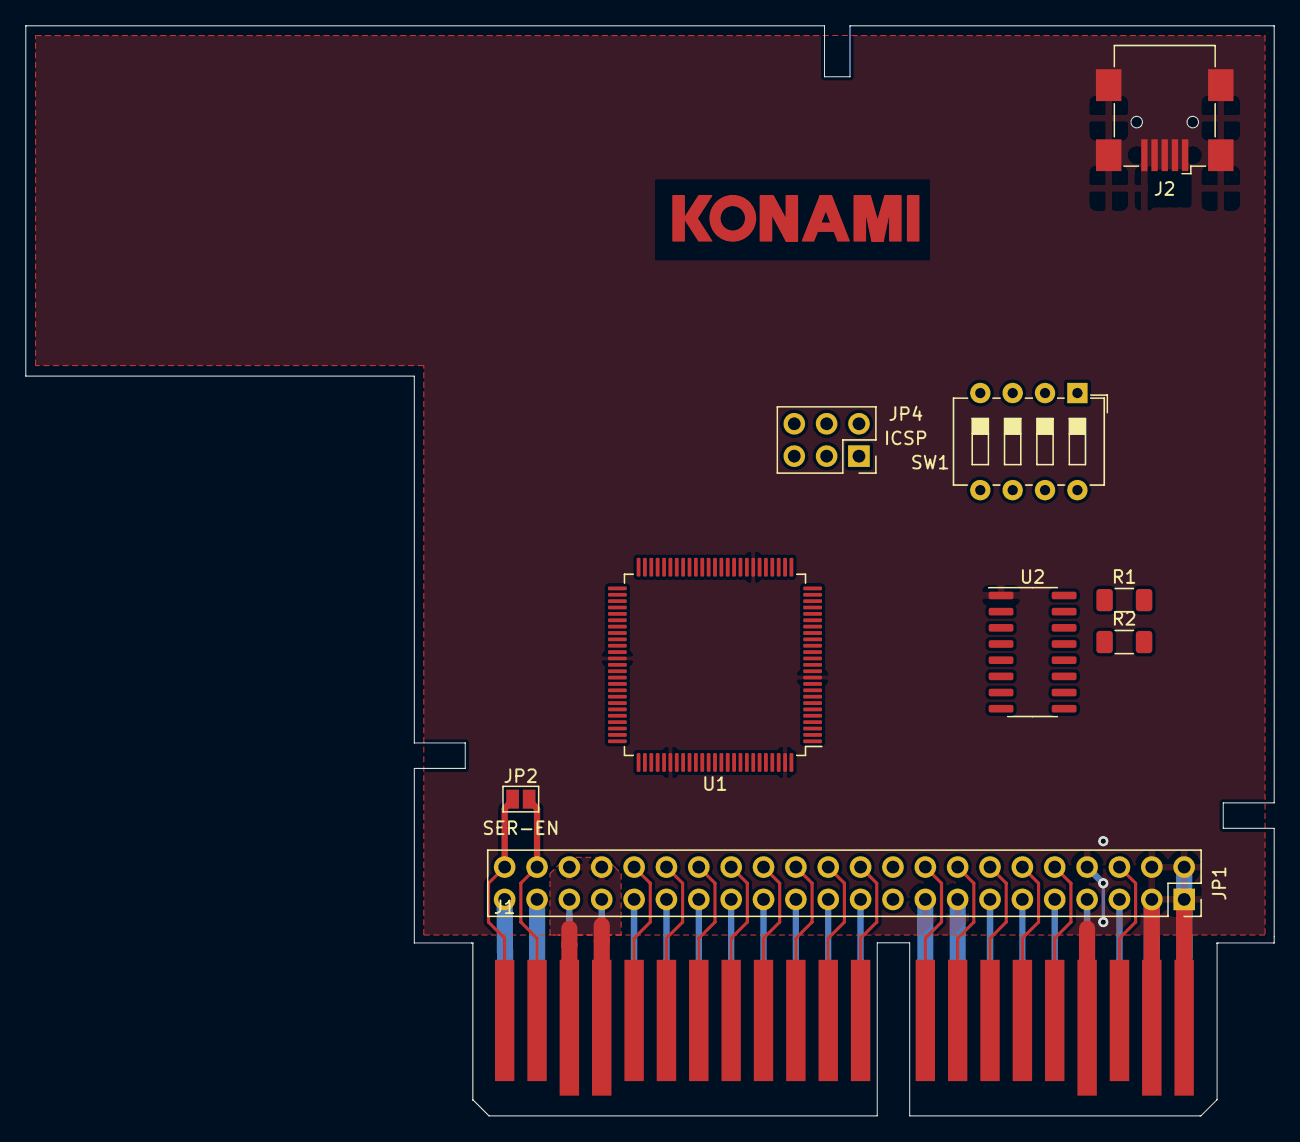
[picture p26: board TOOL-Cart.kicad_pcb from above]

Board: 2 copper layers, 98.0 x 85.6 mm, 10 parts (0 on the bottom side), 38 nets.

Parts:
J1: Security Cart Edge; Security_Cart
J2: USB_B_Mini; USB_Mini-B_Wuerth_65100516121_Horizontal
JP1: Cart Pins; PinSocket_2x22_P2.54mm_Vertical
JP2: S-EN; SolderJumper-2_P1.3mm_Open_Pad1.0x1.5mm
JP4: ATMEGA-ICSP; PinSocket_2x03_P2.54mm_Vertical
R1, R2: 22; R_1206_3216Metric_Pad1.30x1.75mm_HandSolder
SW1: SW_DIP_x04; SW_DIP_SPSTx04_Slide_6.7x11.72mm_W7.62mm_P2.54mm_LowProfile
U1: ATmega2560-16AU; TQFP-100_14x14mm_P0.5mm
U2: CH340C; SOIC-16_3.9x9.9mm_P1.27mm

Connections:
+5V: J1.21, J1.22, J1.41, J1.42, JP1.38, JP1.40, JP1.41, JP1.43, U2.16
CART-4: J1.4, JP1.7
CART-7: J1.7, JP1.13
CART-11: J1.11, JP1.21
CART-12: J1.12, JP1.23
CART-25: J1.25, JP1.6
CART-27: J1.27, JP1.10
CART-28: J1.28, JP1.12
CART-29: J1.29, JP1.14
CART-30: J1.30, JP1.16
CART-31: J1.31, JP1.18
GND: J1.1, J1.2, J1.8, J1.9, J1.23, J1.24, J1.26, J2.5, J2.6, JP1.1, JP1.2, JP1.3, JP1.4, JP1.8, JP1.15, JP1.17, U1.11, U1.32, U1.62, U1.81, U1.99, U2.1
INPUT-0: J1.13, JP1.25, U1.97
INPUT-1: J1.14, JP1.27, U1.96
INPUT-2: J1.15, JP1.29, U1.95
INPUT-3: J1.16, JP1.31, U1.94
INPUT-4: J1.17, JP1.33, U1.93
INPUT-5: J1.18, JP1.35, U1.92
INPUT-6: J1.19, JP1.37, U1.91
INPUT-7: J1.20, JP1.39, U1.90
unnamed: J2.2, R2.2
unnamed: J2.3, R1.2
unnamed: R1.1, U2.5
unnamed: R2.1, U2.6
unnamed: U1.10, U1.31, U1.61, U1.80
OUTPUT-0: J1.40, JP1.36, U1.89
OUTPUT-1: J1.39, JP1.34, U1.88
OUTPUT-2: J1.38, JP1.32, U1.87
OUTPUT-3: J1.37, JP1.30, U1.86
OUTPUT-4: J1.36, JP1.28, U1.85
OUTPUT-5: J1.35, JP1.26, U1.84
OUTPUT-6: J1.34, JP1.24, U1.83
OUTPUT-7: J1.33, JP1.22, U1.82
RX0: J1.5, JP1.9, U2.3
SEN-1: J1.44, JP1.44, JP2.1
SEN-2: J1.43, JP1.42, JP2.2
TX0: J1.6, JP1.11, U2.2
~DSR: J1.3, JP1.5

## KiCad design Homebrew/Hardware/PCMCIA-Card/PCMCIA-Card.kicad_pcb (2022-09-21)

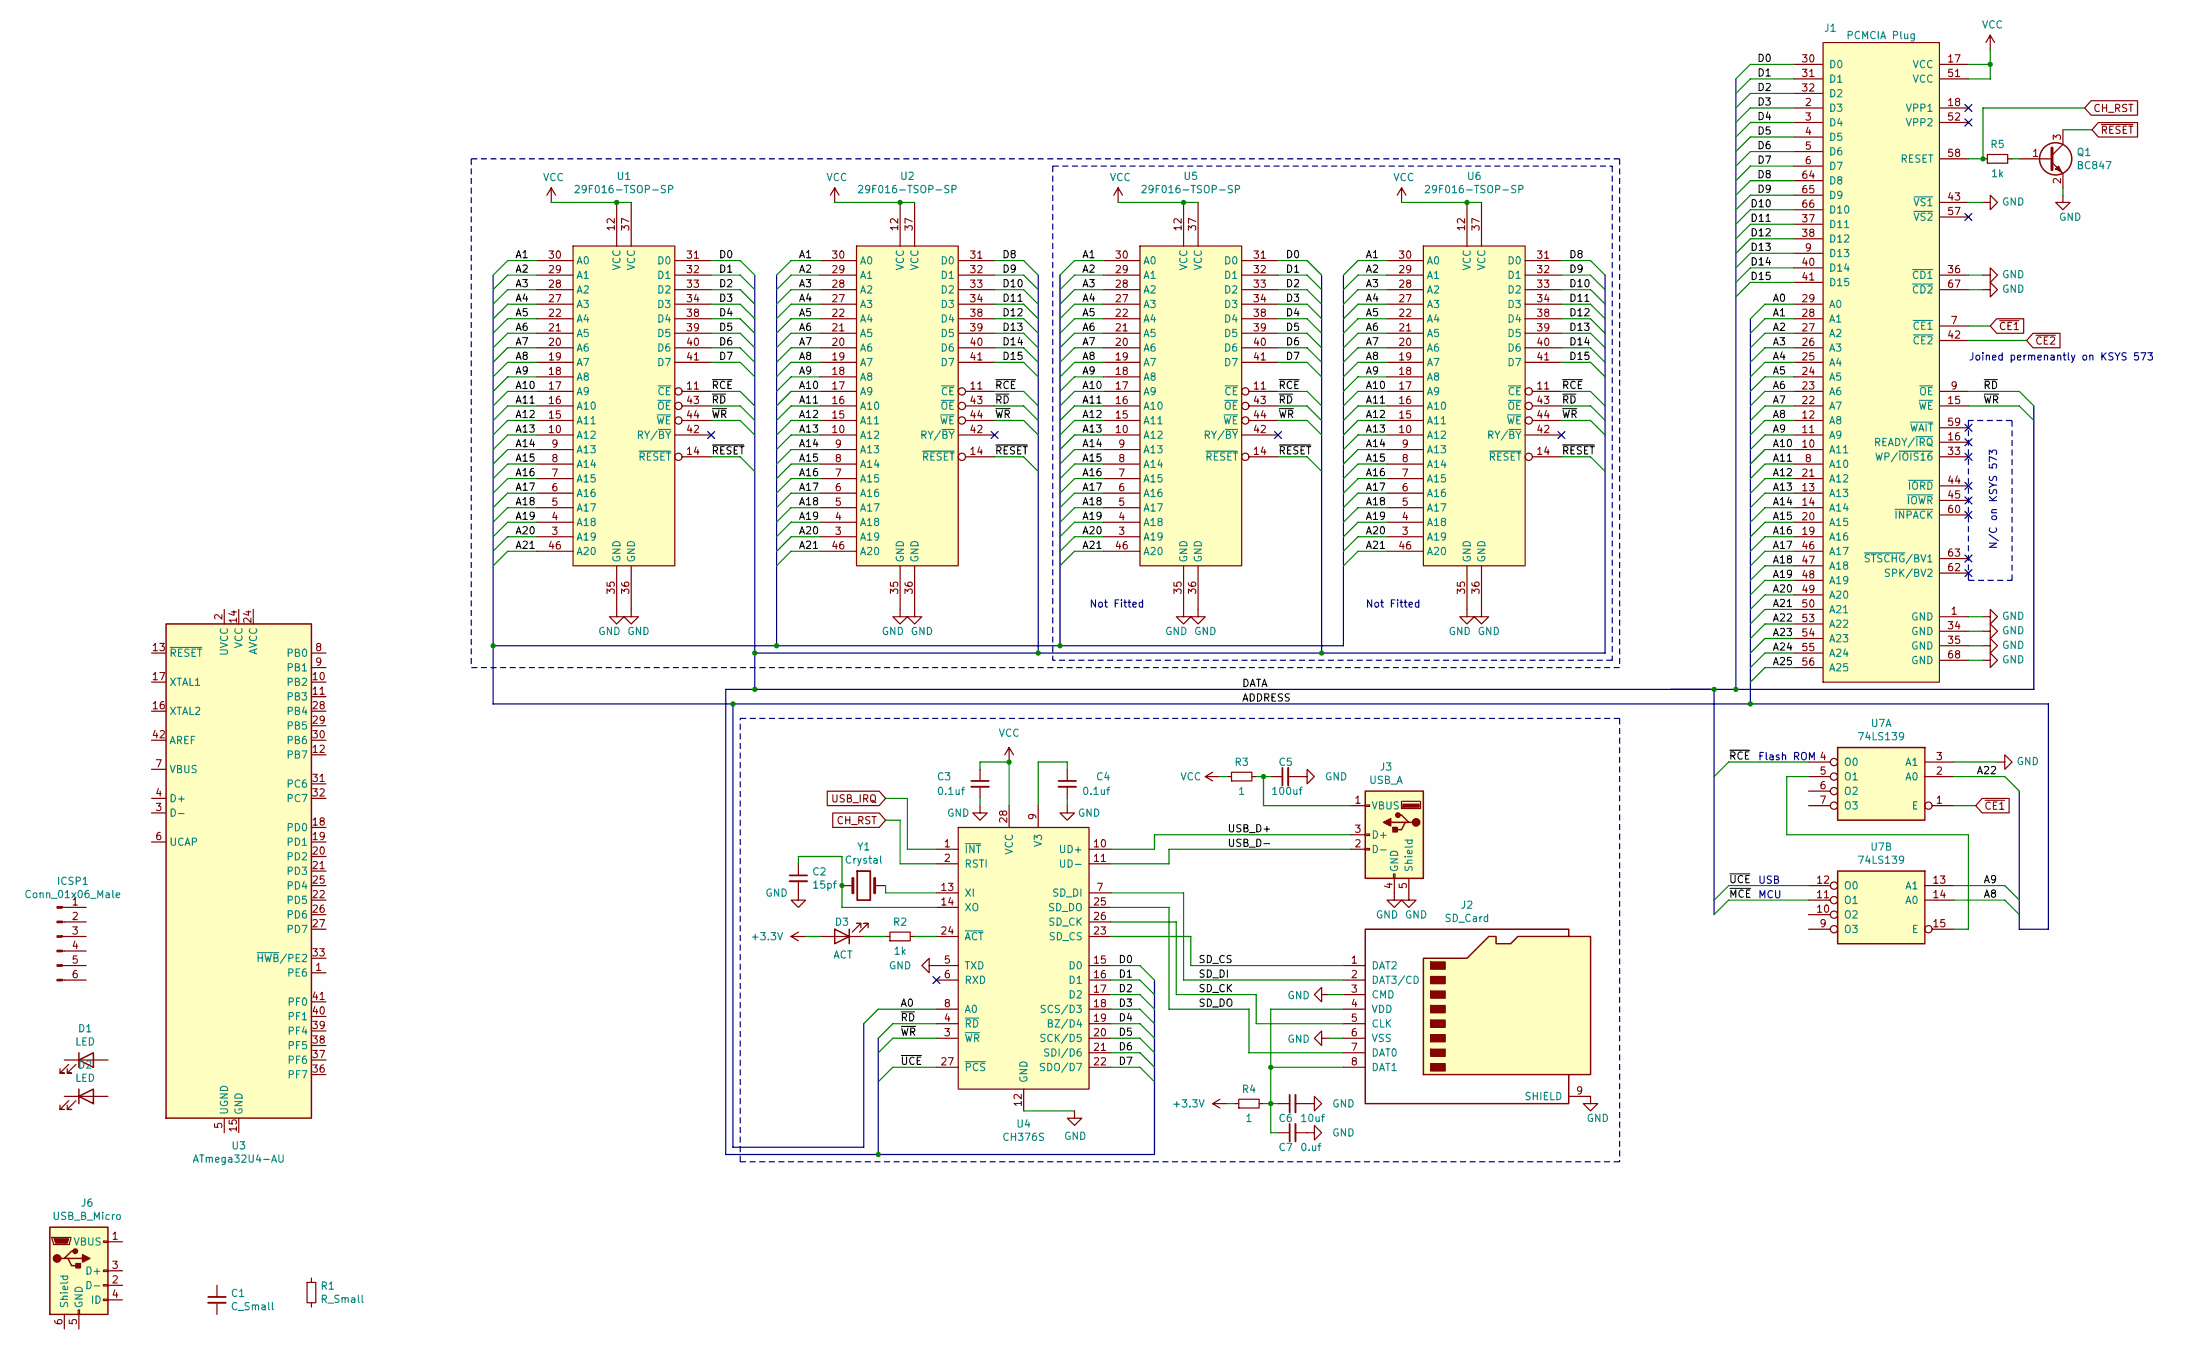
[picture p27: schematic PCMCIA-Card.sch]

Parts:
C1: C_Small; C_1206_3216Metric_Pad1.33x1.80mm_HandSolder
C2: 15pf; C_1206_3216Metric_Pad1.33x1.80mm_HandSolder
C3, C4: 0.1uf; C_1206_3216Metric_Pad1.33x1.80mm_HandSolder
C5: 100uf; C_1206_3216Metric_Pad1.33x1.80mm_HandSolder
C6: 10uf; C_1206_3216Metric_Pad1.33x1.80mm_HandSolder
C7: 0.uf; C_1206_3216Metric_Pad1.33x1.80mm_HandSolder
D1, D2: LED; LED_1206_3216Metric
D3: ACT; LED_1206_3216Metric
ICSP1: Conn_01x06_Male; PinHeader_2x03_P2.54mm_Vertical_SMD
J1: PCMCIA Plug; PCMCIA-Female
J2: SD_Card; microSD_HC_Hirose_DM3D-SF
J3: USB_A; USB_A_Molex_67643_Horizontal
J6: USB_B_Micro; USB_Micro-B_Wuerth_629105150521
Q1: BC847; SOT-23
R1: R_Small; R_1206_3216Metric_Pad1.30x1.75mm_HandSolder
R2, R5: 1k; R_1206_3216Metric_Pad1.30x1.75mm_HandSolder
R3, R4: 1; R_1206_3216Metric_Pad1.30x1.75mm_HandSolder
U1, U2, U5, U6: 29F016-TSOP-SP; TSOP-I-48_18.4x12mm_P0.5mm
U3: ATmega32U4-AU; TQFP-44_10x10mm_P0.8mm
U4: CH376S; SOIC-28W_7.5x17.9mm_P1.27mm
U7: 74LS139; SO-16_3.9x9.9mm_P1.27mm
Y1: Crystal; Crystal_SMD_5032-2Pin_5.0x3.2mm_HandSoldering

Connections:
+3V3: D3.2 (A), R4.1
/A0: J1.29 (A0), U4.8 (A0)
/A1: J1.28 (A1), U1.30 (A0), U2.30 (A0), U5.30 (A0), U6.30 (A0)
/A2: J1.27 (A2), U1.29 (A1), U2.29 (A1), U5.29 (A1), U6.29 (A1)
/A3: J1.26 (A3), U1.28 (A2), U2.28 (A2), U5.28 (A2), U6.28 (A2)
/A4: J1.25 (A4), U1.27 (A3), U2.27 (A3), U5.27 (A3), U6.27 (A3)
/A5: J1.24 (A5), U1.22 (A4), U2.22 (A4), U5.22 (A4), U6.22 (A4)
/A6: J1.23 (A6), U1.21 (A5), U2.21 (A5), U5.21 (A5), U6.21 (A5)
/A7: J1.22 (A7), U1.20 (A6), U2.20 (A6), U5.20 (A6), U6.20 (A6)
/A8: J1.12 (A8), U1.19 (A7), U2.19 (A7), U5.19 (A7), U6.19 (A7), U7.14 (A0)
/A9: J1.11 (A9), U1.18 (A8), U2.18 (A8), U5.18 (A8), U6.18 (A8), U7.13 (A1)
/A10: J1.10 (A11), U1.17 (A9), U2.17 (A9), U5.17 (A9), U6.17 (A9)
/A11: J1.8 (A10), U1.16 (A10), U2.16 (A10), U5.16 (A10), U6.16 (A10)
/A12: J1.21 (A12), U1.15 (A11), U2.15 (A11), U5.15 (A11), U6.15 (A11)
/A13: J1.13 (A13), U1.10 (A12), U2.10 (A12), U5.10 (A12), U6.10 (A12)
/A14: J1.14 (A14), U1.9 (A13), U2.9 (A13), U5.9 (A13), U6.9 (A13)
/A15: J1.20 (A15), U1.8 (A14), U2.8 (A14), U5.8 (A14), U6.8 (A14)
/A16: J1.19 (A16), U1.7 (A15), U2.7 (A15), U5.7 (A15), U6.7 (A15)
/A17: J1.46 (A17), U1.6 (A16), U2.6 (A16), U5.6 (A16), U6.6 (A16)
/A18: J1.47 (A18), U1.5 (A17), U2.5 (A17), U5.5 (A17), U6.5 (A17)
/A19: J1.48 (A19), U1.4 (A18), U2.4 (A18), U5.4 (A18), U6.4 (A18)
/A20: J1.49 (A20), U1.3 (A19), U2.3 (A19), U5.3 (A19), U6.3 (A19)
/A21: J1.50 (A21), U1.46 (A20), U2.46 (A20), U5.46 (A20), U6.46 (A20)
/A22: J1.53 (A22), U7.2 (A0)
/A23: J1.54 (A23)
/A24: J1.55 (A24)
/A25: J1.56 (A25)
/D0: J1.30 (D0), U1.31 (D0), U4.15 (D0), U5.31 (D0)
/D1: J1.31 (D1), U1.32 (D1), U4.16 (D1), U5.32 (D1)
/D2: J1.32 (D2), U1.33 (D2), U4.17 (D2), U5.33 (D2)
/D3: J1.2 (D3), U1.34 (D3), U4.18 (SCS/D3), U5.34 (D3)
/D4: J1.3 (D4), U1.38 (D4), U4.19 (BZ/D4), U5.38 (D4)
/D5: J1.4 (D5), U1.39 (D5), U4.20 (SCK/D5), U5.39 (D5)
/D6: J1.5 (D6), U1.40 (D6), U4.21 (SDI/D6), U5.40 (D6)
/D7: J1.6 (D7), U1.41 (D7), U4.22 (SDO/D7), U5.41 (D7)
/D8: J1.64 (D8), U2.31 (D0), U6.31 (D0)
/D9: J1.65 (D9), U2.32 (D1), U6.32 (D1)
/D10: J1.66 (D10), U2.33 (D2), U6.33 (D2)
/D11: J1.37 (D11), U2.34 (D3), U6.34 (D3)
/D12: J1.38 (D12), U2.38 (D4), U6.38 (D4)
/D14: J1.40 (D14), U2.40 (D6), U6.40 (D6)
/D15: J1.41 (D15), U2.41 (D7), U6.41 (D7)
/SD_CK: J2.5 (CLK), U4.26 (SD_CK)
/SD_CS: J2.1 (DAT2), U4.23 (SD_CS)
/SD_DI: J2.2 (DAT3/CD), U4.7 (SD_DI)
/SD_DO: J2.7 (DAT0), U4.25 (SD_DO)
/USB_D+: J3.3 (D+), U4.10 (UD+)
/USB_D-: J3.2 (D-), U4.11 (UD-)
/~MCE: U7.11 (O1)
/~RCE: U1.11 (~CE), U2.11 (~CE), U5.11 (~CE), U6.11 (~CE), U7.4 (O0)
/~UCE: U4.27 (~PCS), U7.12 (O0)
/~WR: J1.15 (~WE), U1.44 (~WE), U2.44 (~WE), U4.3 (~WR), U5.44 (~WE), U6.44 (~WE)
CH_RST: J1.58 (RESET), R5.1, U4.2 (RSTI)
unnamed: C2.1, U4.14 (XO), Y1.1
unnamed: C4.1, U4.9 (V3)
unnamed: C5.1, J3.1 (VBUS), R3.2
unnamed: C6.1, C7.1, J2.4 (VDD), J2.8 (DAT1), R4.2
unnamed: D3.1 (K), R2.1
unnamed: Q1.1 (B), R5.2
unnamed: R2.2, U4.24 (~ACT)
unnamed: U3.14 (VCC), U3.34 (VCC)
unnamed: U3.15 (GND), U3.23 (GND), U3.35 (GND), U3.43 (GND)
unnamed: U3.24 (AVCC), U3.44 (AVCC)
unnamed: U4.13 (XI), Y1.2
unnamed: U7.5 (O1), U7.15 (E)
USB_IRQ: U4.1 (~INT~)
VCC: C3.1, J1.17 (VCC), J1.51 (VCC), R3.1, U1.12 (VCC), U1.37 (VCC), U2.12 (VCC), U2.37 (VCC), U4.28 (VCC), U5.12 (VCC), U5.37 (VCC), U6.12 (VCC), U6.37 (VCC)
~CE1: J1.7 (~CE1), U7.1 (E)
~CE2: J1.42 (~CE2)
~RESET: Q1.3 (C), U1.14 (~RESET), U2.14 (~RESET), U5.14 (~RESET), U6.14 (~RESET)

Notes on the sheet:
MCU
USB
Flash ROM
Not Fitted
N/C on KSYS 573
Joined permenantly on KSYS 573

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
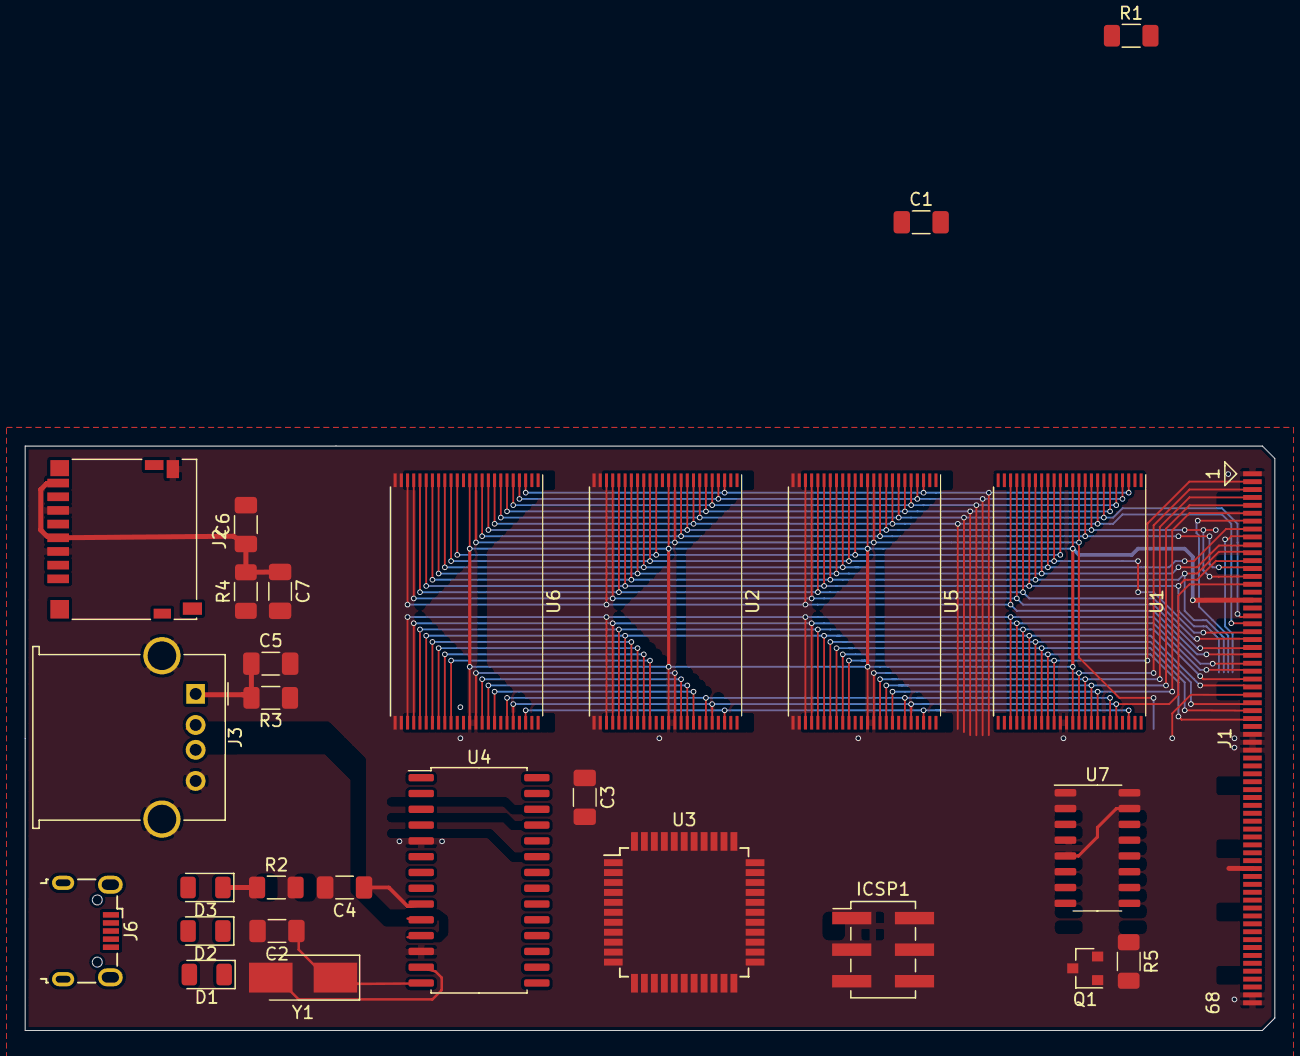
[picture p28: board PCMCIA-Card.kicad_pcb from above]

Board: 2 copper layers, 100.5 x 47.0 mm, 29 parts (0 on the bottom side), 67 nets.

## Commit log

2022-02-03 Initial Commit
    Not complete!!
    [573-IDE.sch, 573-PCMCIA.sch, Audio.sch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]
2022-02-04 Added GE675-PWB(A)
    IO Board for Fisherman's Bait 3
    [573-IDE.sch, 573-PCMCIA.sch, GE765-PWB.kicad_pcb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]
2022-02-08 Updated GE765
    [GE765-PWB.sch]
2022-02-08 50% Complete schematics
    [GE765-PWB.sch]
2022-02-08 Finished reel connector
    [GE765-PWB.sch]
2022-02-11 More CN31 connector labels
    [GE765-PWB.sch]
2022-02-14 Added mostly guesswork of GX700-PWB
    The guess is based on high resolution photos, but it's not that complicated so fairly confident it's enough to build a replica. PAL is likely just deciding with latch to clock on write.
    [GX700-PWB.kicad_pcb, GX700-PWB.sch]
2022-02-14 Added rough draft of Stage IO board
    [GN845-PWB.kicad_pcb, GN845-PWB.sch, GX700-PWB.sch]
2022-02-14 Added power input to GN845
    [GN845-PWB.sch]
2022-02-14 Small updates
    [GN845-PWB.sch]
2022-03-09 Updated Schematics
    PCMCIA is pinned out
    [573-IDE.sch, 573-PCCARD.sch, 573-PCMCIA.sch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]
2022-03-11 Fixed bugs
    IDE Retrace, PCMCIA checked
    [573-IDE.sch, 573-PCCARD.sch, H8MCU.sch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]
2022-03-12 Flash fixes, security cart done, most logic figured
    [573-IDE.sch, 573-PCCARD.sch, 573-ROM.sch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]
2022-03-15 573 specific mostly mapped
    [573-IDE.sch, 573-ROM.sch, H8MCU.sch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]
2022-03-17 Added 3D Models
    [Cart Slot V1.stl, Faceplate v1.stl, Ksys573.sch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]
2022-09-21 Big update to the schematics
    [573-IDE.kicad_sch, 573-IDE.sch, 573-PCCARD.kicad_sch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]
2022-09-24 Added Symbols, PSX page
    Added PSX CPU and GPU symbols, added a COH PSX skeleton schematic and also updated the JAMMA symbol and footprint as it was bad.
    [573-IDE.kicad_sch, 573-PCCARD.kicad_sch, Audio.kicad_sch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]
2022-10-16 A lot of fixes.
    Moved some libraries about to allow other schematics to share parts. 573 Expansion IO now has a proper symbol and part. JAE TX15 connector has a footprint. GX700 IO board has been fixed (output from chips was entirely wrong).
    [573-PCCARD.kicad_sch, GX700-PWB.kicad_sch, GX894-PWB.kicad_pcb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]
2022-10-16 Laid out GX700-PWB(F)
    Needs traces doing but the measurements are all there.
    [GX700-PWB.kicad_pcb, GX700-PWB.kicad_sch]
2022-10-21 Updated design
    [GN845-PWB.kicad_pcb]
2022-11-17 Updated IO Boards and descriptions
    [GN845-PWB.kicad_sch]
2022-11-23 Updated GN845(B)'s schematic
    The schematic wrongly claimed there was a seperate LIGHT-GND. This is not true, it was ground, only the outer mounting holes and the LCL filters have a seperate ground (or can have one)
    [GN845-PWB.kicad_sch]
2023-01-05 Started mapping out Digital IO board
    [GN845-PWB.kicad_pcb, GN845-PWB.kicad_sch, GX894-PWB.kicad_pcb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]
2023-02-05 General Fixes
    [573-IDE.kicad_sch, 573-PCCARD.kicad_sch, 573-ROM.kicad_sch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]
2023-03-15 Updated schematics
2025-11-19 Major board changes to give a rough render of the PCB
    [573-IDE.kicad_sch, 573-PCCARD.kicad_sch, 573-ROM.kicad_sch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]
2025-11-19 Major PCB changes to render a nicer 3D image
    [GX894-PWB.kicad_sch]

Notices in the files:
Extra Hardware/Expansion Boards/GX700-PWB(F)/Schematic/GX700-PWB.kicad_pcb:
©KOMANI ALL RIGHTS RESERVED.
